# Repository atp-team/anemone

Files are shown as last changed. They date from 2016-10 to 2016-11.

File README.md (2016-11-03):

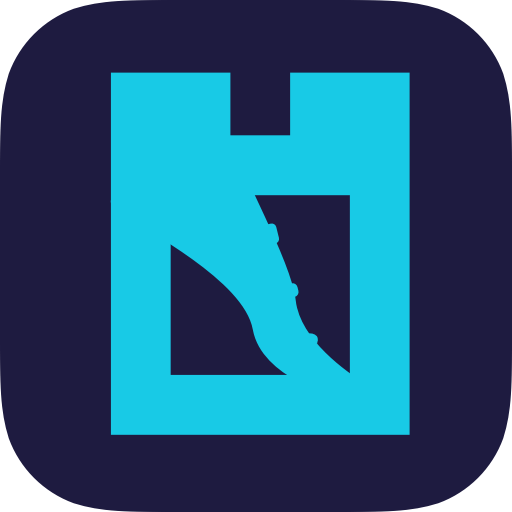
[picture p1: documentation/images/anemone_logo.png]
Anemone Platform


> "Look at you hacker, in order to use me, you must understand first." -- Anemone

## Introducing the Platform

Anemone is an open platform which allows you to experiment with *Internet of Things*. Anemone allows you to easily **build open hardware device** and to **create a simple apps** which will run *both in cloud and on mobile devices*.

First take a look at our website [http://www.anemone.cloud](http://www.anemone.cloud).

Then continue reading.

*[#anemoneCloud](https://twitter.com/hashtag/anemoneCloud)*

## Platform ecosystem

Anemone ecosystem consists of:

* **Anemone Overview** (you are reading it now)
* **Anemone Platform** which consists of:
  * [Anemome Cloud](http://www.anemone.cloud) 
  * **Anemone Mobile Client** iOS & Android apps (you can download them from [www.anemone.cloud](http://www.anemone.cloud))
  * [Anemone Tentacle](https://github.com/ceskasporitelna/anemone/blob/master/documentation/HowToBuildAnemoneTentacle.md) open hardware device you can build and 3D print
* [Anemone Documentation](https://github.com/ceskasporitelna/anemone/tree/master/documentation) where you can read everything you need to know
* [Anemone Toolkit](https://github.com/ceskasporitelna/anemone/tree/master/toolkit) which you need in order to create a Tentacle or build Anemone App
* [Anemone Apps Repository](https://github.com/ceskasporitelna/anemone/tree/master/apps)
* [Anemone Cloud Connectors List](https://github.com/ceskasporitelna/anemone/tree/master/connectors)

More information about the Anemone Platform are provided below.

## Platform architecture

Anemone has three main parts:

* Mobile Client
* Cloud
* Tentacle

**Mobile Client** is iOS and Android application which allows you to manage *Tentacles* and control *Anemone Apps*. You can download it for free from Apple AppStore and Google Play Store. Both links are on our website [http://www.anemone.cloud](http://www.anemone.cloud).

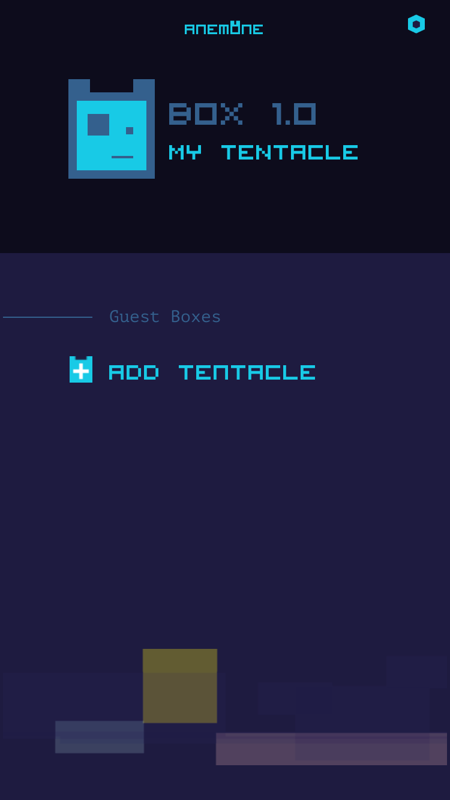
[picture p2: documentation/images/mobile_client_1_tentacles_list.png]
Anemone Mobile Client - List of Tentacles
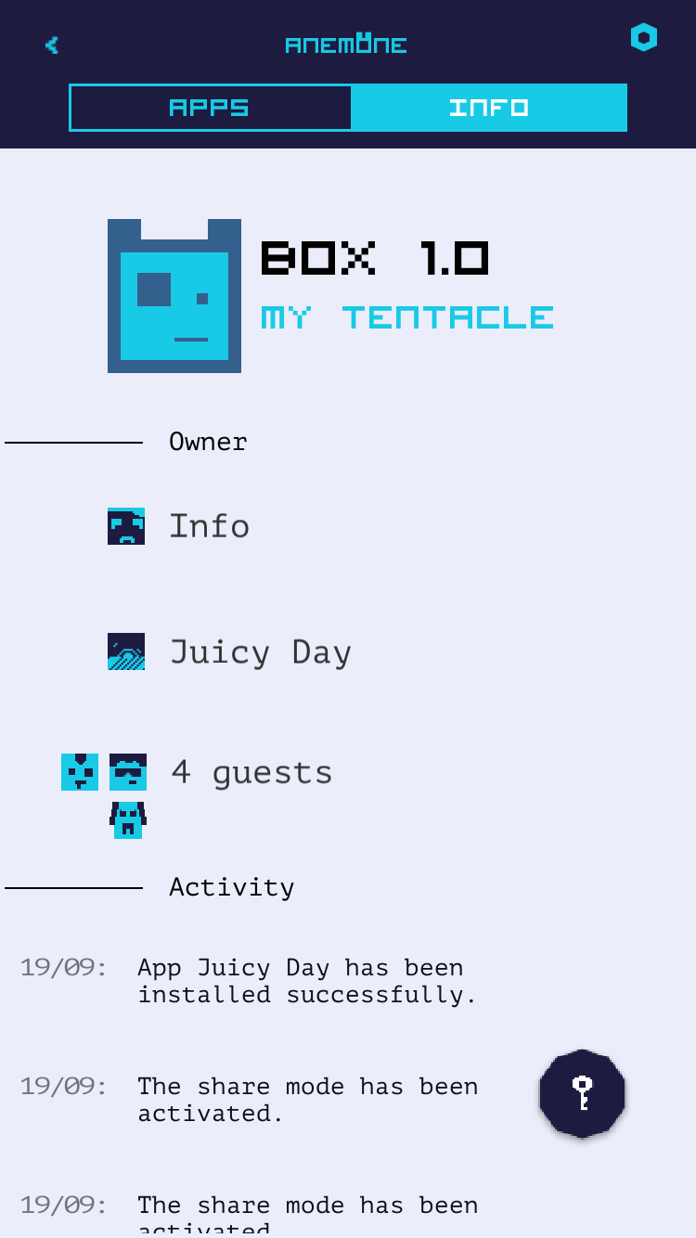
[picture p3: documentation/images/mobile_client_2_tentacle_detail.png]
Anemone Mobile Client - Tentacle Detail
 

**Cloud** is the final component of the platform which connects the Tentacles to the Mobile Client. But that is not all. The Anemone Cloud can connect both the Mobile Client and Tentacles to other API service on the internet using **Connectors**.

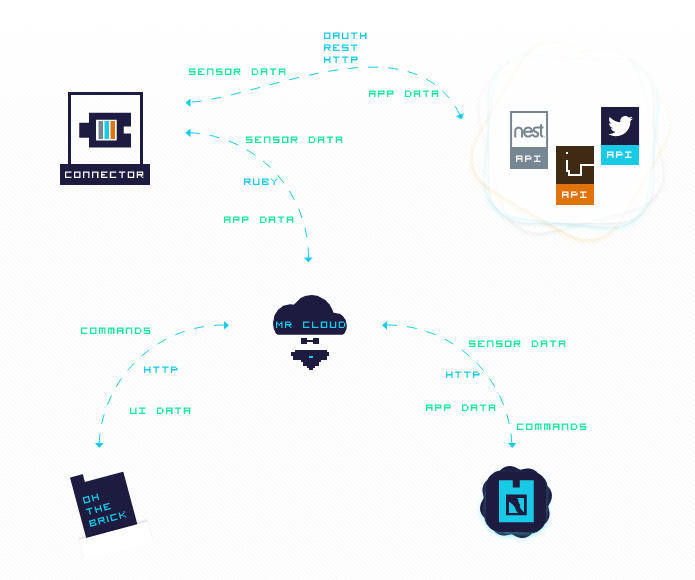
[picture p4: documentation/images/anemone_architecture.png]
Anemone Platform Architecture


**Tentacle** is open hardware device based on Arduino YÚN which is the *Internet of Things* part the our platform. You can either *connect as a guest* to a Tentacle of your friend, or you can *build your own* (which will recognize you as its master).

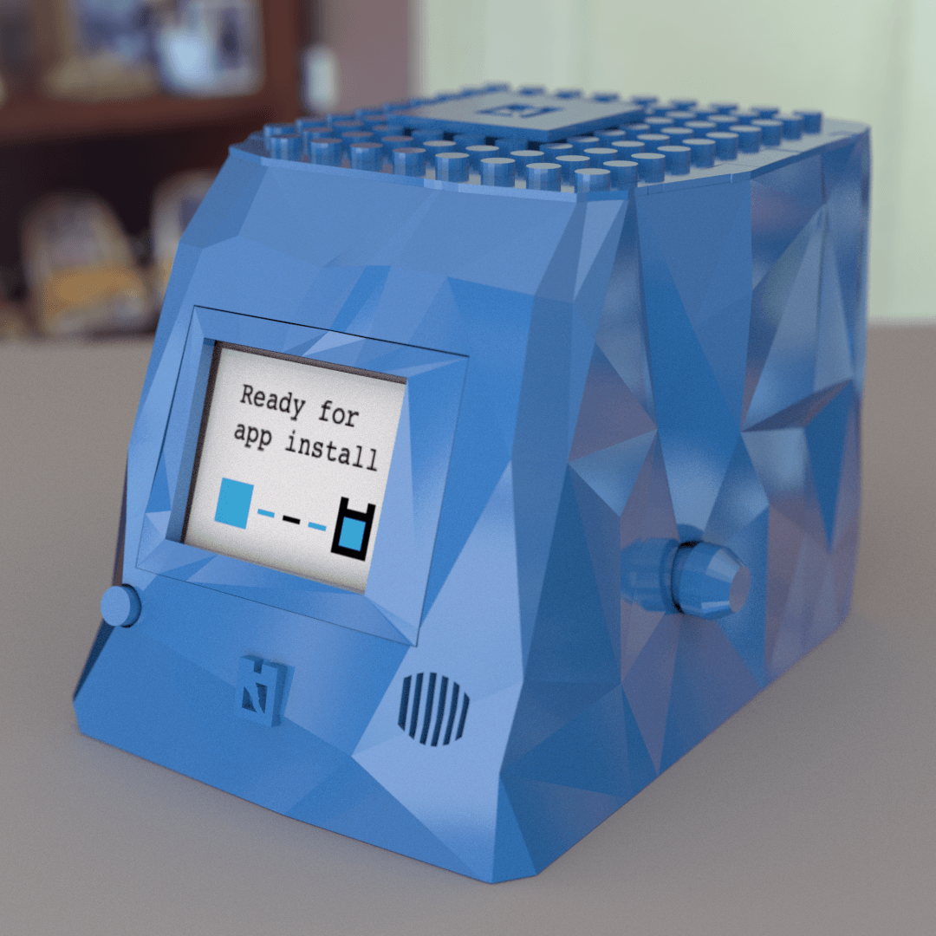
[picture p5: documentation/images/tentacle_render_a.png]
Anemone Tentacle - View from Right
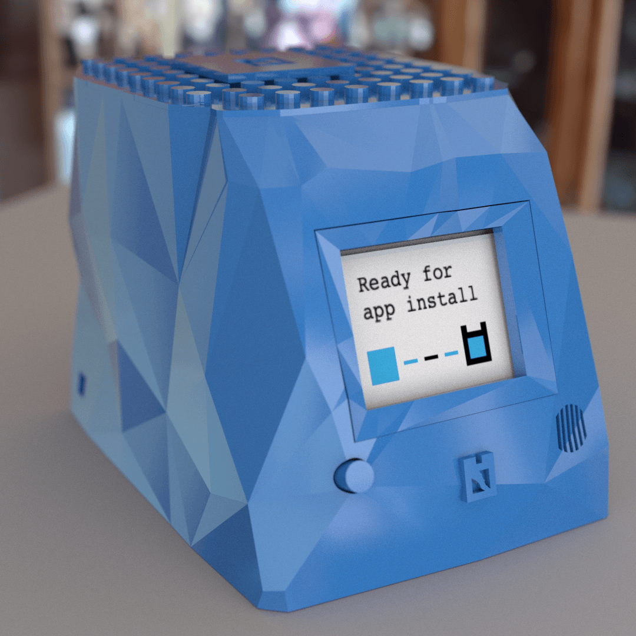
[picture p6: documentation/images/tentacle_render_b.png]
Anemone Tentacle - View from Left
 

The *Cloud*, *Mobile Client* and *Tentacle* together form a platform where **Anemone Apps** can run.

And *Anemone Apps* are here for you *to use them*, *to develop them* and mainly **to have some fun with them**.

## What can be achieved with the platform?

With Anemone Platform you can do the following:

* You can display textual information from the the Anemone Cloud on Tentacle display *(information is stored inside variables in the cloud component of Anemone app)*
* Tentacle can change value of variable of it's app cloud component (eg. when some button on the Tentacle is pressed or when some data is measured)
* You can create so called "Anemone Apps" which contains variables which can be shown on Tentacle display and/or in the Mobile Client app. You can let user enter some data using his mobile phone, adjust this data in the cloud and show result on the Tentacle. Or you can let user interact with the Tentacle and process this interaction in the cloud and show the result in the mobile app.
* The platform is done in a way that owner of a Tentacle can share it to his friend or change the running Anemone App using the OTA *(Over-The-Air)* update.

> The **Anemone Platform is completely OPEN**. Everybody can [become a user by signing up for free](http://www.anemone.cloud/users/sign_up). Every user can either receive a guest access or can [build his own](https://github.com/ceskasporitelna/anemone/blob/master/documentation/HowToBuildAnemoneTentacle.md) Tentacle. One can then install some apps from our [public repository of Anemone Apps](https://github.com/ceskasporitelna/anemone/tree/master/apps) or he can [create his own app](https://github.com/ceskasporitelna/anemone/blob/master/documentation/HowToMakeAnemoneApp.md).

## How it works? 

> Main goal of Anemone Platform is to provide a place where *Anemone Apps* can live.

Anemone App is a tiny piece of software which can be **built by you**. We have designed the Anemone platform in a way that it will be extremely easy for you to make new Anemone Apps.

### What is Anemone App?

Anemone app is every application which runs on the Anemone platform.

Every Anemone app has three components:

* Mobile User Interface
* Cloud Logic
* Tentacle User Interface and Logic

Every of these three components of an Anemone App runs in one part of Anemone platform:

* **Mobile User Interface** runs in the *Mobile Client* app
* **Cloud Logic** runs in the *Cloud*
* **Tentacle User Interface and Logic** runs on the *Tentacle*

When you create these three components you have successfully created an *Anemone App*. Every Anemone App is **explicitly defined by these three components**.

* *Mobile User Interface* is defined by an **interface.json** file
* *Cloud Logic* is defined by an **manifest.json** file
* *Tentacle User Interface and Logic* is defined by **arduino .ino sketch** which uses our *Anemone arduino library*

#### Mobile User Interface (interface.json)

The *interface.json* file describes list of **input** and **output** components which together form the user interface of Anemone App which is shown inside the Mobile Client when your Anemone App is open.

Through this interface you can either read data from your Anemone App or provide data input. All data are in fact loaded and stored in the Anemone Cloud (from where the Tentacle will load them).

When defining the Anemone App Mobile User Interface you can use set of prepared components.

Interface of your Anemone App can look like this:

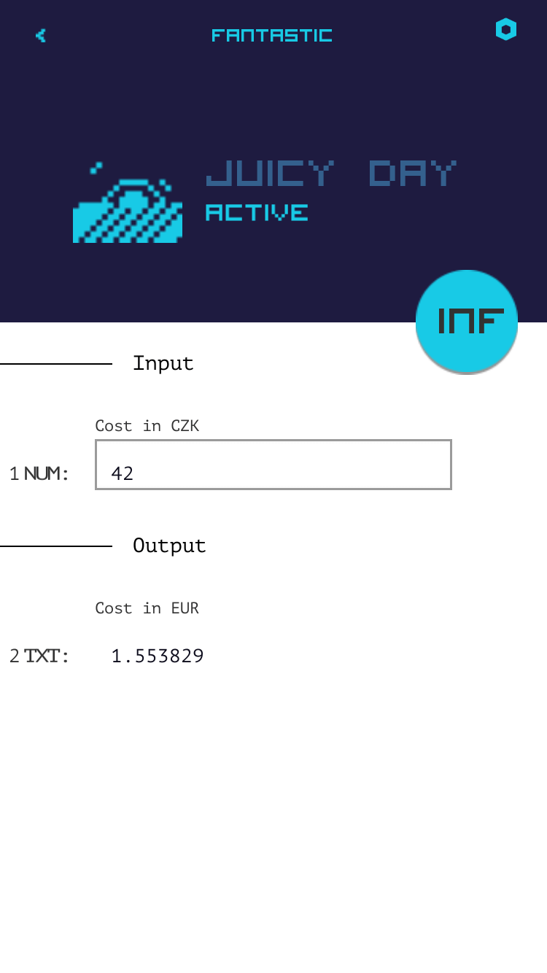
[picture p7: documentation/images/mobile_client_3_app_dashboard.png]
Anemone App Interface Example


In order to make this Mobile User Interface, you need to create an **interface.json** file which can look like this:

```json
{
  "platform": {
    "appId": "juicy-day",
    "driver": "anemone",
    "type": "interface",
    "version": 1
  },
  "input": {
    "inCostCzk": {
      "type": "numberField",
      "label": "Cost in CZK"
    }
  },
  "output": {
    "outCostEur": {
      "type": "numberLabel",
      "label": "Cost in EUR"
    }
  }
}
```

> You can find more information about creation of *interface.json* files for Anemone Apps in our [How to define Anemone App User Interface in interface.json](https://github.com/ceskasporitelna/anemone/blob/master/documentation/HowToMakeAnemoneApp.md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) tutorial.

#### Cloud Logic (manifest.json)

The *manifest.json* file describes list of **variables** and **bindings** which together form the cloud component of every *Anemone App*.

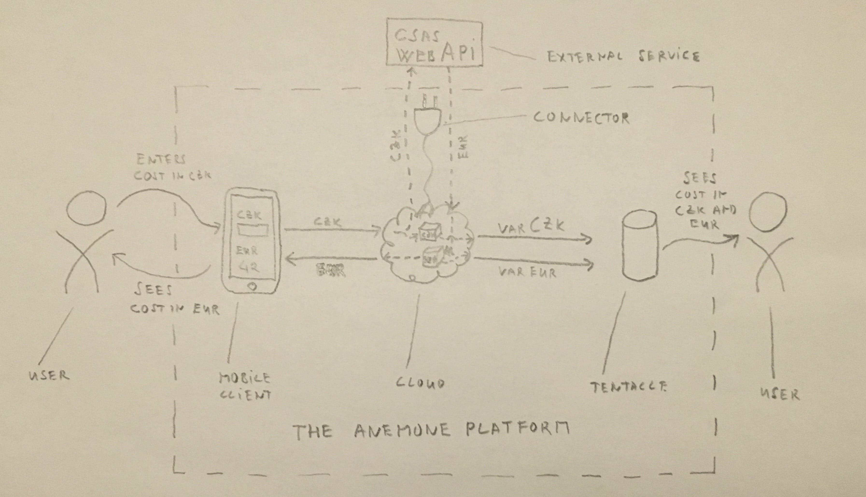
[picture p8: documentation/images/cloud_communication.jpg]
Anemone App Communication Schema


##### Variables

Every *variable* has a **name** and **data type**. And in addition an information whether it is **readable** (get) or **writeable** (set) from the *Tentacle* (the readability and writeablity from the Mobile Client is defined on other place of the *manifest.json* - in *bindings*).

```json
{
  "variables": {
    "varCostCzk": {
      "dataType": "float",
      "get": true,
      "set": false
    },
    "varCostEur": {
      "dataType": "float",
      "get": true,
      "set": false
    }
  }
}
```

##### Bindings

The second part of the *manifest.json* file contains the list of bindings. There are two types of bindings - user **interface** bindings and cloud **connectors** bindings.

```json
{
  "bindings": {
    "interface": {
    },
    "connectors": {
    }
  }
}
```

User interface bindings (defined inside the "interface" section) describe **bindings of variables to user interface components of Mobile User Interface** defined in *interface.json*.

```json
{
  "bindings": {
    "interface": {
      "bindCostInCzk": {
        "variable": "varCostCzk",
        "from": "inCostCzk"
      },
      "bindCostInEur": {
        "variable": "varCostEur",
        "to": "outCostEur"
      }
    },
  }
}
```

The connectors bindings (defined inside the "connectors" section) describe **bindings of variables to Anemone Cloud Connectors**.

Connector is a component of Anemone Cloud which provides access to other web services (like Twitter of CSAS WebAPI).

Connectors are integrated in the Anemone Cloud. List of all existing connectors can be found [here](https://github.com/ceskasporitelna/anemone/tree/master/connectors). You can [create new connectors based on our manual](https://github.com/ceskasporitelna/anemone/blob/master/documentation/HowToMakeAnemoneConnector.md).

The connector definition looks like this:

```json
{
  "bindings": {
    "connectors": {
      "exchangeRate": {
        "connector": "exchangeRate",
        "variable": "varCostCzk",
        "args": {
          "apiKey": "INSERT YOUR API KEY HERE"
        },
        "output": {
          "variables": [
            "varCostEur"
          ]
        }
      }
    }
  }
}
```

The complete *manifest.json* file can look like this:

```json
{
  "platform": {
    "appId": "juicy-day",
    "driver": "anemone",
    "type": "manifest",
    "version": 1
  },
  "variables": {
    "varCostCzk": {
      "dataType": "float",
      "get": true,
      "set": false
    },
    "varCostEur": {
      "dataType": "float",
      "get": true,
      "set": false
    }
  },
  "bindings": {
    "interface": {
      "bindCostInCzk": {
        "variable": "varCostCzk",
        "from": "inCostCzk"
      },
      "bindCostInEur": {
        "variable": "varCostEur",
        "to": "outCostEur"
      }
    },
    "connectors": {
      "exchangeRate": {
        "connector": "exchangeRate",
        "variable": "varCostCzk",
        "args": {
          "apiKey": "INSERT YOUR API KEY HERE"
        },
        "output": {
          "variables": [
            "varCostEur"
          ]
        }
      }
    }
  }
}
```

> You can find more information about creation of *manifest.json* files for Anemone Apps in our [How to define Anemone App Logic in manifest.json](https://github.com/ceskasporitelna/anemone/blob/master/documentation/HowToMakeAnemoneApp.md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) tutorial.

#### Tentacle User Interface and Logic (arduino .ino sketch) 

The last component of Anemone App is the one which will run on a Tentacle.

This component is in fact an **arduino .ino sketch** file which runs on the *Arduino YÚN* and is "the brain" of the Tentacle.

In order to make the development of Anemone sketches easier, we have prepared the [anemone arduino library](https://github.com/ceskasporitelna/anemone/tree/master/toolkit/anemone-arduino-library) and default [Tentacle user interface components and screens](https://github.com/ceskasporitelna/anemone/blob/master/documentation/HowToMakeAnemoneApp.md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).

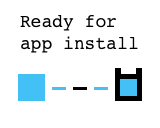
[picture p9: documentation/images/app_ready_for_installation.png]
Anemone Tentacle UI - Ready for app installation
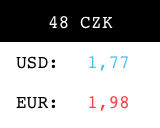
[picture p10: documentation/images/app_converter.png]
Anemone Tentacle UI - Juicy Day Currency Converter
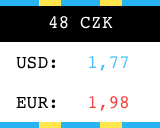
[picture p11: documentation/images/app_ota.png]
Anemone Tentacle UI - OTA Update in progress
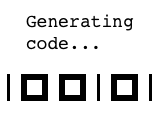
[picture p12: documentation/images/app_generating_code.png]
Anemone Tentacle UI - Generating guest code
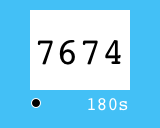
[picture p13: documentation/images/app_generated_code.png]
Anemone Tentacle UI - Share mode
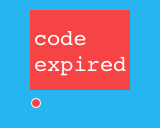
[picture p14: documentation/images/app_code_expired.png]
Anemone Tentacle UI - Guest code expired
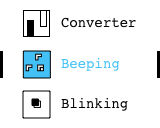
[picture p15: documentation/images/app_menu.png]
Anemone Tentacle UI - Menu
      

> You can find more information about creation of *arduino sketch* files for Anemone Apps in our [How to create Anemone App Sketch in Arduino IDE](https://github.com/ceskasporitelna/anemone/blob/master/documentation/HowToMakeAnemoneApp.md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) tutorial.

## This looks Awesome! How can I start?

You can use the Anemone platform either as a **User** or as a **Developer**.

In order to start *as a User*, all you need to do is:

1. [Sign up](http://www.anemone.cloud/users/sign_up) for free on the Anemone platform website. Select your account avatar while doing so (by a name of the icon only - that is the real fun!)
2. Download the **Mobile Client app for iOS or Android** (you can find links to apps on our website [http://www.anemone.cloud](http://www.anemone.cloud))
3. Find some **Tentacle** which you would like to control. In order to control a Tentacle, you need to either *own it* (which means to [build it](https://github.com/ceskasporitelna/anemone/blob/master/documentation/HowToBuildAnemoneTentacle.md) first), or be invited to it *as a guest*
4. Take a full control of the Tentacle. You can **control the running app** as both guest and owner. Or **switch the running app** for another one or **trigger Tentacle share mode** as owner.  Both can be done from the Mobile Client or Cloud administration

When starting *as a Developer* do the following:

1. [Sign up](http://www.anemone.cloud/users/sign_up) for free on the Anemone platform website. Select your account avatar while doing so *(by a name of the icon only - that is only way which contains the real fun!)*
2. Download the **Mobile Client app for iOS or Android** (you can find links to apps on our website [http://www.anemone.cloud](http://www.anemone.cloud))
3. [Build](https://github.com/ceskasporitelna/anemone/blob/master/documentation/HowToBuildAnemoneTentacle.md) a **Tentacle**. Every real developer has its own Tentacle 
4. [Make an Anemone app](https://github.com/ceskasporitelna/anemone/blob/master/documentation/HowToMakeAnemoneApp.md). Prepare the *interface.json*, *manifest.json* and *arduino sketch* .hex files for your application. Login to the cloud administration **and add your first Anemone app**
5. **Install the app on your Tentacle** via *OTA* from cloud administration (by pressing a Install button)
5. **Test the app** on your Tentacle when being in a *sandbox* mode.
6. **Submit the app for approval** to the public apps repository via button in the cloud administration
7. The anemone team will review and **approve the app**
8. Every user of the platform can **download the app and use it**
9. Congratulations - you are now Anemone apps developer. **The world is yours**!

## I want more of it! - What to do next?

1. Check out our [website](http://www.anemone.cloud)
2. [Sign up](http://www.anemone.cloud/users/sign_up) for free and [download the Mobile Client](http://www.anemone.cloud)
3. Read the [How to build Anemone Tentacle](https://github.com/ceskasporitelna/anemone/blob/master/documentation/HowToBuildAnemoneTentacle.md) tutorial
4. Read the [How to make Anemone App](https://github.com/ceskasporitelna/anemone/blob/master/documentation/HowToMakeAnemoneApp.md) tutorial, or directly
	1. [How to define Anemone App Logic in manifest.json](https://github.com/ceskasporitelna/anemone/blob/master/documentation/HowToMakeAnemoneApp.md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)
	2. [How to define Anemone App User Interface in interface.json](https://github.com/ceskasporitelna/anemone/blob/master/documentation/HowToMakeAnemoneApp.md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)
	3. [How to create Anemone App Sketch in Arduino IDE](https://github.com/ceskasporitelna/anemone/blob/master/documentation/HowToMakeAnemoneApp.md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)
5. Read the [How to make Anemone Connector](https://github.com/ceskasporitelna/anemone/blob/master/documentation/HowToMakeAnemoneConnector.md) tutorial
6. You may be also interested in the [Anemone Apps Repository](https://github.com/ceskasporitelna/anemone/tree/master/apps), [List of available Anemone Connectors](https://github.com/ceskasporitelna/anemone/tree/master/connectors) and [Anemone Arduino Library documentation](https://github.com/ceskasporitelna/anemone/tree/master/toolkit/anemone-arduino-library)
7. Explore the "Juicy Day" [example Anemone App on our GitHub](https://github.com/ceskasporitelna/anemone/tree/master/apps/juicy-day)
8. Write us. Tweet about us, write on Facebook, make a blogpost. Use hashtag *[#anemoneCloud](https://twitter.com/hashtag/anemoneCloud)*.

## Who Is Behind This?

Anemone platform is a result of cooperation between [Honza Sechovec](https://twitter.com/jansechovec) and [Juicymo](http://www.juicymo.cz).

It could never be created without support of guys from [Česká Spořitelna](https://developers.csas.cz)

Anemone has been created with love in Prague.

In case of any question or issue, feel free to add a GitHub Issue in this repository.

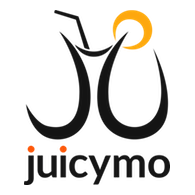
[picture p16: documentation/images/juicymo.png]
Juicymo - Mobile Apps Development


### Special thanks

For their great effort we owe a BIG thank to the following people and entities from the joint project development team (everybody did *a lot more* then what was expected from him):

* *[Pedro Pinto da Silva](http://pedropintosilva.com)* for the outstanding graphical design of the entire platform including website, mobile app, Arduino app UI and infographics. This platform design has a story.
* *[Martin Svoboda](https://github.com/svobom57)* for the development of Anemone Cloud Ruby on Rails application, manifest and interface JSON parsers and database.
* *[Šimon Kautský](https://twitter.com/SimonKautzky)* for the development of Anemone Mobile Client app both for iOS and Android in Unity3D and for solving all these ugly platform specific bugs.
* *[Filip Bursík](#)* for the development of Arduino part of Anemone platform in C and for all those dreamless nights when the program did not fit the small Arduino YÚN memory.
* *[Michal Mlejnek](https://github.com/chaemil)* for the huge amount of Anemone Tentacle 3D case model iterations in Blender - including the final one which you can print and enjoy.
* *[Jana Moudrá](https://github.com/Janamou)* for coding the Anemone platform presentational website (the one at [http://www.anemone.cloud](http://www.anemone.cloud)). Fully responsive with all the cute JS features.
* *[Honza Sechovec](https://github.com/jsechovec)* for the vision, guidance and mainly for the patience. The development of the platform took a bit longer than expected, but the result is worth it.
* *[Tomáš Jukin](http://github.com/Inza)* for the platform architecture and the fact that all the stuff fits well together. And for the ugly electronical stuff, the documentation, slicing, soldering and 3D printing.
* *Kanárek* (which is a [Prusa3D i3 MK2 3D printer](http://www.prusa3d.cz/#i3-printer)) for printing every single iteration of the Anemone Tentacle 3D case model and still work.

### Used technologies

> "They say great science is built on the shoulders of giants." -- Cave Johnson

Anemone Platform is build using well known technologies you should not miss. 

* Anemone Tentacle is an Open Hardware device build around on the Arduino YÚN and Arduino TFT Display.
* Anemone Cloud is created using Ruby on Rails
* Anemone Mobile Client is programmed in Unity

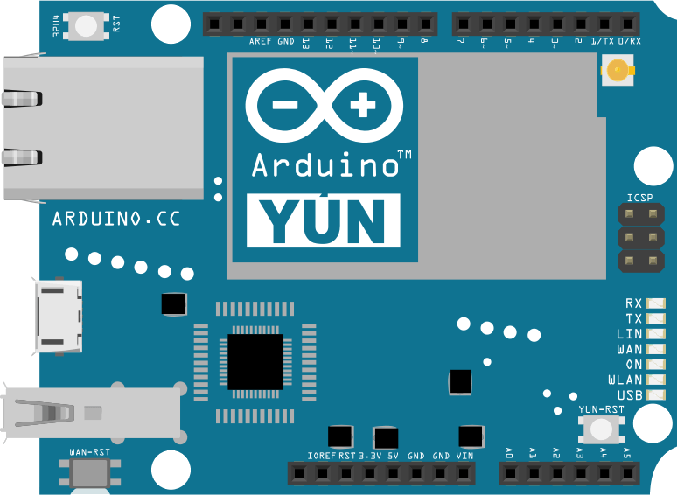
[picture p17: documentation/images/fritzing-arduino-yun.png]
Arduino YÚN
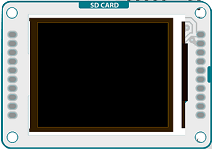
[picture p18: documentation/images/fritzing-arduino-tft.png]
Arduino TFT Display
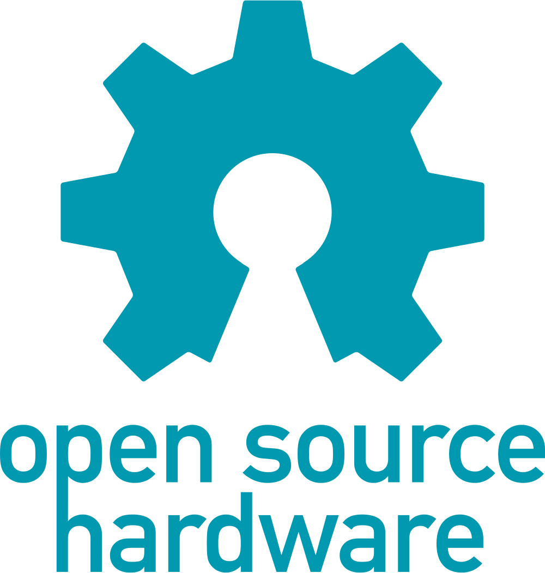
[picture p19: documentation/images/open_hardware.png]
Open Hardware
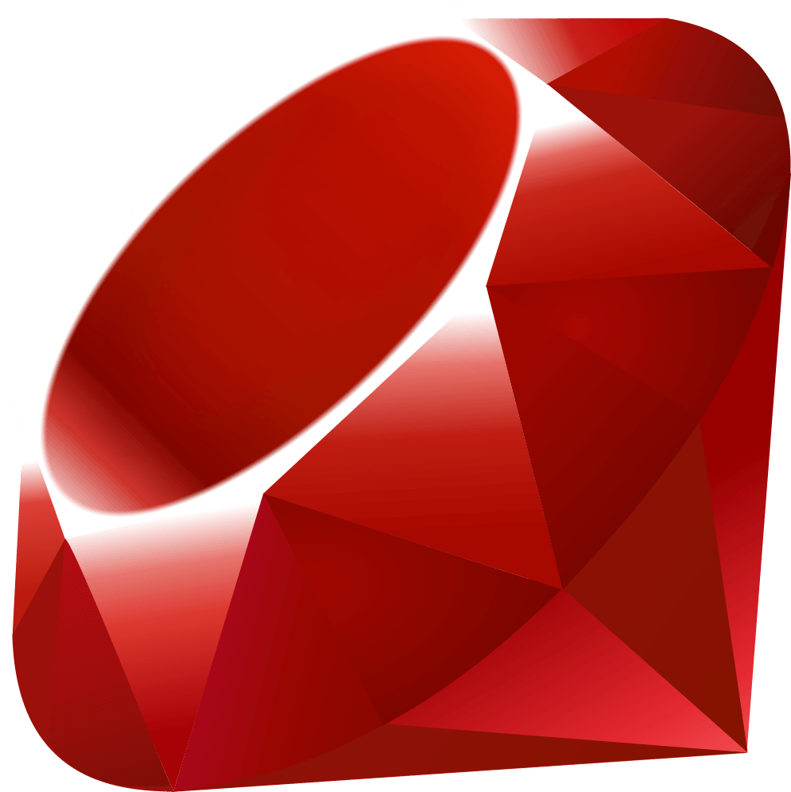
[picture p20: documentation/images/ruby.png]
Ruby
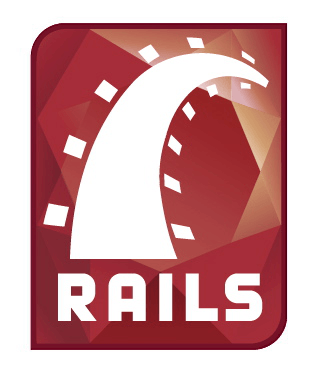
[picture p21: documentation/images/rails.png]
Rails
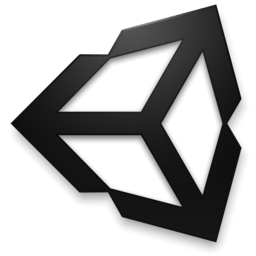
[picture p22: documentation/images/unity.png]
Unity
     

## How can I contribute?

1. Join the platform! Either as a User or Developer, you can join the Anemone platform and explore the world of IoT in a fun way. See [http://www.anemone.cloud](http://www.anemone.cloud).
2. Spread the word! I you know somebody who might be interested in our platform invite him ale show him your Tentacle.
3. Make your own apps based on [manual](https://github.com/ceskasporitelna/anemone/blob/master/documentation/HowToMakeAnemoneApp.md).
4. Make new connectors and submit them as pull requests to this repository.
5. Interested in serious development? Wanna extend the platform itself? Contact Honza at honza@flexer.cz.

## FAQ

### I plugged my Tentacle, but it has blank screen and it "is not doing anything". How to solve this?

> Arduino YÚN is a terribly slow device. So when you turn it on (typicaly by plugining in the USB cable), it will just turn on the green LED an do nothing. In this time the Arduino YÚN Linux/WiFi part is booting up. When this will finish, the ÝUN will turn on a white LED (this can took up to 5 mins). And this is the moment when it will start the Arduino sketch ans hence your Anemone App as well.
> 
> After the initial setup a so called "Initial Arduino Sketch" is installed on your Tentacle by the tentacle.sh script you have downloaded from the Anemone Cloud Admin. This sketch just shows the "Ready for app install" text and image.
> 
> Anemone Tentacle UI - Ready for app installation
> 
> After 60 seconds, the "Initial Arduino Sketch" will try to perform an OTA update.
> 
> Because the hardware limitations of the Arduino YÚN *(especially the way how the SPI bus is wired to the ICSP pins on YÚN)*, the TFT screen needs to be turned off prior an OTA update. This is why the screen goes black when OTA update is in progress.
> 
> And because Arduino YÚN is quite slow, the OTA update can take up to 5 minutes event on fast internet connection.
> 
> So the solution of this is **just wait till the OTA update will complete**. Your app will run after it.*

**We know that this is not the best user-friendly behavior and we are working on a possible solution which could make this better in future. So have crossed for us fingers...*

### My Tentacle freezed and it is not responding to anything. How to fix this?

> Arduino YÚN is able to **very often corrupt its memory and completely freeze**. *The Anemone platform is prepared to this* and in this case you can save the situation by performing the following:
> 
> 1. Try to SSH to your Tentacle, if that is still possible, run there the Tentacle initialization script (`tentacle.sh`) again (if you do not have it, feel free to download it again from Anemone Cloud). The `tentacle.sh` is designed to be [idempotent](https://en.wikipedia.org/wiki/Idempotence) *(which simply means that it is OK to run it multiple times)*. `tentacle.sh` will initialize the Tentacle once again, and once again will install the *Initial Sketch*. But after 60s in its update period the *Initial Sketch* will automatically detect that some Anemone App is already installed on the Tentacle and will automatically perform the OTA to it. And because the Anemone App state *(= its variables)* is always stored in Anemone Cloud, your app will be back up with all its data. This should solve your issue.
2. If the hints from step 1. did not help *(probably because the Tentacle/Arduino YÚN is no longer responding to anything, including SSH)*, try to turn the Tentacle off and on (by cutting power to it - do not rely on the onboard reset buttons). When you plug it to power again, wait till the Arduino YÚN completes its booting - it will turn on the **white LED** on its surface - **it takes around 5 mins**. Now your Tentacle might resume its normal operations (that means that your Anemone App should boot up). If not, try if at least the SSH is working and follow instructions from step 1.
3. If even hints from step 2. were not helpful, your Arduino YÚN went completely stuck *(this happened multiple times to us durring the development of the platform ;))*. In this case nothing else than a **YÚN linux image reset** will help you. Follow instructions on the [official tutorial how to reset Arduino YÚN linux image](https://www.arduino.cc/en/Tutorial/YunSysupgrade). That usually helps. When done, follow with instructions from the step 1.

### How can I connect to a Tentacle as a Guest?

> You need to access the Tentacle physically and press the *cloud button* (located below the left bottom corner of the screen). Or you can convince the Tentacle owner to press the *key button* in his Mobile Client app on his Tentacle info page.

> This will initiate a **share mode** of the Tentacle. When in this mode, Tentacle will show a four digit guest code on its screen - eg. 1234.

> When you physically access a Tentacle in share mode, you can type its guest code to your Mobile Client app (after pressing the *Add Tentacle* button on the dashboard).

> The Tentacle will now appear in your Mobile Client under the *Guest Boxes* label. You can now control the *Anemone App* which is running on it.

### How can I build a Tentacle?

> Just follow our [manual](https://github.com/ceskasporitelna/anemone/blob/master/documentation/HowToBuildAnemoneTentacle.md). It includes a *part list* and even a *model of cute case* which can be 3D printed! All the difficult stuff is done, what remains are just the fun parts ;).

## Terms and License

This software is licensed under [MIT license](https://github.com/ceskasporitelna/anemone/blob/master/LICENSE.md).

*[#anemoneCloud](https://twitter.com/hashtag/anemoneCloud)*

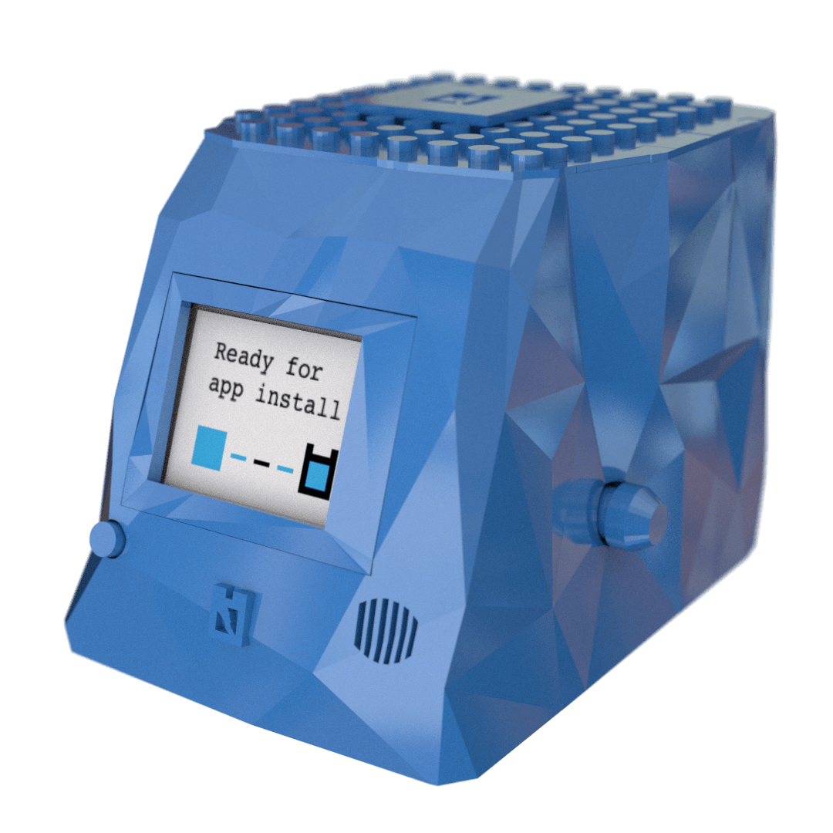
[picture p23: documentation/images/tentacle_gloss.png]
Anemone Tentacle


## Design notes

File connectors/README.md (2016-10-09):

# Anemone Cloud Connectors List

Here is a continuously updated list of all available *Anemone Connectors*.

## [Exchange Rate Anemone Connector](https://github.com/ceskasporitelna/anemone/tree/master/connectors/exchange_rate)

Exchange Rate Anemone Connector is a connector which performs currency conversion from `CZK` to `EUR` and `USD`.

It is using the [CSAS WebAPI](https://developers.csas.cz/) conversion service.

### Summary

| Name | Web Service | Input | Output |
|:---- |:---:|:---:|:---:|
| exchangeRate | [CSAS WebAPI](https://developers.csas.cz/) | czk: *float* | eur: *float*, usd: *float* |

### Authentication

[CSAS WebAPI](https://developers.csas.cz/) API key is required for authentication.

### Usage

```json
"connectors": {
  "exchangeRate": {
    "connector": "exchangeRate",
    "variable": "varCostCzk",
    "args": {
      "apiKey": "INSERT YOUR API KEY HERE"
    },
    "output": {
      "variables": [
        "varCostEur",
        "varCostUsd"
      ]
    }
  }
}
```

## Your Connector?

Do you want to have your connector here too? It is easy!

Just take a look at our [How to make Anemone Connector](https://github.com/ceskasporitelna/anemone/blob/master/documentation/HowToMakeAnemoneConnector.md) tutorial, create your own connector and submit a pull request to this repository.

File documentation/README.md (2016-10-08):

# Anemone Documentation

The Anemone documentation consists of the following:

* [How to start](https://github.com/ceskasporitelna/anemone/tree/master/toolkit/anemone-arduino-library) is a tutorial which will introduce you to the platform itself and provides instructions how to start and what should be your next steps
* [How to build Anemone Tentacle](https://github.com/ceskasporitelna/anemone/blob/master/documentation/HowToBuildAnemoneTentacle.md) is a tutorial which will guide you through the building your own Anemone Tentacle Open Hardware Device
* [How to print Anemone Tentacle Case](https://github.com/ceskasporitelna/anemone/blob/master/documentation/HowToPrintAnemoneTentacleCase.md) is a tutorial which will disclose how to 3D print nice and cute case for your Tentacle
* [How to make Anemone App](https://github.com/ceskasporitelna/anemone/blob/master/documentation/HowToMakeAnemoneApp.md) is a tutorial which will explain what a Anemone app consist of and how you can make your own
* [How to make Anemone Connector](https://github.com/ceskasporitelna/anemone/blob/master/documentation/HowToMakeAnemoneConnector.md) is a last tutorial which will conclude our little serie by explaining you how to make your very own Anemone connector - a Ruby class which can extend the Anemone Cloud connectivity to additional web services and APIs

Lets go back to [Anemone Overview](https://github.com/ceskasporitelna/anemone).

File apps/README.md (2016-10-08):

# Anemone Apps Repository

Here you can find continuously updated list of all available Anemone Apps.

## [Juicy Day](https://github.com/ceskasporitelna/anemone/tree/master/apps/juicy-day)

*Author: [Juicymo s.r.o.](http://www.juicymo.cz)*

Juicy Day is an example Anemone app build by the Anemone Team.

Juicy Day allows you to enter amount of money in the CZK currency through its Mobile Client interface. This amount is then sent to the cloud, where it is converted to USD and EUR via the *"exchangeRate"* Anemone Cloud Connector. The resulting amounts in USD and EUR are then shown to the user both on his mobile phone (in the Mobile Client) and on the Tentacle display.

On the side of a Tentacle the Juicy Day Anemone app shows all features of the Tentacle device. It contains an app dashboard where it shows information loaded from the cloud (which are the money amounts in CZK, USD and EUR). By pressing the side know, user can access the Tentacle menu, from where he can either turn on the in-build buzzer or start fading the in-build LEDs. By pressing the top back button he can go back to the app dashboard.

As every Anemone App, even the Juicy Day Anemone App contains a functionality which is required (received from the [Anemone Arduino Library](https://github.com/ceskasporitelna/anemone/tree/master/toolkit/anemone-arduino-library), which is the following:

* By pressing a *cloud button* (the one in front) user can switch Tentacle to the *share mode* in which Tentacle will generate (and show) a 4-digit guest code, which can be used by another user to access this tentacle as a *guest*.
* Share mode can be cancelled any time by pressing a back button.
* Every 60s the Tentacle is performing a synchronization with Anemone Cloud. In this moment it will sync values of all variables and check if there is a need to perform OTA update of installed Anemone App.

## [Example App](https://github.com/ceskasporitelna/anemone/tree/master/apps/example-app)

*Author: [Juicymo s.r.o.](http://www.juicymo.cz)*

Example App is a minimal example of working Anemone app build by the Anemone Team.

Example App is doing only one thing and that is showing a text "Example App" on the display.

As every Anemone App, even the Example App Anemone App contains a functionality which is required (received from the [Anemone Arduino Library](https://github.com/ceskasporitelna/anemone/tree/master/toolkit/anemone-arduino-library), which is the following:

* By pressing a *cloud button* (the one in front) user can switch Tentacle to the *share mode* in which Tentacle will generate (and show) a 4-digit guest code, which can be used by another user to access this tentacle as a *guest*.
* Share mode can be cancelled any time by pressing a back button.
* Every 60s the Tentacle is performing a synchronization with Anemone Cloud. In this moment it will sync values of all variables and check if there is a need to perform OTA update of installed Anemone App.

## Your App?

Do you want to have your app here too? It is easy!

Just take a look at our [How to make Anemone App](https://github.com/ceskasporitelna/anemone/blob/master/documentation/HowToMakeAnemoneApp.md) tutorial, create your own app, send it for review and submit a pull request to this repository.

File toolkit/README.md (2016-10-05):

# Anemone Toolkit

The Anemone toolkit consists from three things which you should to explore before building your own Anemone Tentacle or before developing your Anemone app.

* [Anemone Arduino library](https://github.com/ceskasporitelna/anemone/tree/master/toolkit/anemone-arduino-library) is arduino library used by every Anemone app sketch component
* [Anemone Tentacle 3D Model](https://github.com/ceskasporitelna/anemone/tree/master/toolkit/tentacle-3d-model) is a 3D model of Anemone Tentacle case which can be 3D printed
* [Anemone Tentacle Fritzing files](https://github.com/ceskasporitelna/anemone/tree/master/toolkit/tentacle-fritzing) contains scheme and wiring of Anemone Tentacle electronic circuit

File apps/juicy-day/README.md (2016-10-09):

# Juicy Day Anemone App

*Author: [Juicymo s.r.o.](http://www.juicymo.cz)*

Juicy Day is an example Anemone app build by the Anemone Team.

Juicy Day allows you to enter amount of money in the CZK currency through its Mobile Client interface. This amount is then sent to the cloud, where it is converted to USD and EUR via the *"exchangeRate"* Anemone Cloud Connector. The resulting amounts in USD and EUR are then shown to the user both on his mobile phone (in the Mobile Client) and on the Tentacle display.

On the side of a Tentacle the Juicy Day Anemone app shows all features of the Tentacle device. It contains an app dashboard where it shows information loaded from the cloud (which are the money amounts in CZK, USD and EUR). By pressing the side know, user can access the Tentacle menu, from where he can either turn on the in-build buzzer or start fading the in-build LEDs. By pressing the top back button he can go back to the app dashboard.

As every Anemone App, even the Juicy Day Anemone App contains a functionality which is required (received from the [Anemone Arduino Library](https://github.com/ceskasporitelna/anemone/tree/master/toolkit/anemone-arduino-library), which is the following:

* By pressing a *cloud button* (the one in front) user can switch Tentacle to the *share mode* in which Tentacle will generate (and show) a 4-digit guest code, which can be used by another user to access this tentacle as a *guest*.
* Share mode can be cancelled any time by pressing a back button.
* Every 60s the Tentacle is performing a synchronization with Anemone Cloud. In this moment it will sync values of all variables and check if there is a need to perform OTA update of installed Anemone App.

You can install Juicy Day Anemone App on your Tentacle from the Mobile Client or from the Anemone Cloud Administration.

## Screens

Anemone Tentacle UI - Juicy Day Currency Converter Anemone Tentacle UI - OTA Update in progress Anemone Tentacle UI - Menu

## Variables

Juicy Day is using 3 variables.

| Name | Datatype | Readable by Tentacle | Writeable by Tentacle |
|:---- |:---:|:---:|:---:|
| varCostCzk | float | Yes | No |
| varCostEur | float | Yes | No |
| varCostUsd | float | Yes | No |

## Connectors

Juicy Day is using 1 connector.

| Name | Web Service | Input | Output |
|:---- |:---:|:---:|:---:|
| [exchangeRate](https://github.com/ceskasporitelna/anemone/tree/master/connectors/exchange_rate) | [CSAS WebAPI](https://developers.csas.cz/) | varCostCzk | varCostEur, varCostUsd |

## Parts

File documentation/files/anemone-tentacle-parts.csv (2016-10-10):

# | Part | Where to buy in Czech Republic | Where to buy Worldwide | Cost
1x | Arduino YÚN | https://goo.gl/WWNbBz | https://goo.gl/zxKTJE | €68.20
1x | Arduino TFT LCD Display | https://goo.gl/UJ5RQx | https://goo.gl/QMAZtW | €20.90
1x | Rotary Encoder KY-040 | https://goo.gl/HBKuvv | https://goo.gl/aWtrAF | €0.50
1x | Buzzer YL-44 | https://goo.gl/Eo4EEE | https://goo.gl/2WzGYW | €0.43
1x | Microswitch TC-0108-T | https://goo.gl/ncyT34 | https://goo.gl/iff8Z7 | €0.13
1x | Red Switch P-PB303B | https://goo.gl/mJq2Rl | https://goo.gl/SXAANZ | €0.45
2x | Green Super Flux LED 913PG2C | https://goo.gl/e5RzAD | https://goo.gl/xWg07e | €0.40
2x | Optocoupler BPC-817C | https://goo.gl/SSWsRn | https://goo.gl/BFo84T | €0.30
2x | Resistor 220 Ohm | - | -
2x | Resistor 10 Kiloohm | - | -
1x | Prototype Shield with Small Breadboard | https://goo.gl/Pvyxjw | https://goo.gl/QiYypK | €1.00
1x | Stripboard Single Side PCB 5x7cm | https://goo.gl/zTTTuU | https://goo.gl/bP6dKk | €1.26
1x | RJ-11 Connector Box WEBP 6-4 LP 833-045 | https://goo.gl/p4YbLA | https://goo.gl/kE05f0 | €0.25
1x | Insulated wire on coil 04mm/25m Blue | https://goo.gl/AbCSSo | https://goo.gl/lk7bCX | €2.20
1x | Breadboard Connectors PROSKIT OP-E351 | https://goo.gl/OA5zfP | https://goo.gl/8ECFLD | €12.29
1x | Female Headers Row 40 | https://goo.gl/Ps4XRd | https://goo.gl/bsTJQJ | €0.34
1x | Male Headers Row 20 Straight | https://goo.gl/Dz5Kux | https://goo.gl/MwZm9u | €0.23
1x | Male Headers Row 20 90-deg | https://goo.gl/94bT0B | https://goo.gl/N3jrON | €0.34
1x | Jumper Cables M-M M-F F-F 40pcs 10cm | https://goo.gl/WffkiF | https://goo.gl/9HJ0Yd | €3.45
1x | Jumper Cables M-M M-F F-F 40pcs 20cm | https://goo.gl/buLGLN | https://goo.gl/QxP5vw | €2.17
 |  |  | Total | €114.84

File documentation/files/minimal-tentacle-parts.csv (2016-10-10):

# | Part | Where to buy in Czech Republic* | Where to buy Worldwide | Cost
1x | Arduino YÚN | https://goo.gl/WWNbBz | https://goo.gl/zxKTJE | €68.20
1x | Arduino TFT LCD Display | https://goo.gl/UJ5RQx | https://goo.gl/QMAZtW | €20.90
1x | Microswitch TC-0108-T | https://goo.gl/ncyT34 | https://goo.gl/iff8Z7 | €0.13
1x | Optocoupler BPC-817C | https://goo.gl/SSWsRn | https://goo.gl/BFo84T | €0.30
1x | Resistor 220 Ohm | - | -
1x | Resistor 10 Kiloohm | - | -
1x | Jumper Cables M-M M-F F-F 40pcs 20cm | https://goo.gl/buLGLN | https://goo.gl/QxP5vw | €2.17
 |  |  | Total | €91.70

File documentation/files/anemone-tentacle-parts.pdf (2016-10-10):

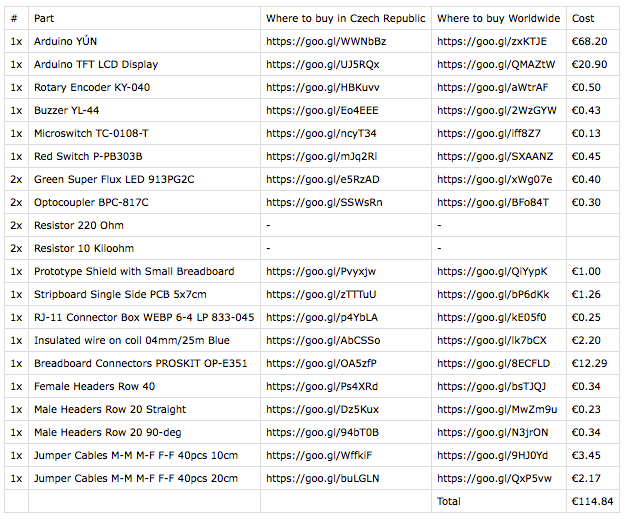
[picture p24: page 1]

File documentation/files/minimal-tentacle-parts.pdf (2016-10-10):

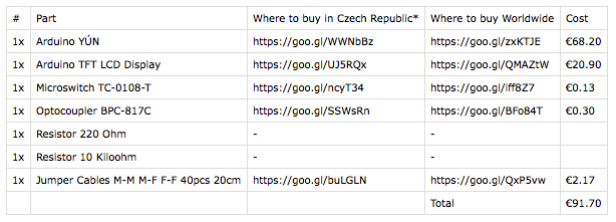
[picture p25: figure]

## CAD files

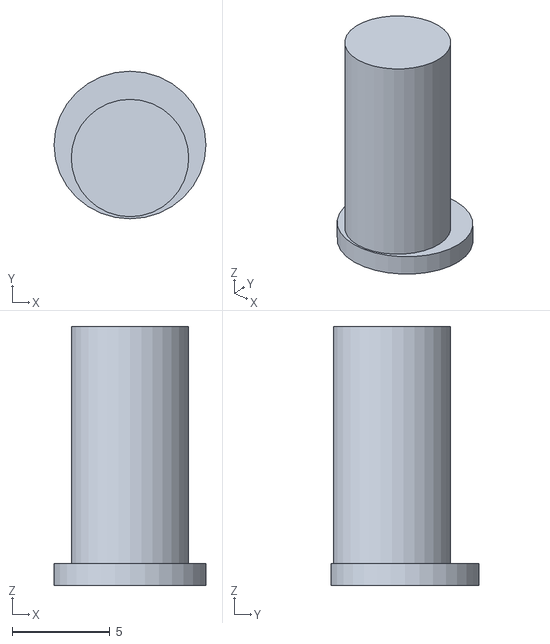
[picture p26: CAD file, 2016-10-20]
toolkit/tentacle-3d-model/export/parts/bottom_and_insides/g1_2_the_front_button.stl
7.77 x 7.55 x 13.2

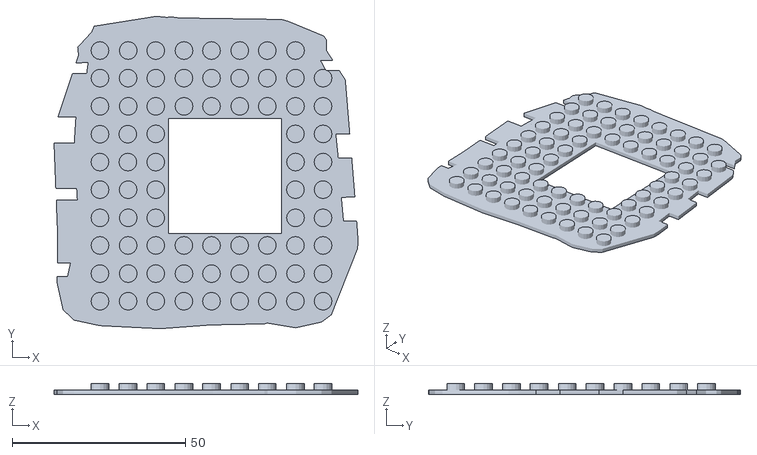
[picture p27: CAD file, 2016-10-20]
toolkit/tentacle-3d-model/export/parts/top_and_display_covers/g3_2_the_top_cover.stl
87.6 x 90.0 x 3.21

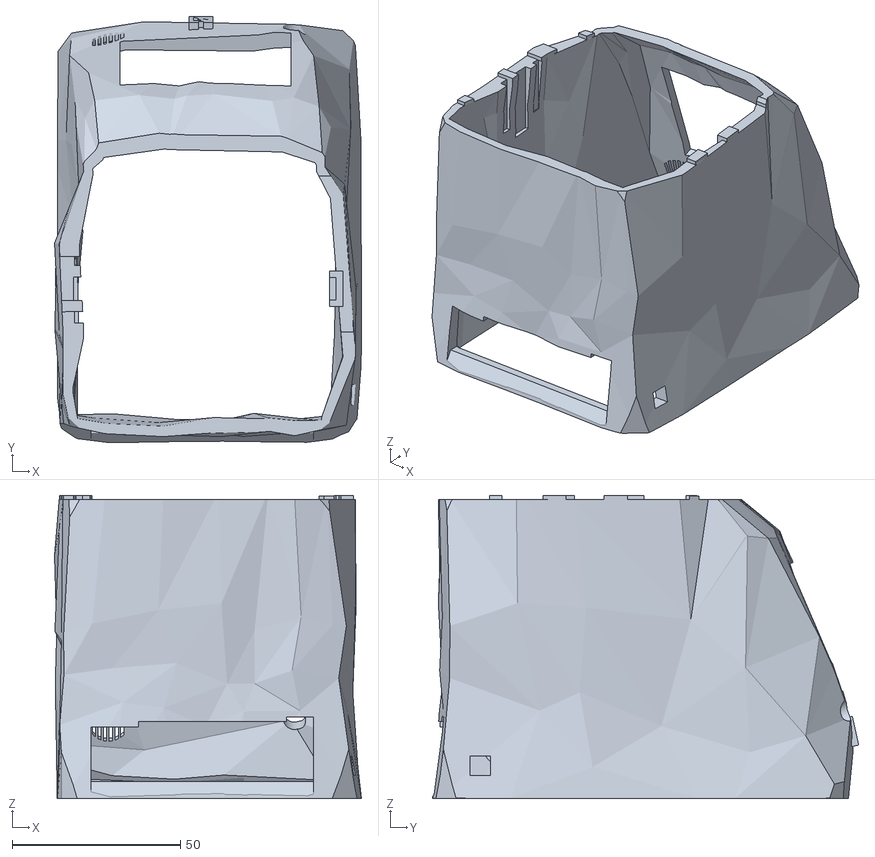
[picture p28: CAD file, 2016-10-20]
toolkit/tentacle-3d-model/export/parts/walls/g2_1_the_walls.stl
91.2 x 126.6 x 90.1

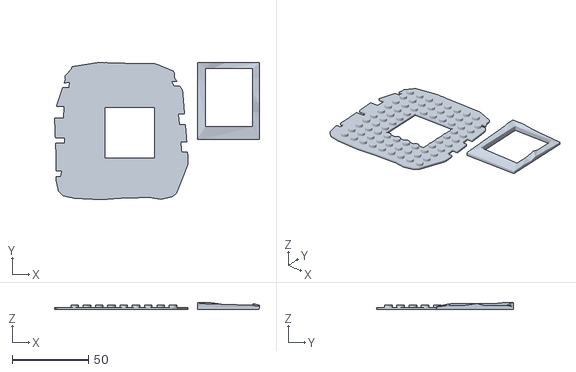
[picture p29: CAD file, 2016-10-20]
toolkit/tentacle-3d-model/export/ready-to-print/3_top_and_display_covers.stl
134.4 x 90.0 x 4.84

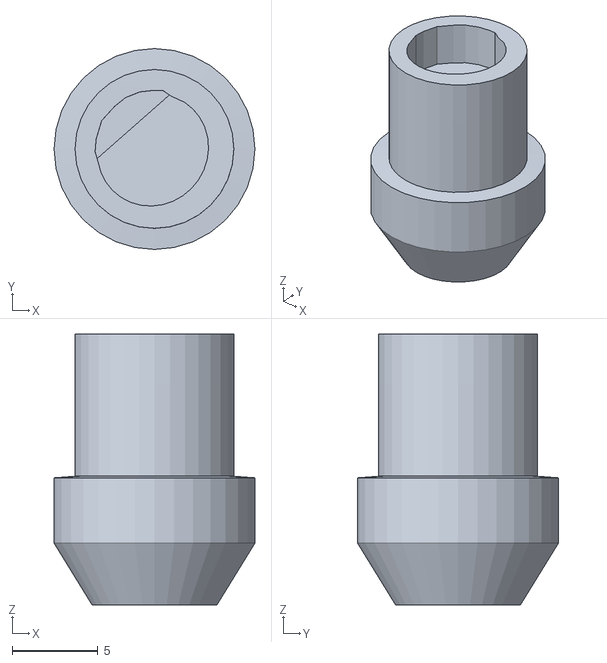
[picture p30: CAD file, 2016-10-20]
toolkit/tentacle-3d-model/export/parts/bottom_and_insides/g1_3_the_menu_knob_cover.stl
11.7 x 11.7 x 15.8

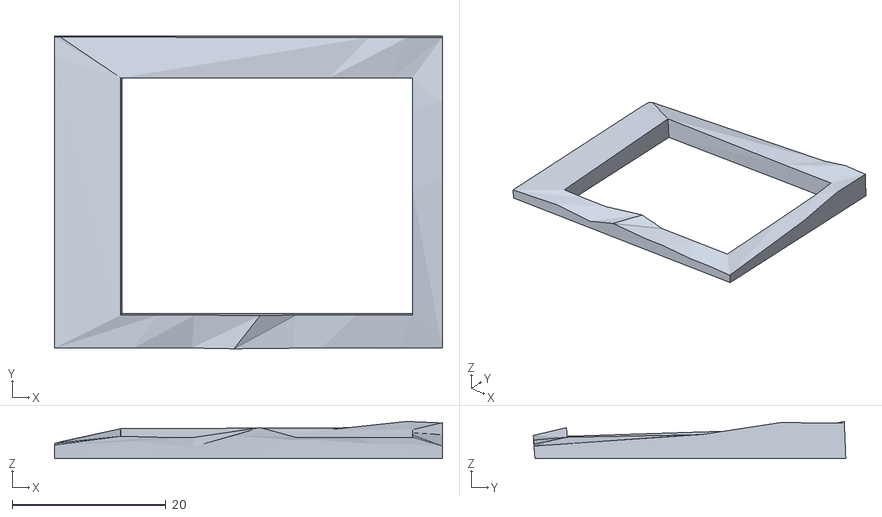
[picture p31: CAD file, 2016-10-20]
toolkit/tentacle-3d-model/export/parts/top_and_display_covers/g3_1_the_front_display_frame.stl
50.5 x 40.7 x 4.84

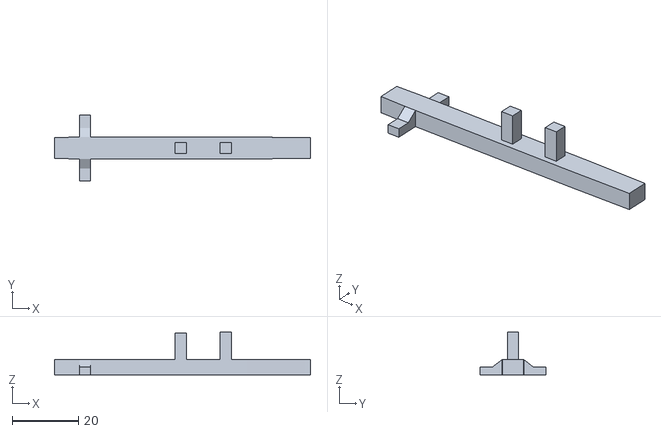
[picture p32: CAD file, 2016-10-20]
toolkit/tentacle-3d-model/export/parts/bottom_and_insides/g1_4_the_top_button_lever.stl
77.1 x 19.9 x 12.9

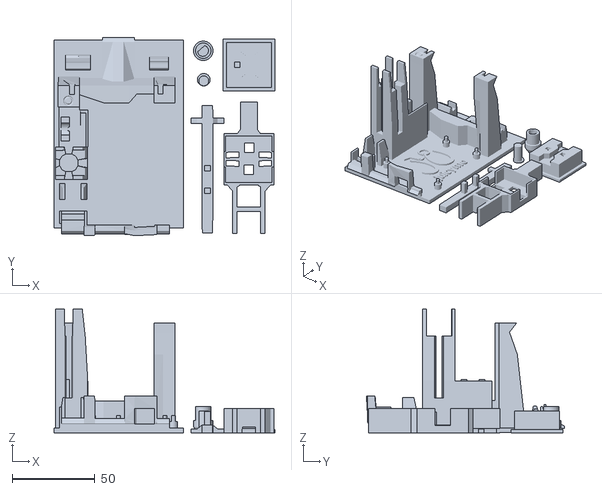
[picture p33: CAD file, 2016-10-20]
toolkit/tentacle-3d-model/export/ready-to-print/1_bottom_and_insides.stl
133.2 x 119.5 x 74.5

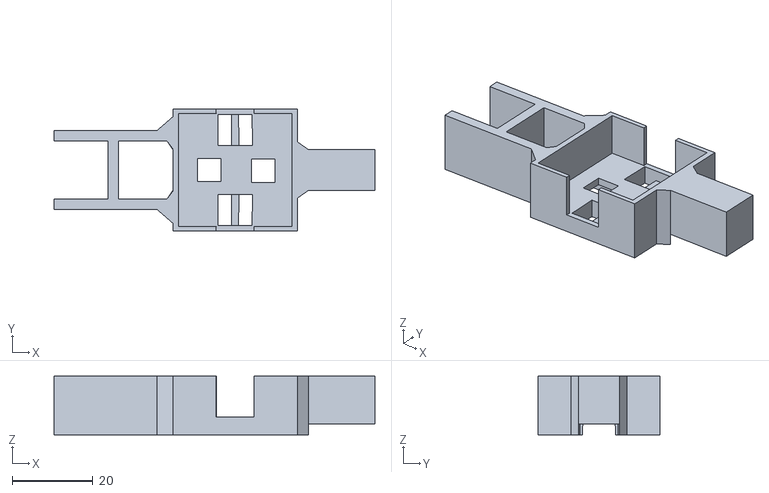
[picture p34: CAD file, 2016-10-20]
toolkit/tentacle-3d-model/export/parts/bottom_and_insides/g1_5_the_top_button_lodge.stl
79.3 x 30.2 x 14.5

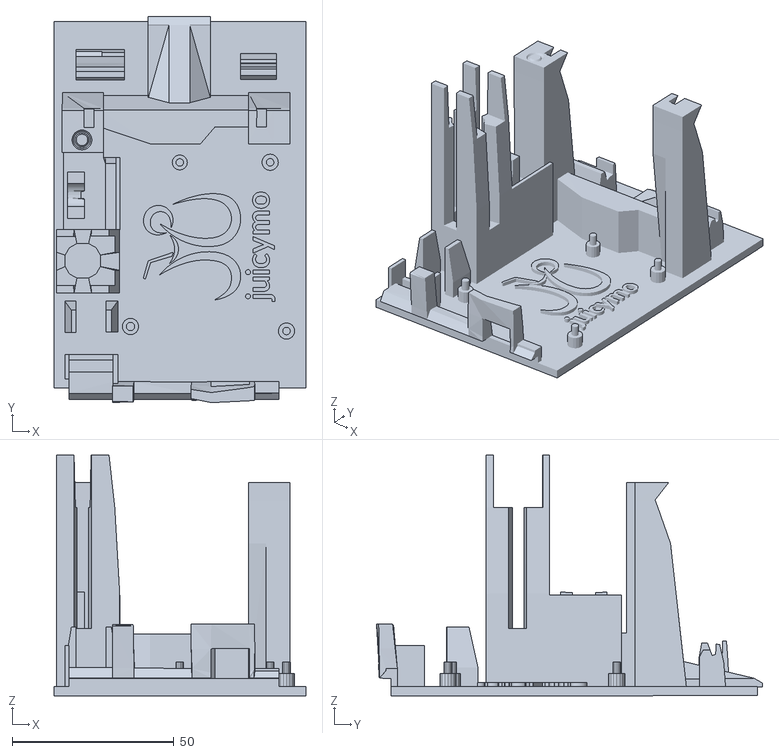
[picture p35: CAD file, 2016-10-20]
toolkit/tentacle-3d-model/export/parts/bottom_and_insides/g1_1_the_bottom_part.stl
78.0 x 119.5 x 74.5

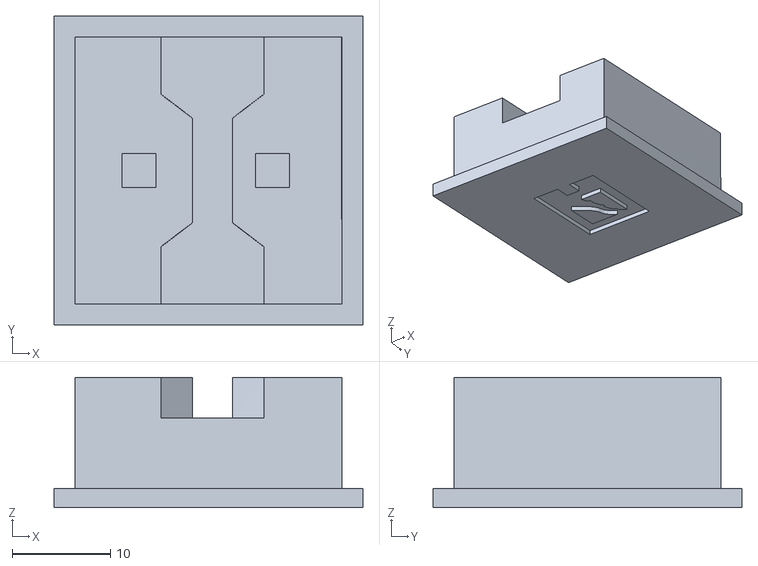
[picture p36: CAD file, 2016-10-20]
toolkit/tentacle-3d-model/export/parts/bottom_and_insides/g1_6_the_top_button.stl
31.4 x 31.4 x 13.2

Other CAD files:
toolkit/tentacle-3d-model/export/ready-to-print/2_walls.stl

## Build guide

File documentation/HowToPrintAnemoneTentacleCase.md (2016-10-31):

# How to 3D print Anemone Tentacle Mk1 Case

In this tutorial, we will guide you throught the 3D printing the *Anemone Tentacle case*.

> Anemone Tentacle case is in fact the very **first 3D printed Arduino YÚN case which is using the Arduino TFT Display** in the world! An it can be used even outside of the Anemone Platform. Feel free to use it even for your other projects ;).

- Anemone Tentacle Mk1 case can be downloaded from the [Thingiverse](http://www.thingiverse.com/thing:1815218) as well.

Anemone Tentacle case is shown on the following images.

#### Wired

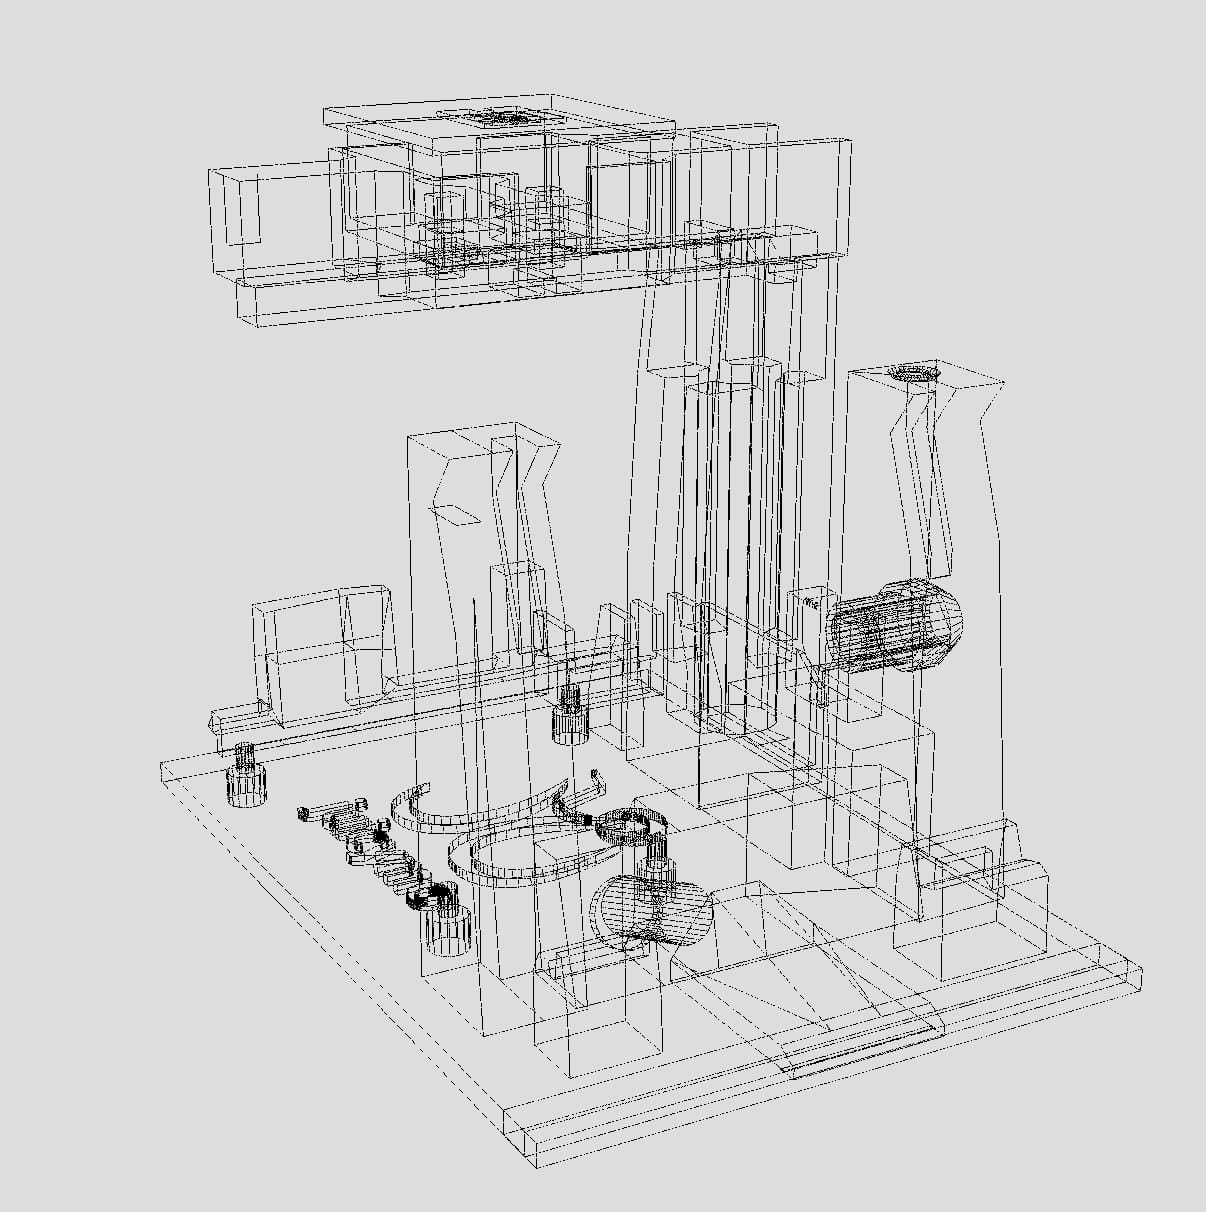
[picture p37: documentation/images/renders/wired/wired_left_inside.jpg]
Anemone Tentacle Wired 3D Model Left - Inside

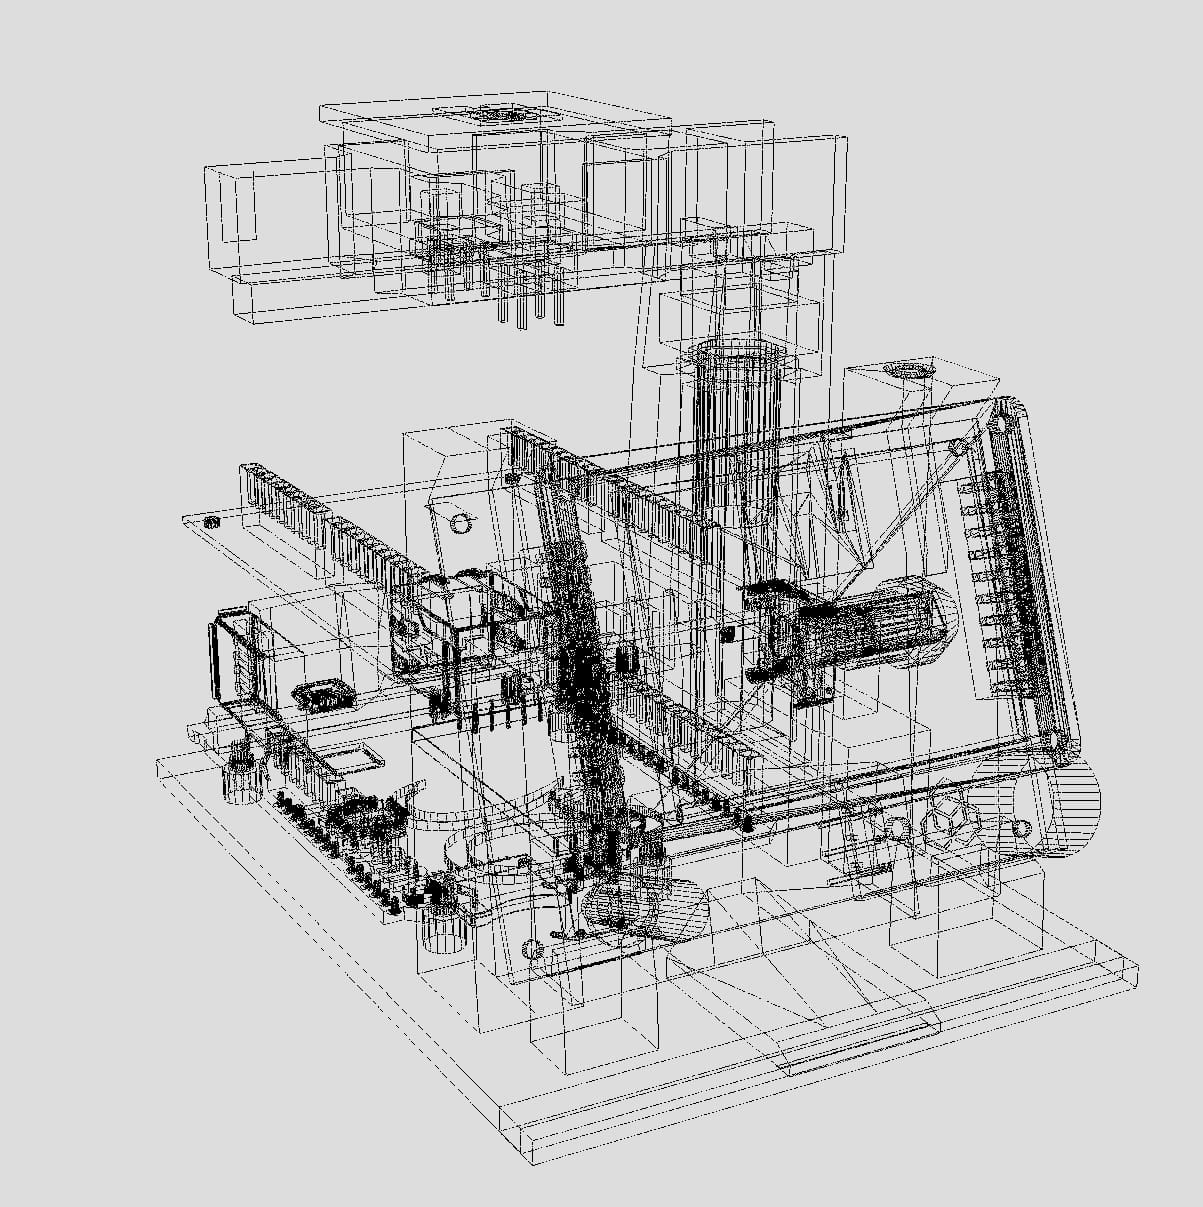
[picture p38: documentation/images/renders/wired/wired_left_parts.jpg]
Anemone Tentacle Wired 3D Model Left - Parts
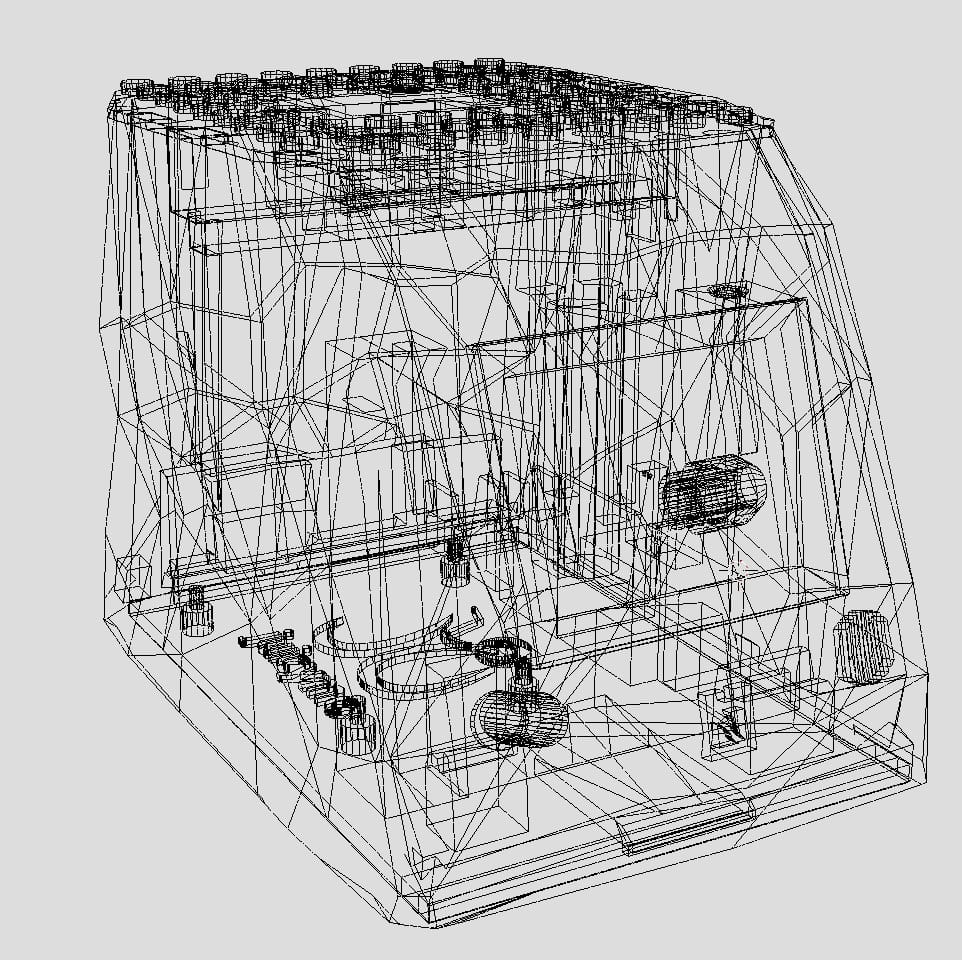
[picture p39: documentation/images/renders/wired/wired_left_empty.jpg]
Anemone Tentacle Wired 3D Model Left - Whole Case
  

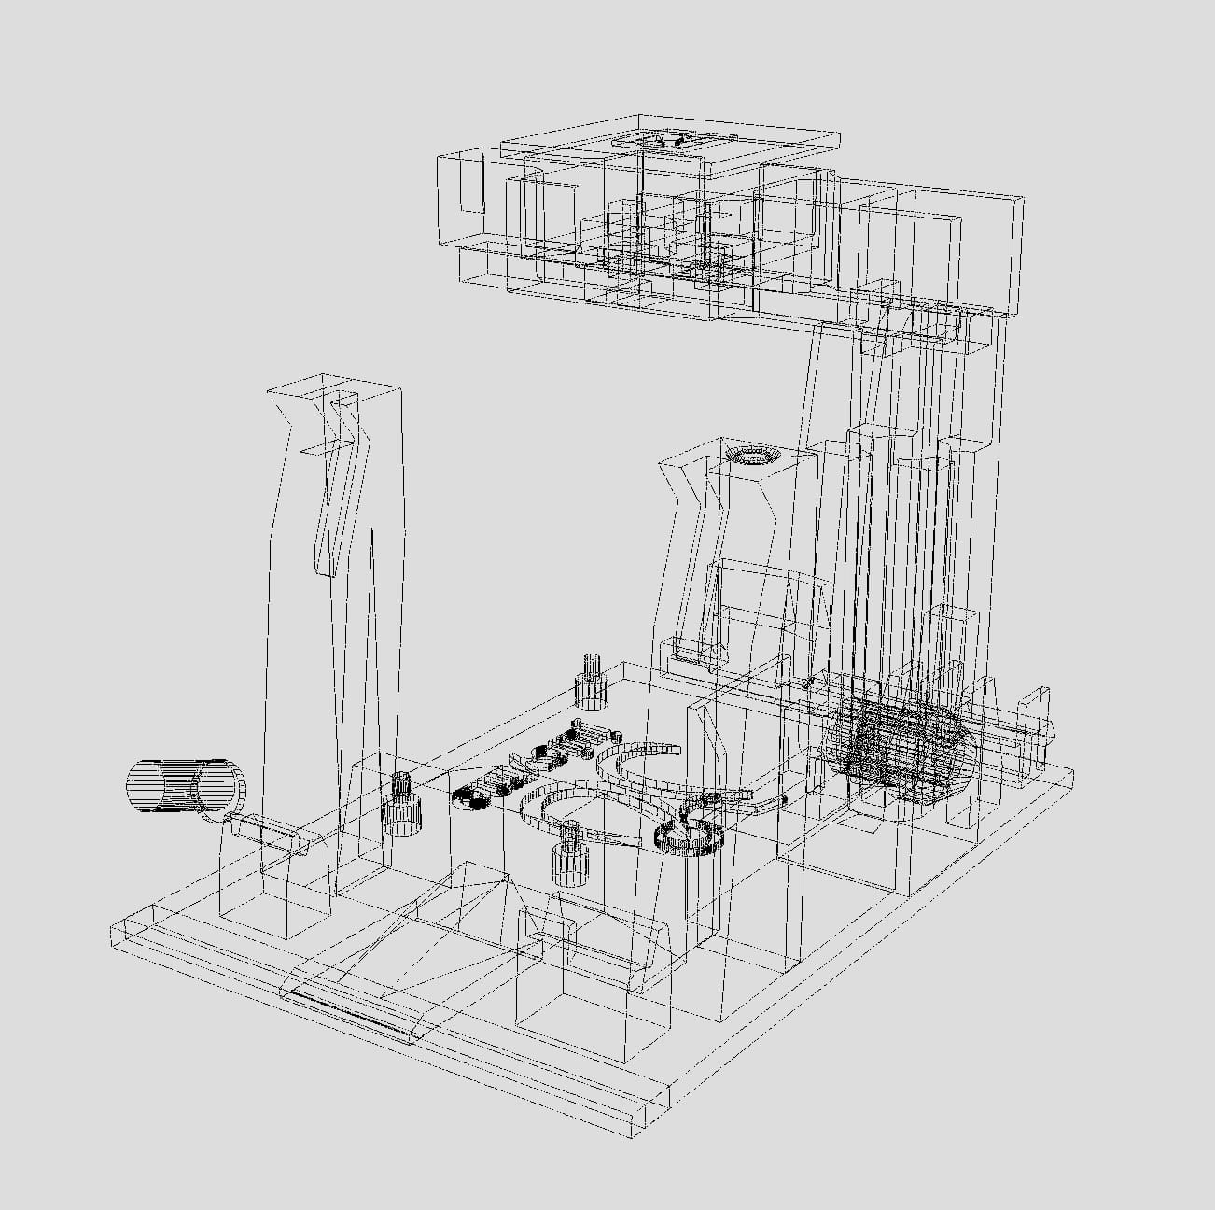
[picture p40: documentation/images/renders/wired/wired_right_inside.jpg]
Anemone Tentacle Wired 3D Model Right - Inside

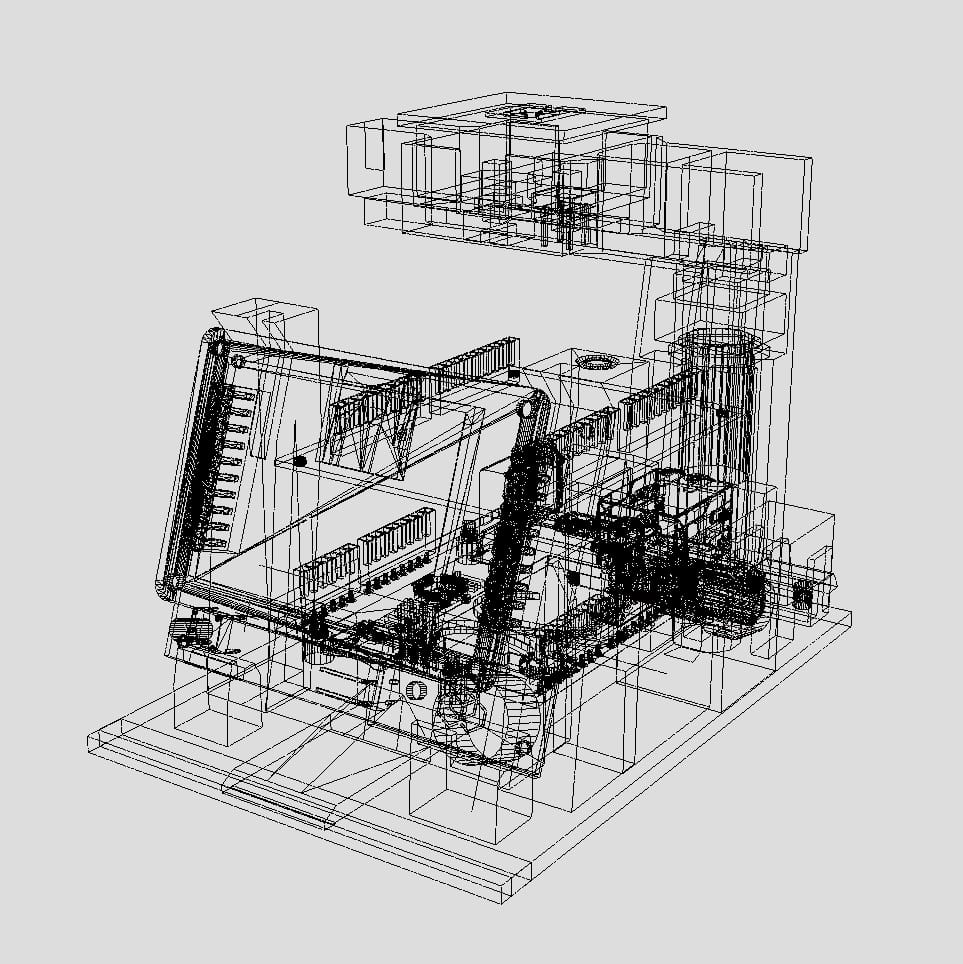
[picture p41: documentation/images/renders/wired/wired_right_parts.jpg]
Anemone Tentacle Wired 3D Model Right - Parts
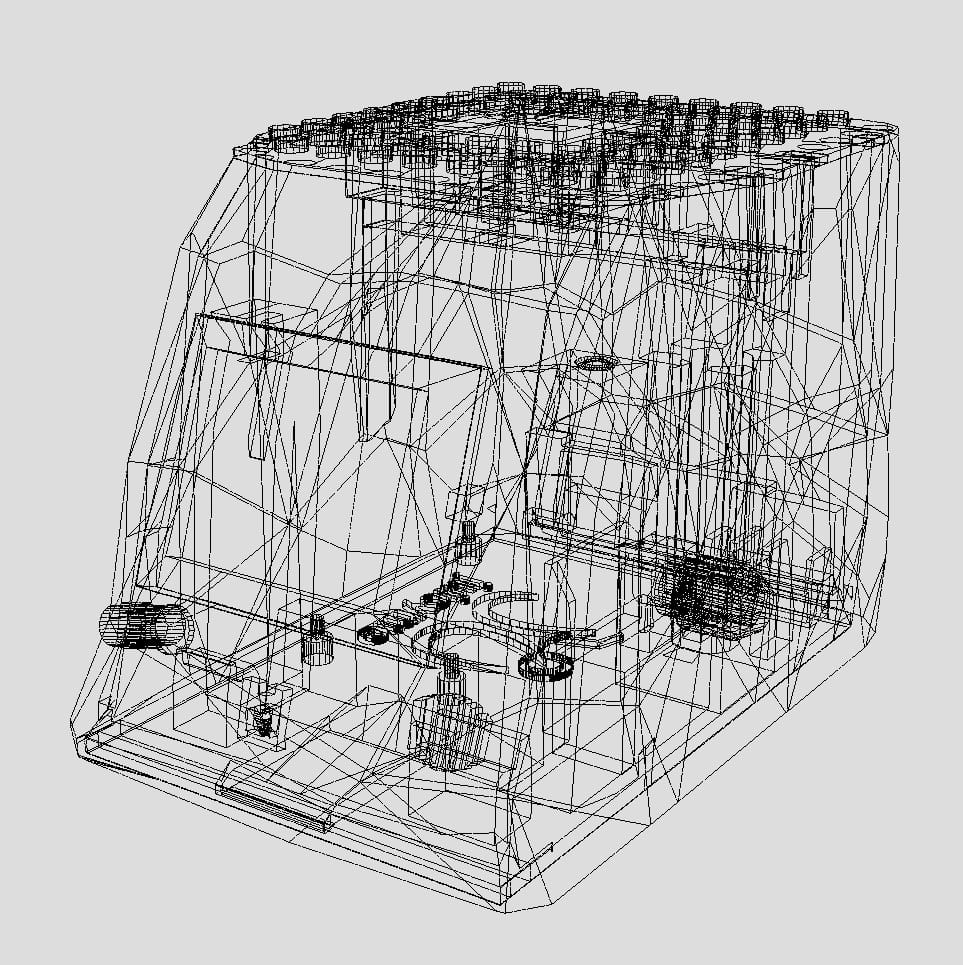
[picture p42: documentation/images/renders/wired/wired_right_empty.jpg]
Anemone Tentacle Wired 3D Model Right - Whole Case
  
 
#### Shaded

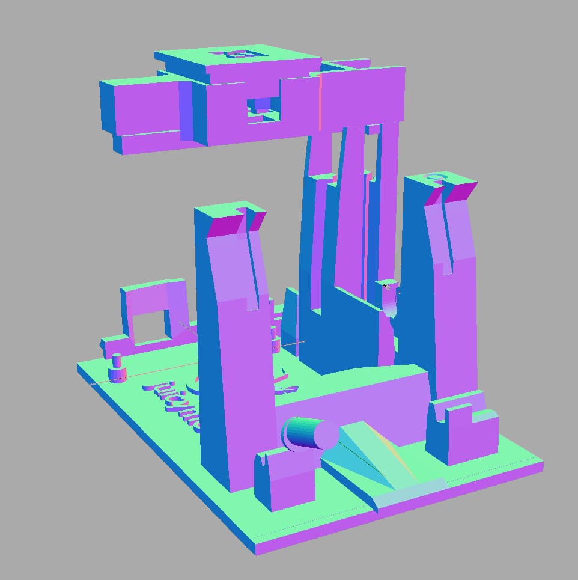
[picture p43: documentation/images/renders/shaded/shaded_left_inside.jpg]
Anemone Tentacle Shaded 3D Model Left - Inside
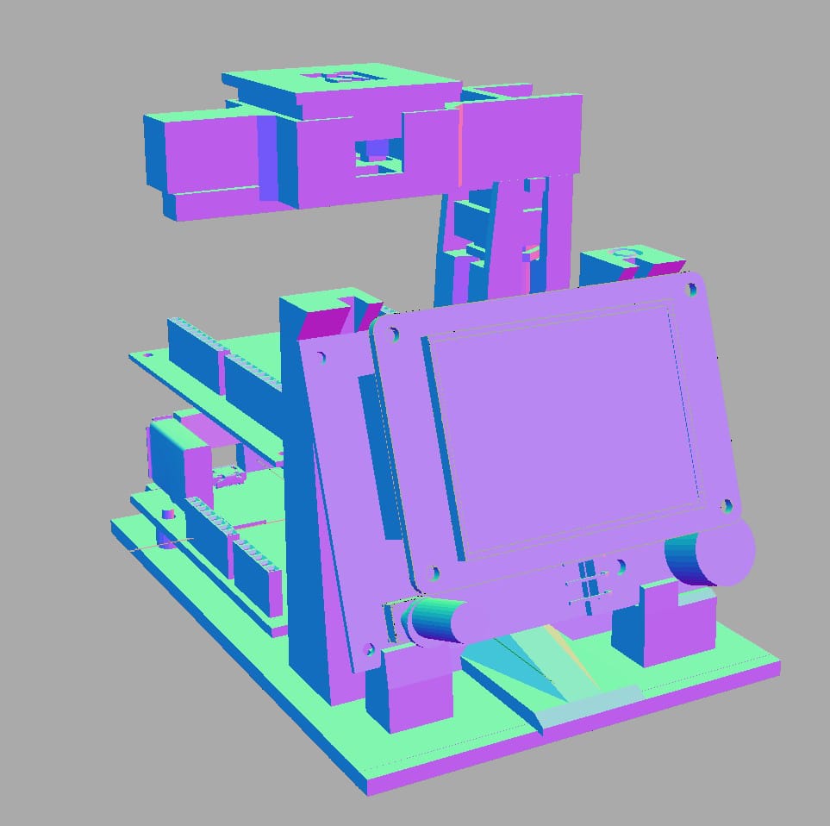
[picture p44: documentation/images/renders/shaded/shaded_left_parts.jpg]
Anemone Tentacle Shaded 3D Model Left - Parts
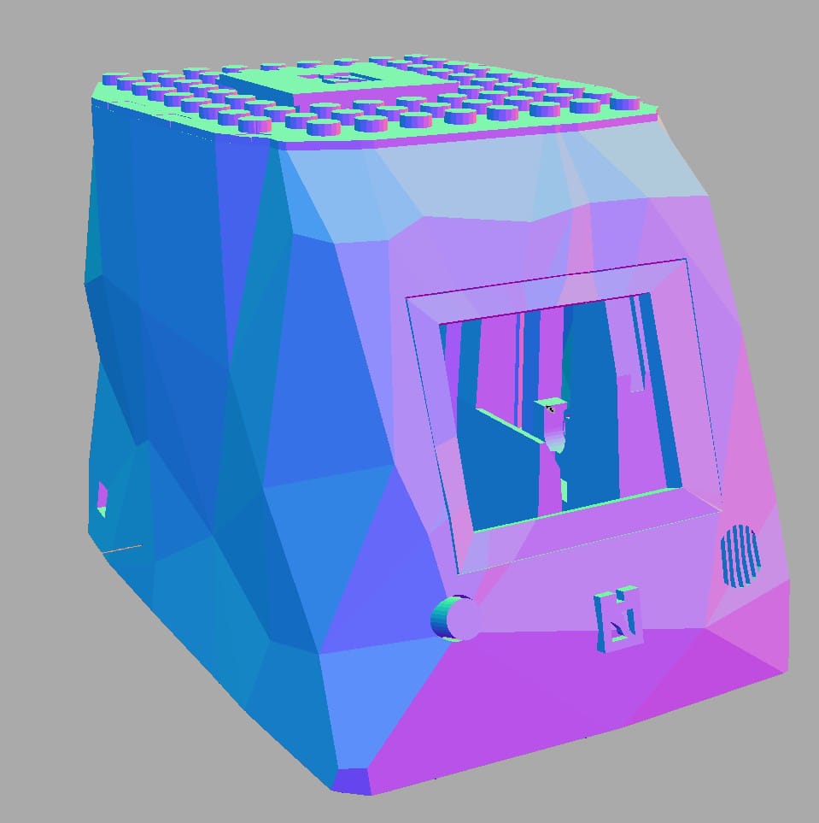
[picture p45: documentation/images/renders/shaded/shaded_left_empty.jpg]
Anemone Tentacle Shaded 3D Model Left - Whole Case
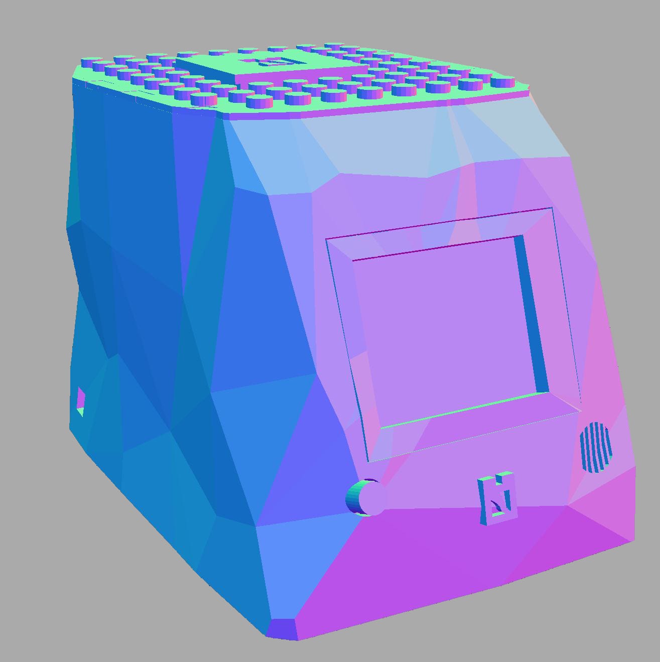
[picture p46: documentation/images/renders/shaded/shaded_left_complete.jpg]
Anemone Tentacle Shaded 3D Model Left - Complete
   

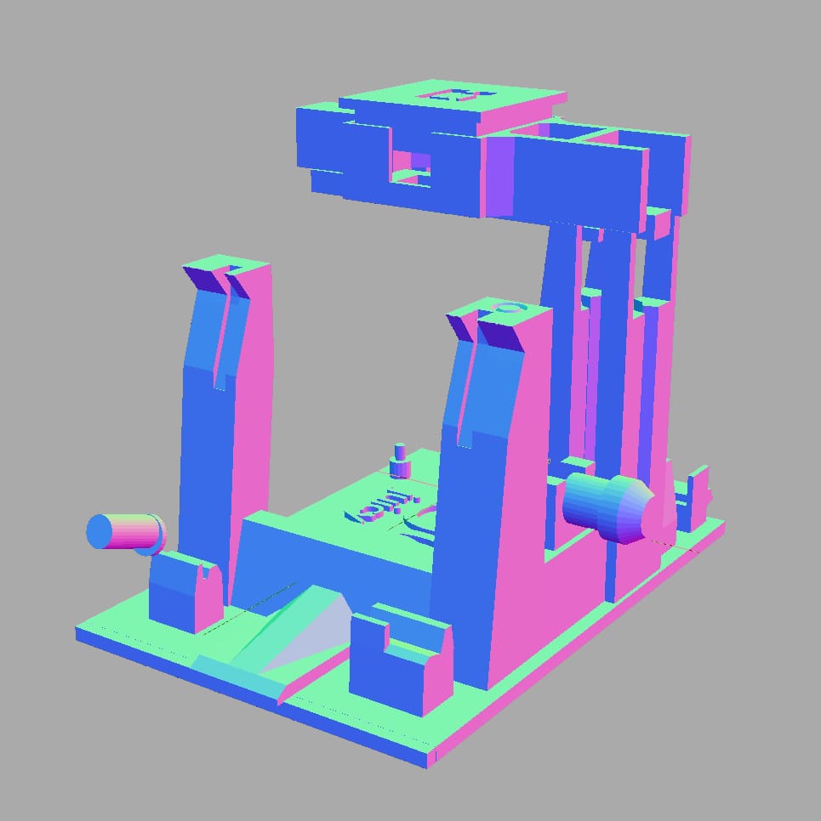
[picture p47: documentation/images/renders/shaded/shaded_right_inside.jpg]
Anemone Tentacle Shaded 3D Model Right - Inside
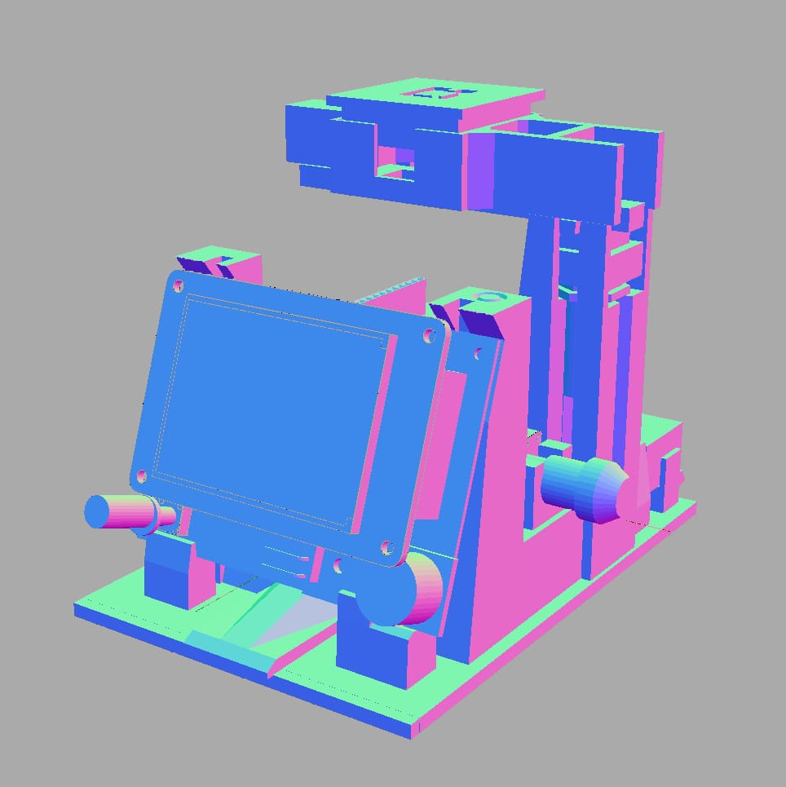
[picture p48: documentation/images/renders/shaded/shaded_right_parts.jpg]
Anemone Tentacle Shaded 3D Model Right - Parts
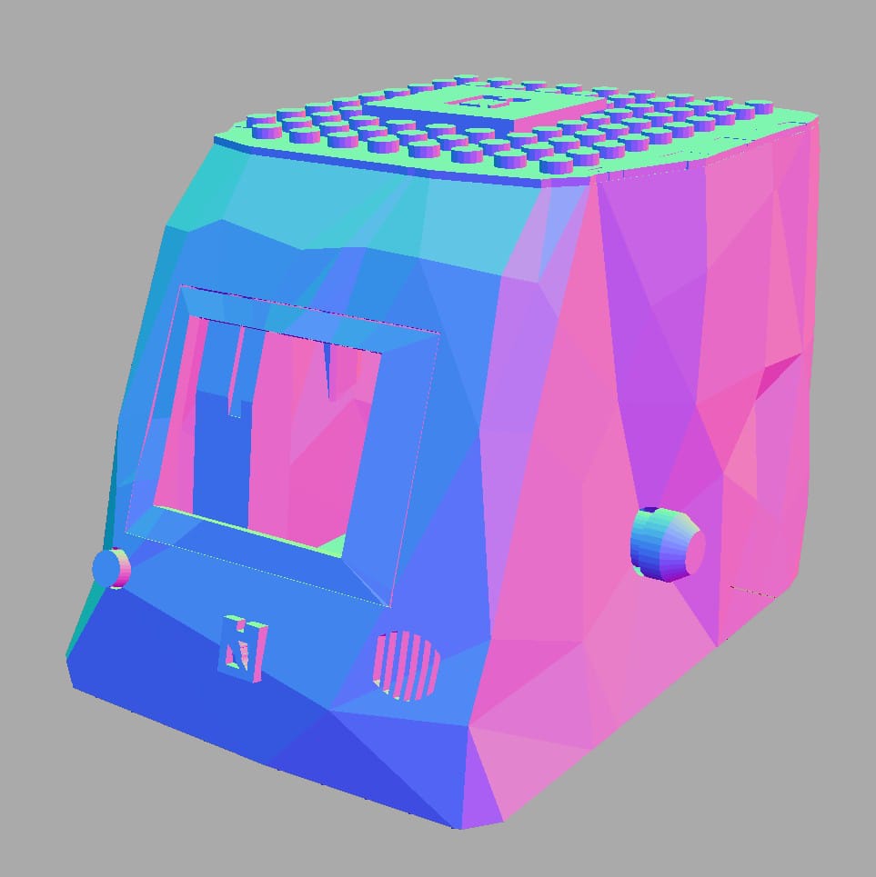
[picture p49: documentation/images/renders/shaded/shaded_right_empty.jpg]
Anemone Tentacle Shaded 3D Model Right - Whole Case
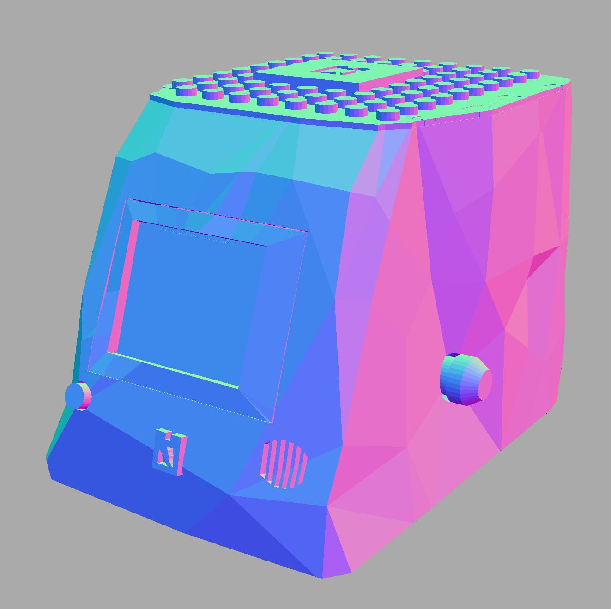
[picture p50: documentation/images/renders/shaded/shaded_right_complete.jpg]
Anemone Tentacle Shaded 3D Model Right - Complete
   

#### Rendered

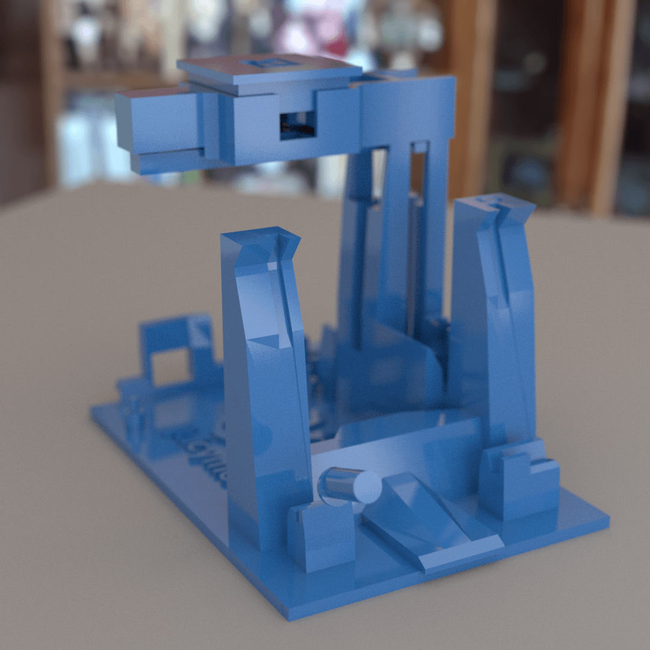
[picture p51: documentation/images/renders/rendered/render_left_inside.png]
Anemone Tentacle Rendered 3D Model Left - Inside
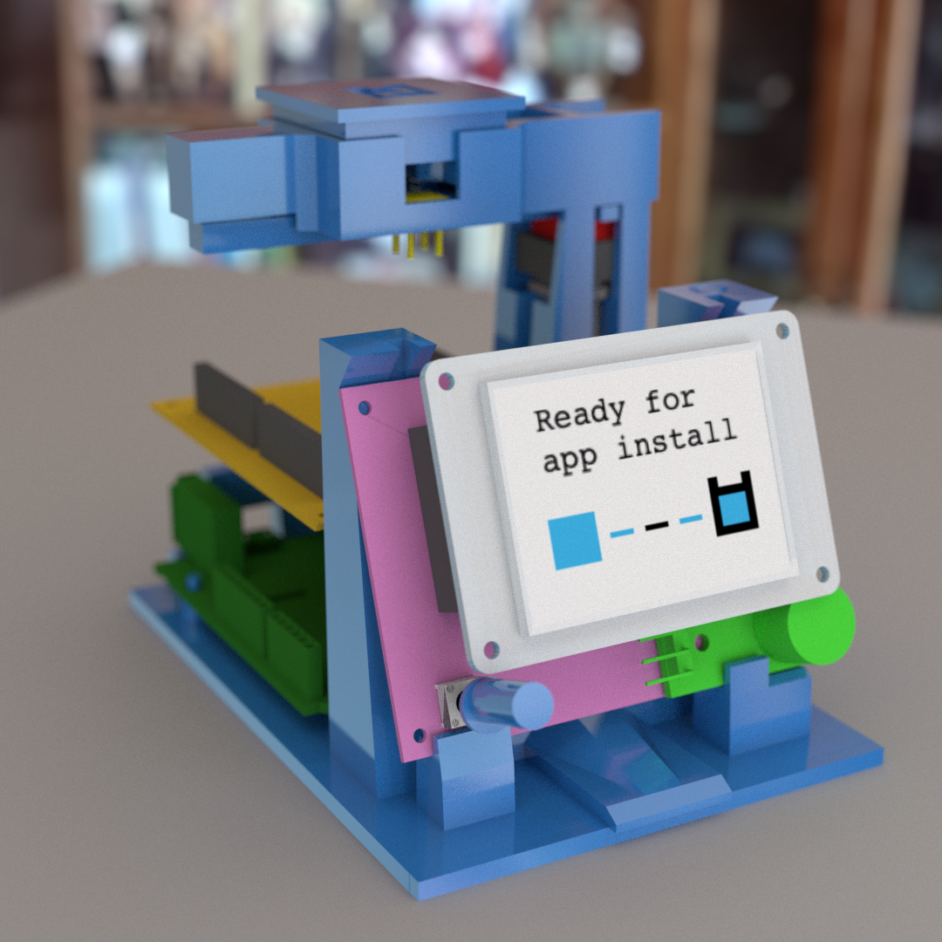
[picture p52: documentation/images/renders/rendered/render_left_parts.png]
Anemone Tentacle Rendered 3D Model Left - Parts
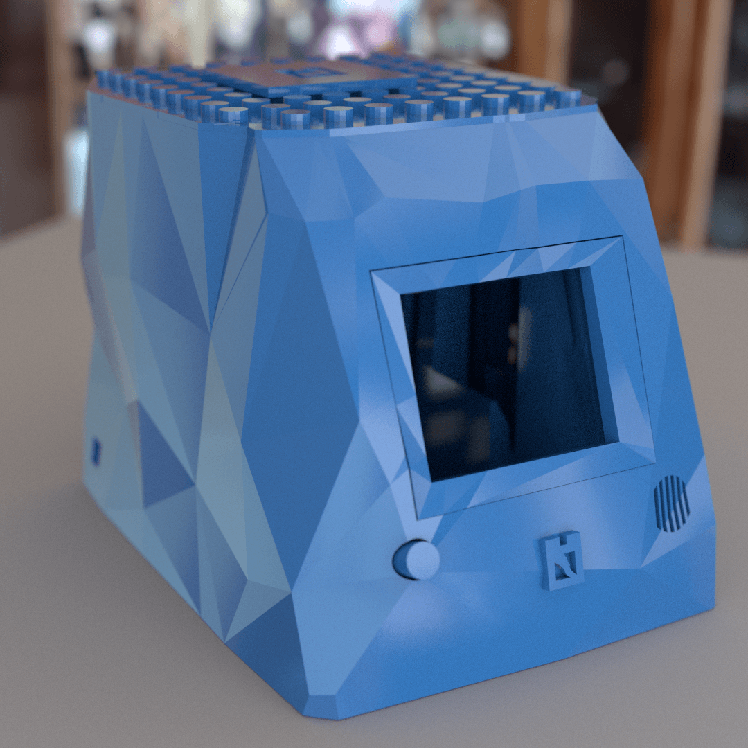
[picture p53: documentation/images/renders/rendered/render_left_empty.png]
Anemone Tentacle Rendered 3D Model Left - Whole Case
   Anemone Tentacle Rendered 3D Model Left - Complete

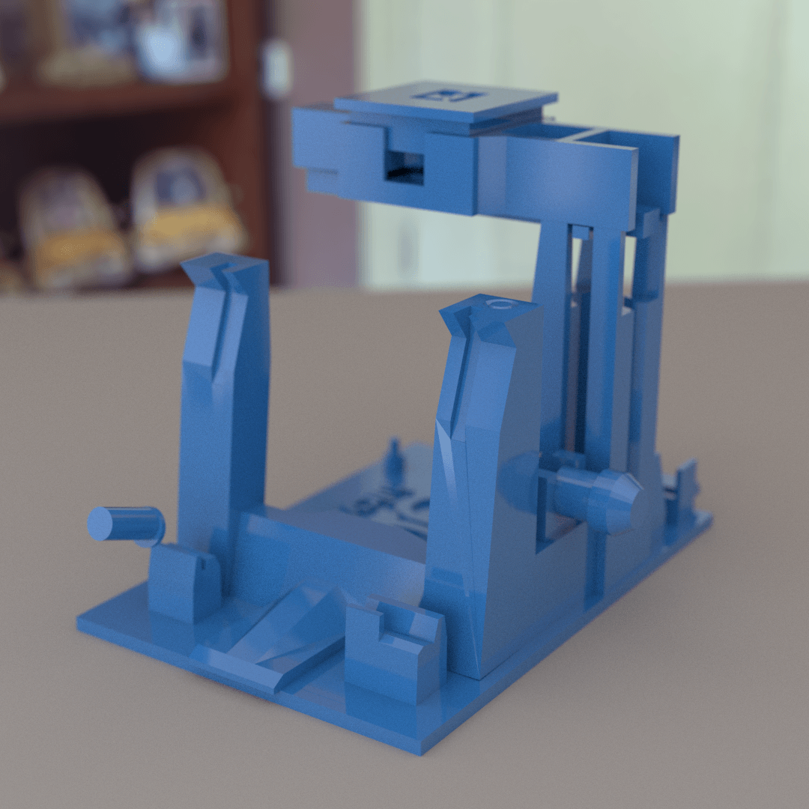
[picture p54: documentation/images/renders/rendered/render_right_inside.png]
Anemone Tentacle Rendered 3D Model Right - Inside
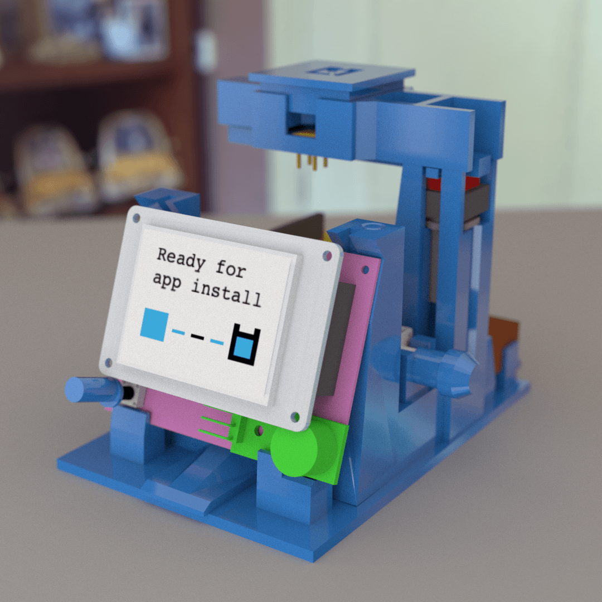
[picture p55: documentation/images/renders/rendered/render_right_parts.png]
Anemone Tentacle Rendered 3D Model Right - Parts
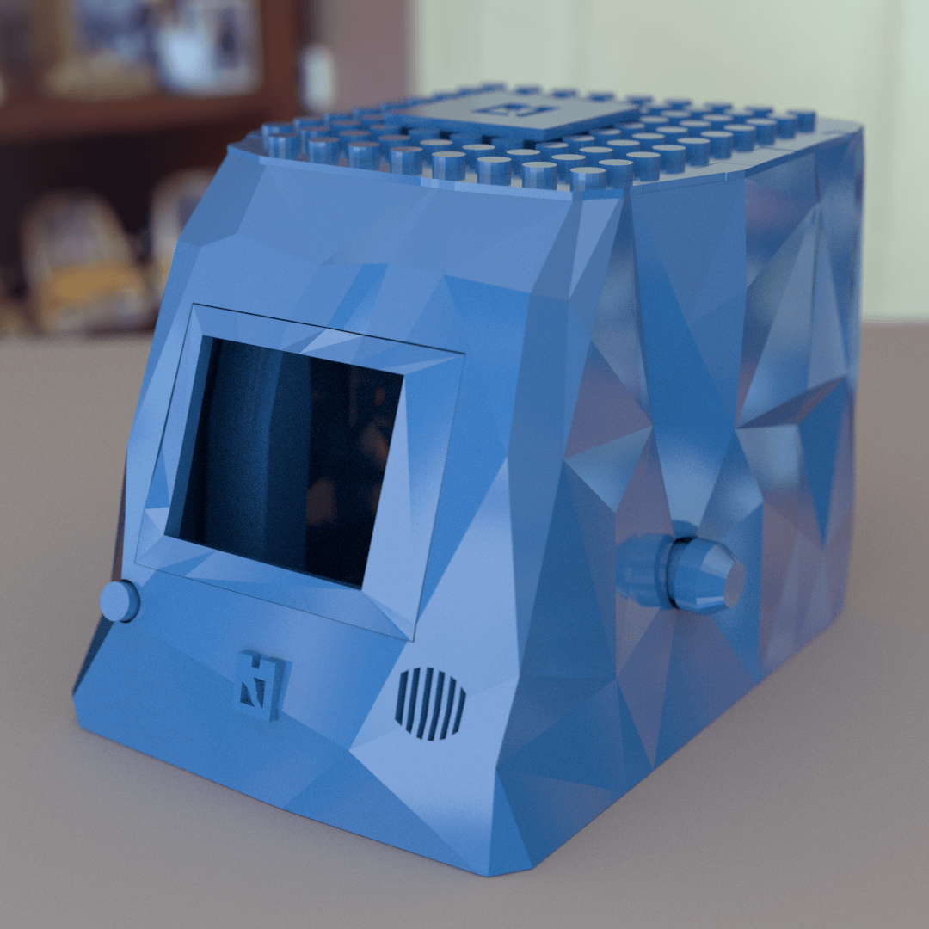
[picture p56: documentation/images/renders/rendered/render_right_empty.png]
Anemone Tentacle Rendered 3D Model Right - Whole Case
   Anemone Tentacle Rendered 3D Model Right - Complete

#### Video

Anemone Tentacle Mk1 3D Visualization

> Video in better quality can be seen at [youtube](https://youtu.be/J8Jwhn_DrBI).

#### Printed

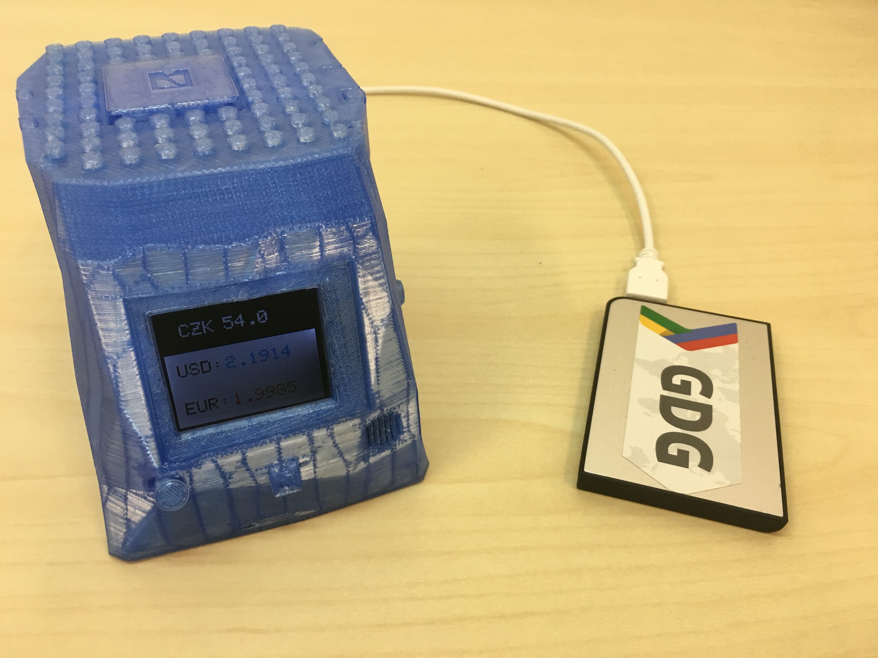
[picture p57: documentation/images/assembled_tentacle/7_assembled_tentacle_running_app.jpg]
Anemone Tentacle Printed and Running


> For the *How to build* Anemone Tentacle refer to a separate page of our tutorial, see [How to build Anemone Tentacle](https://github.com/ceskasporitelna/anemone/blob/master/documentation/HowToBuildAnemoneTentacle.md).

### 3D model 

The Anemone Tentacle 3D model has been created in [Blender](https://www.blender.org/) and if you like you can download the original [.blend file](TODO).

But we have provided [.stl exports](TODO) for you as well.

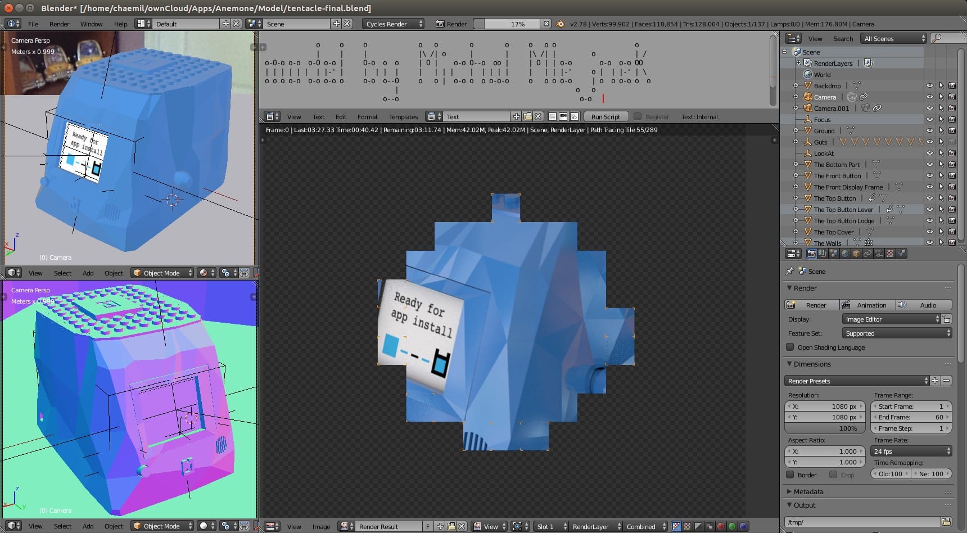
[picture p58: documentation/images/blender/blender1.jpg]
Anemone Tentacle 3D Model in Blender A
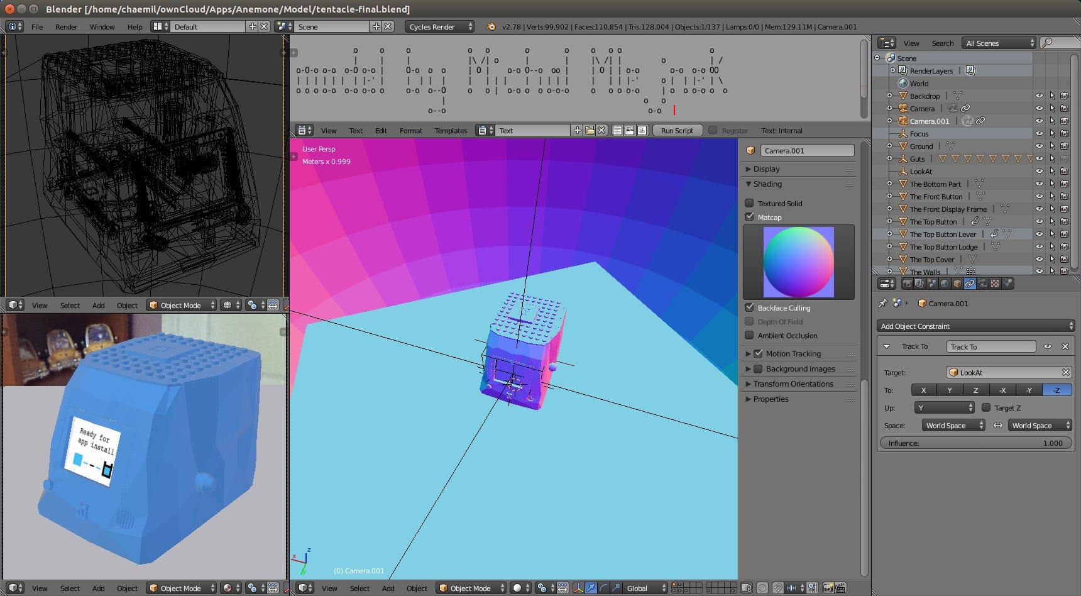
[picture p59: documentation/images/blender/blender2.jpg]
Anemone Tentacle 3D Model in Blender B
 

### Tentacle Components

Anemone Tentacle consists of the following components:

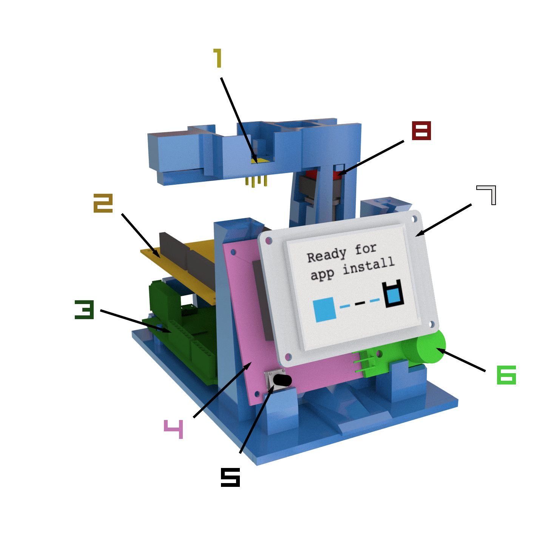
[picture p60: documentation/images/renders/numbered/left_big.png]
Anemone Tentacle Parts Description Left
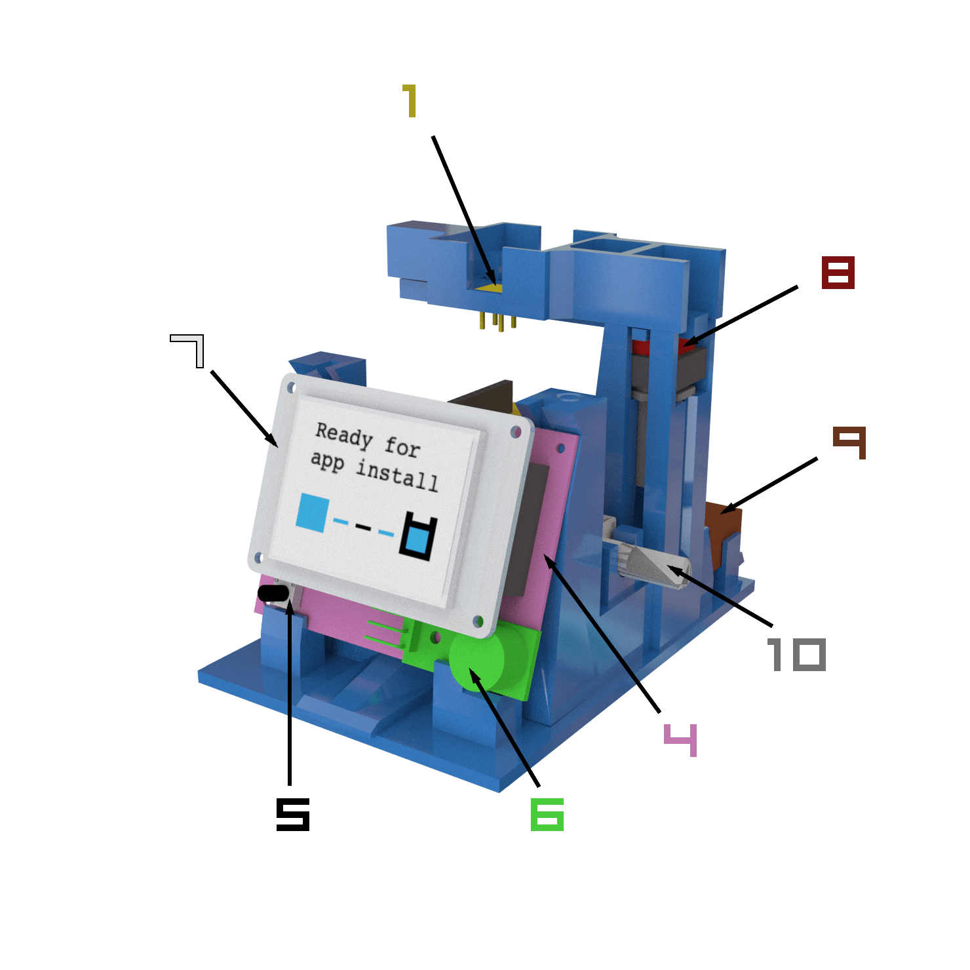
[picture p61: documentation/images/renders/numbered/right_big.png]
Anemone Tentacle Parts Description Right
 

1. Top LEDs
2. Tentacle Shield
3. Arduino YÚN
4. Display Board
5. Cloud Button
6. Buzzer YL-44
7. Arduino TFT Display
8. Top Button
9. RJ-11 I2C Socket
10. Rotary Encoder KY-040

### Slicing

Anemone Tentacle case consists of the following components:

* The Bottom Part
* The Walls
* The Top Button
* The Top Button Lodge
* The Top Button Lever
* The Menu Knob Cover
* The Front Button
* The Top *(LEGO® compatible)* Cover
* The Front Display Frame

The components are available either as [9 .stl files of individual components](TODO).

Or as three [*ready-to-print* .stl files](TODO) with all components assigned into three groups *(with slightly different print settings)* :

1. Bottom and Insides
2. Walls
3. Top and Display Covers

> In addition to the [.stl *ready-to-print* file for every print group](TODO) you can download a exported [gcode files for the *Prusa i3 MK2 3D Printer* with ABS filament setting](TODO). We have use these gcode files to print our version of Anemone Tentacle on *Kanárek*. 

#### Bottom and Insides

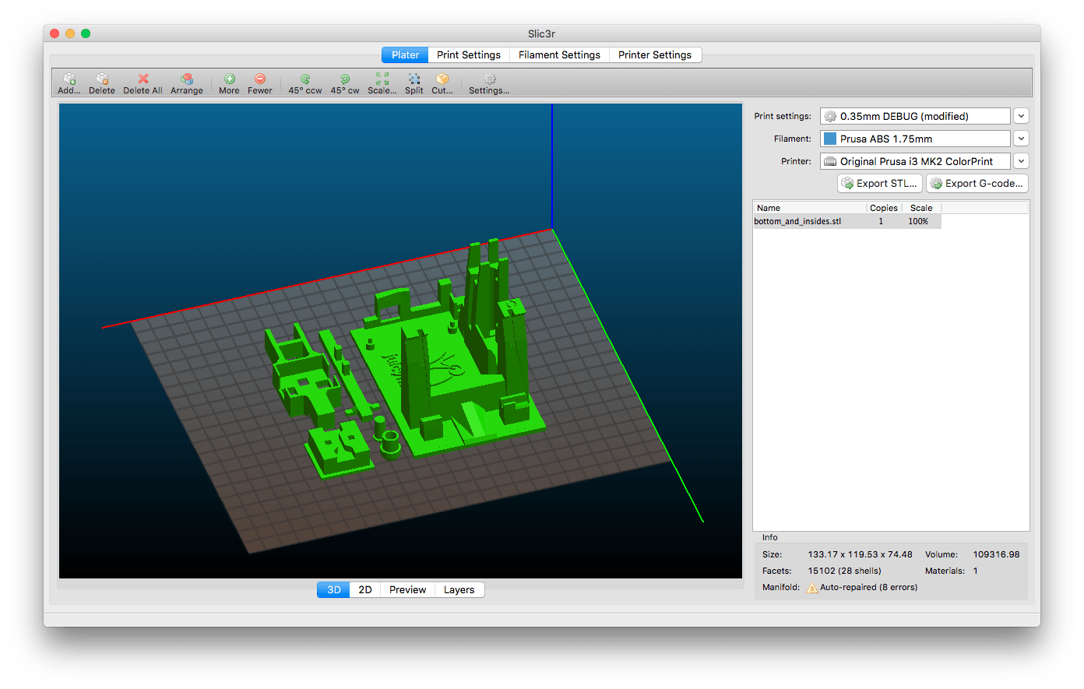
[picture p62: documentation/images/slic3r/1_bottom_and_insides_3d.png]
Anemone Tentacle in Slic3er - Bottom and Insides - 3D Model
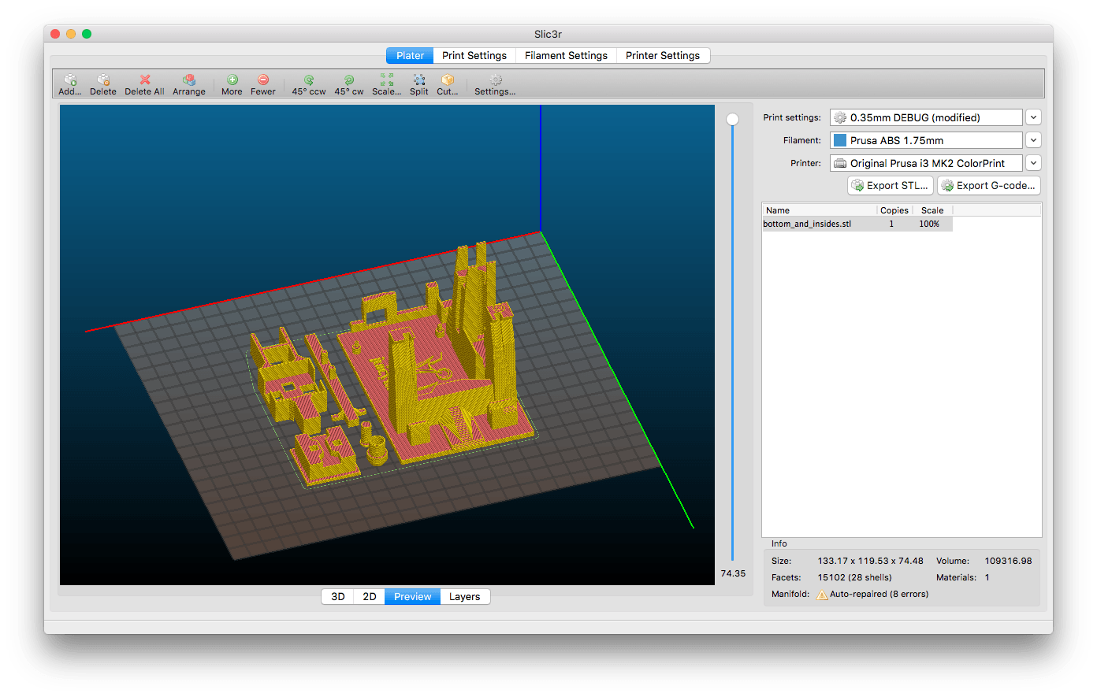
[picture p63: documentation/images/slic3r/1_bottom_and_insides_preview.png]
Anemone Tentacle in Slic3er - Bottom and Insides - Layers Preview
 

The first print group consists of case bottom part, internal components and all knobs and buttons.

##### How it looks 3D printed

> The print time for the first print group *Bottom and Insides* is `3 hours 30 minutes` with the recommended print settings.

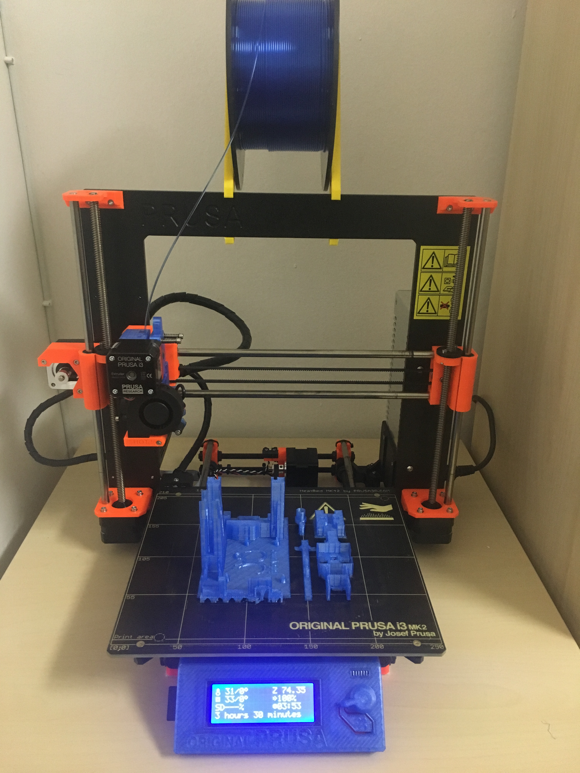
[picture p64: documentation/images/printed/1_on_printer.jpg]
Anemone Tentacle 3D Print Group 1 - On Printer
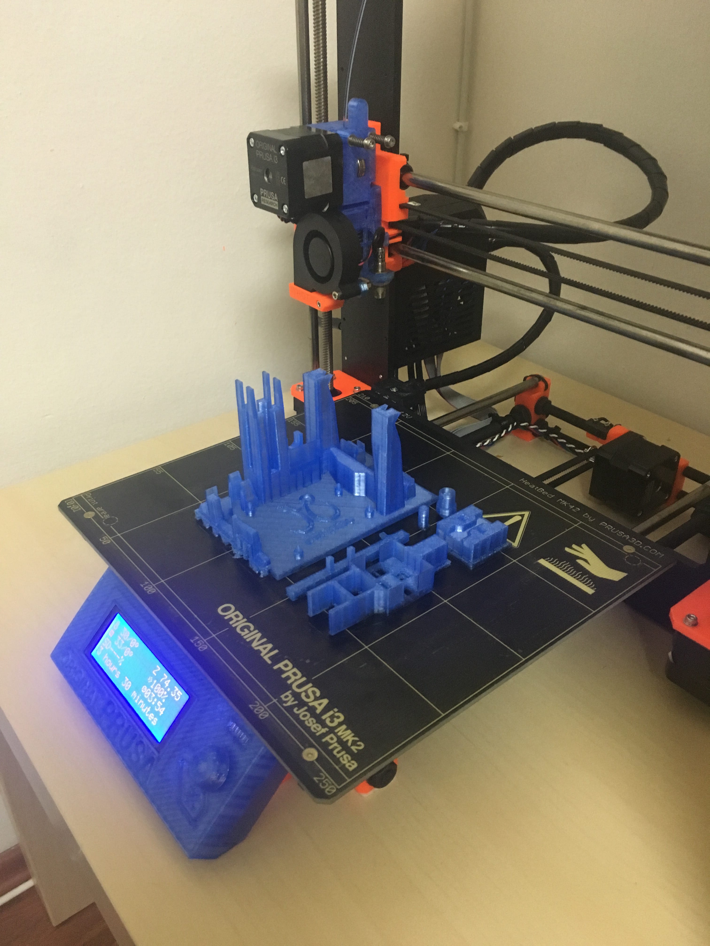
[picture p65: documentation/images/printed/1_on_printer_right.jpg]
Anemone Tentacle 3D Print Group 1 - On Printer Right
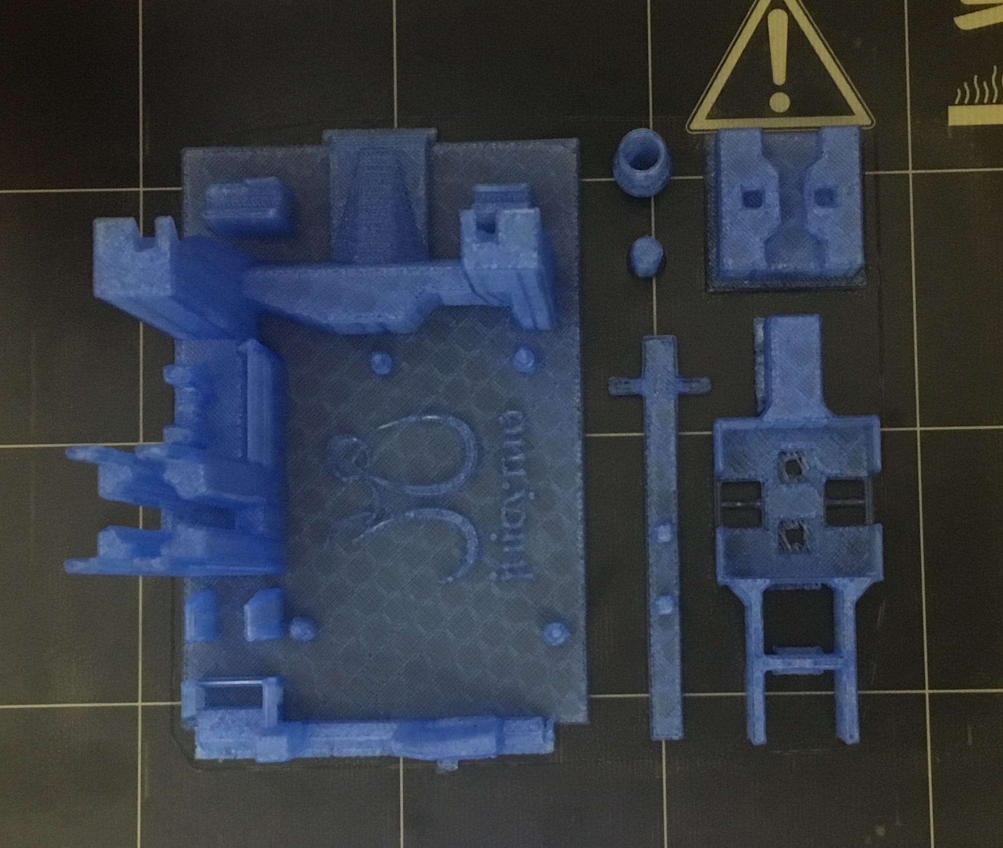
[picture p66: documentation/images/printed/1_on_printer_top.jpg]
Anemone Tentacle 3D Print Group 1 - On Printer Top
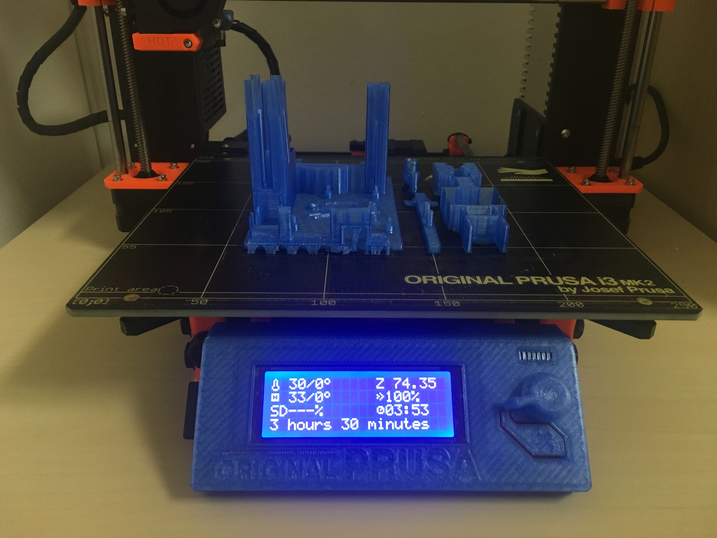
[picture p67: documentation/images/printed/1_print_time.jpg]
Anemone Tentacle 3D Print Group 1 - Print Time
   

After removing from the print bed your print should look similar to this:

> Only the *The Top Button Lodge* and *The Bottom Part* pieces do have few supports.

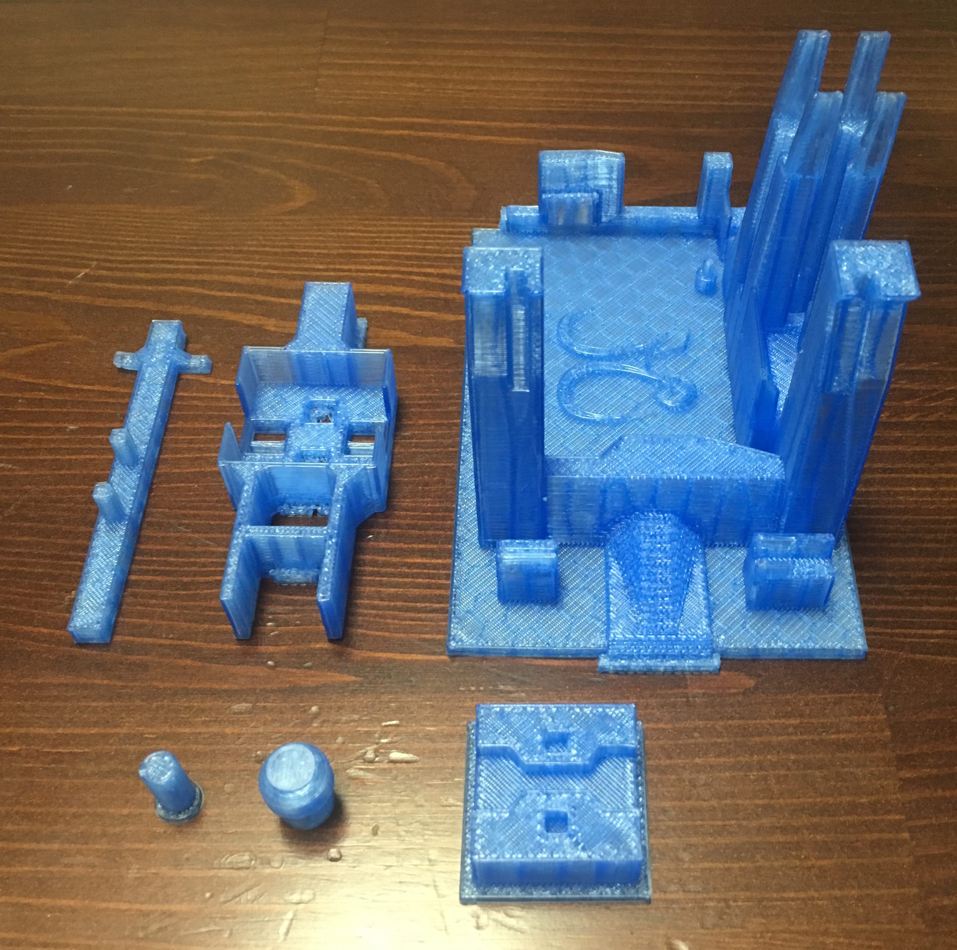
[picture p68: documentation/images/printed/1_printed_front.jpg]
Anemone Tentacle 3D Print Group 1 - Printed Front
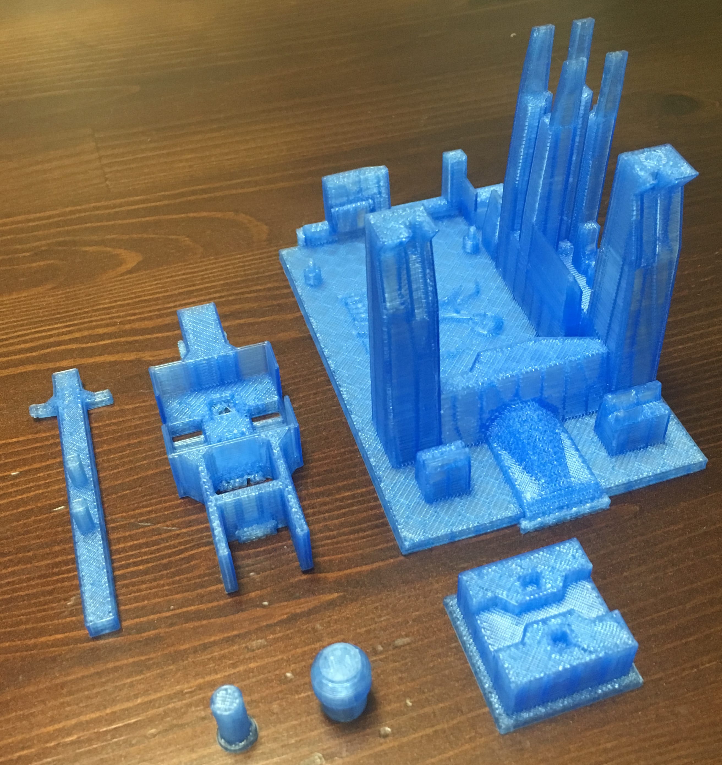
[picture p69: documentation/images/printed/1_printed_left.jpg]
Anemone Tentacle 3D Print Group 1 - Printed Left
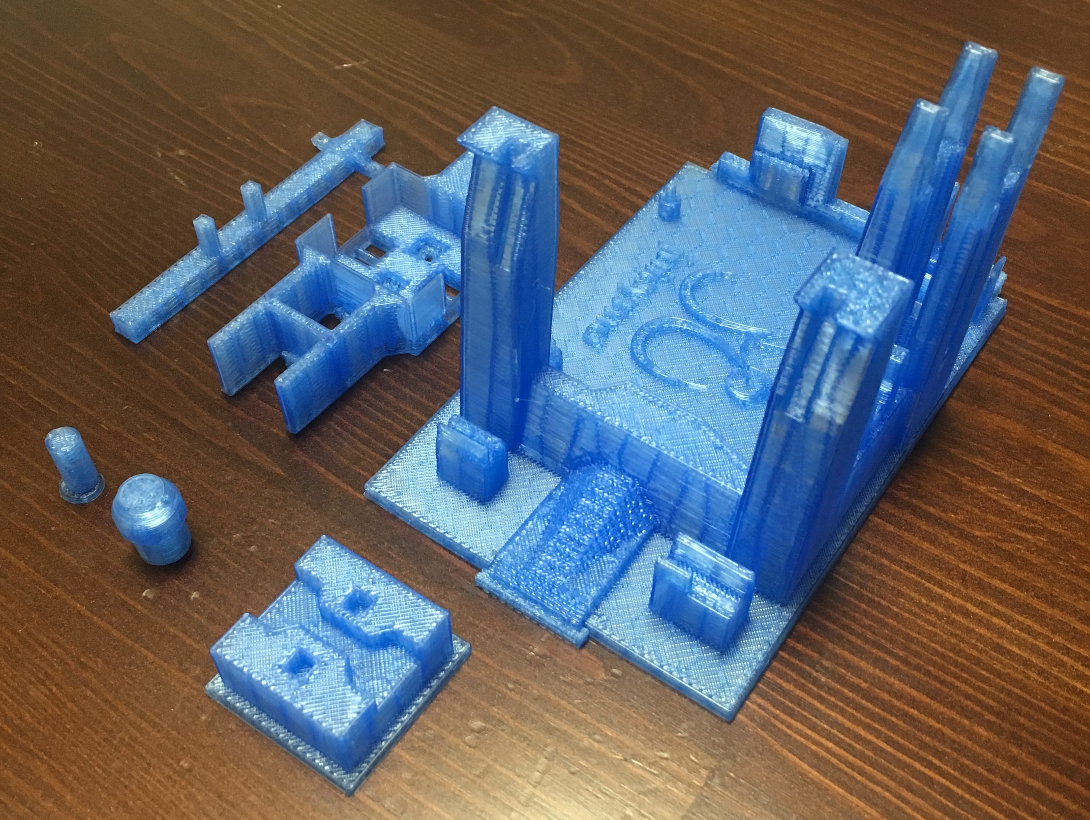
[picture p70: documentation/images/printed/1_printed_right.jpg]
Anemone Tentacle 3D Print Group 1 - Printed Right
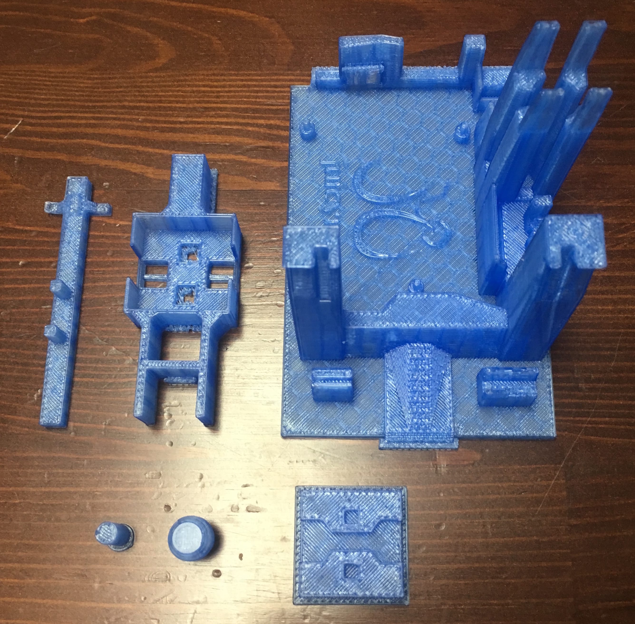
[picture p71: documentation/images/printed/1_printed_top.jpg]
Anemone Tentacle 3D Print Group 1 - Printed Top
   

#### Walls

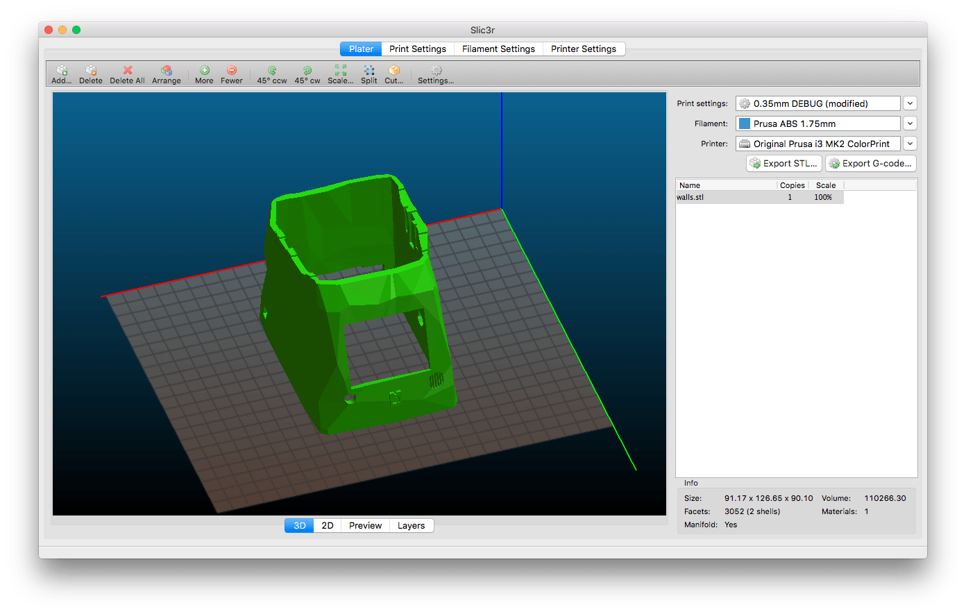
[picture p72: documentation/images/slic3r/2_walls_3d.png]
Anemone Tentacle in Slic3er - Walls - 3D Model
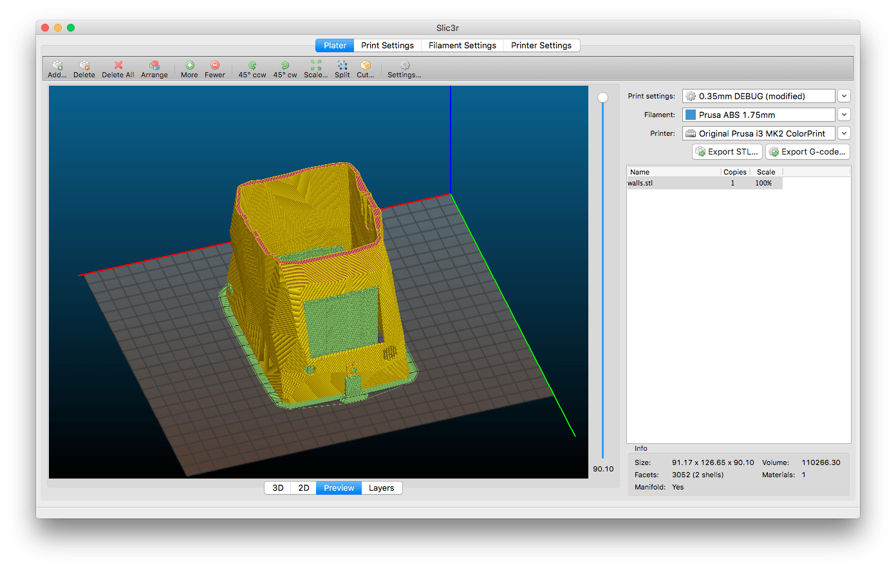
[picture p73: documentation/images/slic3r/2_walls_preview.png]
Anemone Tentacle in Slic3er - Walls - Layers Preview
 

The second print group is the case walls.

##### How it looks 3D printed

> The print time for the second print group *Walls* is `4 hours 54 minutes` with the recommended print settings.

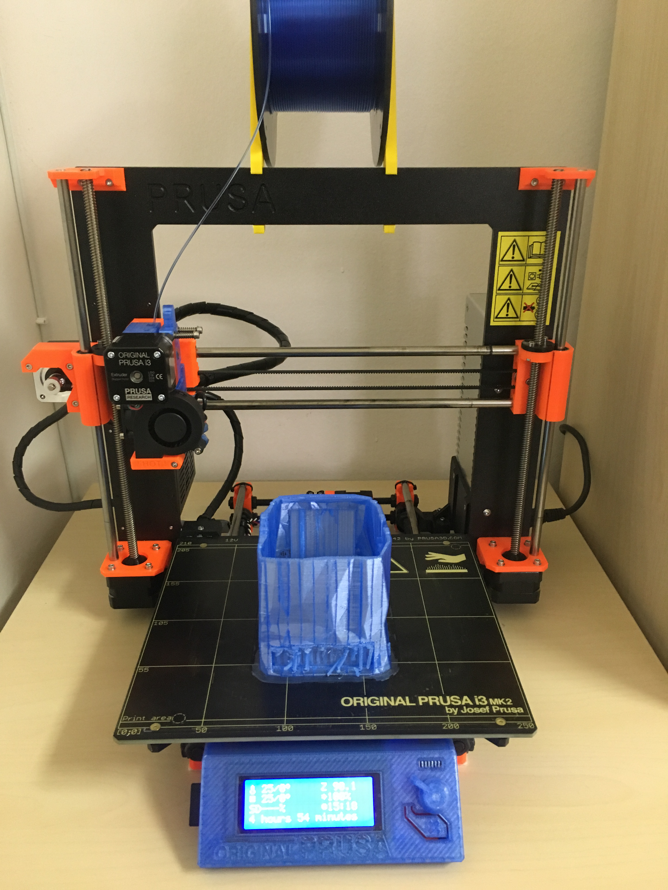
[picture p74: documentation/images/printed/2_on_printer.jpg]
Anemone Tentacle 3D Print Group 2 - On Printer
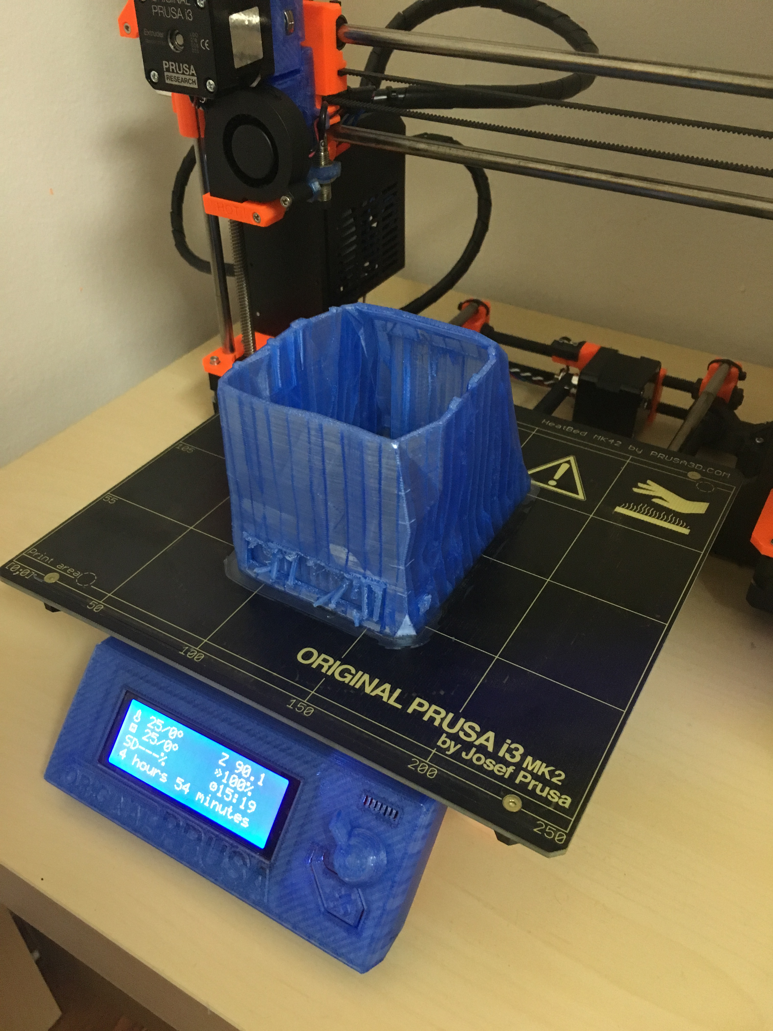
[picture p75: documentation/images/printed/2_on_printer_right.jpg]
Anemone Tentacle 3D Print Group 2 - On Printer Right
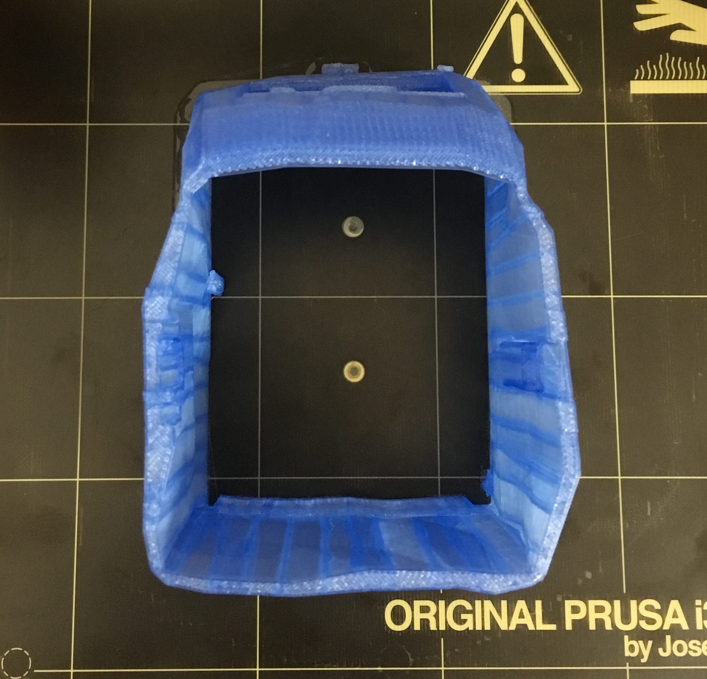
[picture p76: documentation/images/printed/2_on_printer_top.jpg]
Anemone Tentacle 3D Print Group 2 - On Printer Top
   Anemone Tentacle 3D Print Group 2 - Print Time

After removing from the print bed your print should look similar to this:

Anemone Tentacle 3D Print Group 2 - Printed Front Anemone Tentacle 3D Print Group 2 - Printed Left Anemone Tentacle 3D Print Group 2 - Printed Right Anemone Tentacle 3D Print Group 2 - Printed Top

After removing supports your print should look similar to this:

Anemone Tentacle 3D Print Group 2 - Printed Front Anemone Tentacle 3D Print Group 2 - Printed Left Anemone Tentacle 3D Print Group 2 - Printed Right Anemone Tentacle 3D Print Group 2 - Printed Top

#### Top and Display Covers

Anemone Tentacle in Slic3er - Top and Display covers - 3D Model Anemone Tentacle in Slic3er - Top and Display Covers - Layers Preview

The last print group contains the top *LEGO® compatible* cover piece and display frame cover.

##### How it looks 3D printed

> The print time for the third print group *Top and Display Covers* is `41 minutes` with the recommended print settings.

Anemone Tentacle 3D Print Group 3 - On Printer Anemone Tentacle 3D Print Group 3 - On Printer Right Anemone Tentacle 3D Print Group 3 - On Printer Top Anemone Tentacle 3D Print Group 3 - Print Time

After removing from the print bed your print should look similar to this:

Anemone Tentacle 3D Print Group 3 - Printed Front Anemone Tentacle 3D Print Group 3 - Printed Left Anemone Tentacle 3D Print Group 3 - Printed Right

> The *The Top Cover* piece may require some cleanup before it will fit *The Walls* piece. You may want to print this group with **just 2 perimeters instead of 5** if you are not able to fit it even after cleanup. Depending on your 3D printer and filament. We have intentionally designed this piece to have a good and strong grip with the *The Walls* piece.

This print group does not require any supports.

### Recommended print settings

The Anemone Tentacle case is optimized **to be printed in ABS** *(but theoretically should print well with PLA too)*.

We have used the [Slic3r](http://slic3r.org/) for slicing the `.stl` files into `.gcode`.

> Anemone Tentacle case looks awesome even on low print settings - which looks nice with a semi-transparent filament.

TODO assembled empty case photo

#### Global settings

* Filament: **ABS 1.75mm**
* Extruder Temperature: **255°C**
* Heatbed Temperature: **100°C**
* Layer height: **0.35mm**
* First layer height: **0.15mm**
* Perimeters: **1**
* Top Solid Layers: **2**
* Bottom Solid Layers: **2**
* Infill density: **15%**
* Infill pattern: **Honeycomb**
* Skirt: **1**
* Brim: **0mm**
* Support: **No**

#### Detailed settings

Detailed settings are slightly different for each of the three recommended print groups **(only the attributes different from the global settings are shown)**:

1. Bottom and Insides
	* Infill density: **20%** 
	* Perimeters: **1**
	* Brim: **0mm**
	* Support: **Yes**
	* Support Pattern: **Rectilinear**
2. Walls
	* Infill density: **15%**
	* Perimeters: **1**
	* Brim: **5mm**
	* Support: **Yes**
	* Support Pattern: **Pillars**
3. Top and Display covers
	* Infill density: **20%**
	* Perimeters: **5**
	* Brim: **0mm**
	* Support: **No**

### Tips and Tricks

These tools will help you with 3D printing *(and removing the supports from the printed model)*:

3D printing tools

* When printing with ABS you HAVE TO to use the heated bed!
* The second print group (The Walls) **needs to have brim** which helps the print to stay connected to bed and not bend while printing (we use 5mm).
* The second print group (The Walls) **needs to be printed with supports** (we recommend **pillars** type if you use [Slic3r](http://slic3r.org/)).
* Best infill type is Honeycomb with 15% density for *The Walls* part which even helps to achieve the nice light reflecting effects with a semi-transparent filament.

### How it looks 3D printed

> Example print shown on the images below was printed on our *"Kanárek"* 3D printer which is a [Prusa i3 MK2 3D Printer](http://www.prusa3d.com/#our-printer) using the semitransparent [blue EasyABS-T filament](http://shop.prusa3d.com/en/filament/57-blue-easyabs-filament-1kg.html). We recomend this filament, even with a low print settings the resulting light effects looks just awesome!

Anemone Tentacle - Assembled Left Anemone Tentacle - Assembled Right 

Anemone Tentacle - Assembled Open Anemone Tentacle - Assembled with Cable

Anemone Tentacle - Running App Anemone Tentacle - Running Menu

Anemone Tentacle - Running Blink Anemone Tentacle - Running Blink on night

Because the top of the Anemone Tentacle is LEGO® compatible, you can customize your Tentacle to fit your desires with the world most famous building kit.

*LEGO® is a trademark of the LEGO Group of companies which does not sponsor, authorize or endorse this site ([trademark guidelines](http://www.lego.com/en-us/legal/legal-notice/fair-play)).*

*[#anemoneCloud](https://twitter.com/hashtag/anemoneCloud)*

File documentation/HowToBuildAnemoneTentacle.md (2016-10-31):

# How to build Anemone Tentacle

Anemone Tentacle is a DIY Open Hardware device you can build and 3D print a cute case for it.

> Tentacle is fully Open Hardware device based on Arduino YÚN and Arduino TFT Display. It can be used as part of [Anemone Platform](http://www.anemone.cloud) or completelly standalone as a nice case for Arduino YÚN and Arduino TFT display.

## How Tentacle looks like?

Anemone Tentacle Mk1 3D Visualization

> Video in better quality can be seen at [youtube](https://youtu.be/J8Jwhn_DrBI).

Anemone Tentacle - Render from right Anemone Tentacle - Render from left

Anemone Tentacle - Printed and assembled from right Anemone Tentacle - Printed and assembled from left Anemone Tentacle - Printed, assembled and running

Tentacle has three hardware controls which you can see on the following image:

Anemone Tentacle - Interactive parts

> The interactive parts are shown in black color

* The **top button** is used as a *back button* by the [Anemone arduino library](https://github.com/ceskasporitelna/anemone/tree/master/toolkit/anemone-arduino-library), but can be used in your Anemone apps as well
* The **side knob** is used as a *menu button & controller* and should not be used for any other purpose than a menu trigger and navigation
* The **front button** is used as a *cloud button* by the Anemone arduino library and it should not be used in your Anemone app at all *(the user should always have the ability to switch Tentacle to the share mode - without caring about where in your Anemone app he is currently present)*

> Of course these limitations/recomendations apply only when you use the Tentacle inside the [Anemone Platform](http://www.anemone.cloud) with the [Anemone arduino library](https://github.com/ceskasporitelna/anemone/tree/master/toolkit/anemone-arduino-library). When using the Tentacle outside of the Anemone ecosystem, feel free to repurpose all the buttons as you see fit.

## That is nice! How to build it?

In this tutorial we will guide you through the Tentacle building process.

In order to build your very own Tentacle you need to do the following:

1. Buy *(or somehow gather)* all the needed parts. See the [parts list](#parts-list).
2. Build the Tentacle core *(= put together the Tentacle electronic circuits)*
3. Build the Tentacle outer shell *(= 3D print the Tentacle case)*
4. Integrate Tentacle to into the shell *(= insert the electronic circuits into the 3D printed case)*
5. Install the Tentacle software
6. Connect your Tentacle to the [Anemone Cloud](http://www.anemone.cloud).

And that's it! ;)

## Step 1 - Gather Tentacle parts

In order to build a Tentacle you will need the following active components:

* 1x [Arduino YÚN](https://www.arduino.cc/en/Main/ArduinoBoardYun) *(+ SD card)*
* 1x [Arduino TFT LCD Display](https://www.arduino.cc/en/Main/GTFT) *(+ SD card)*
* 1x [Rotary Encoder KY-040](http://henrysbench.capnfatz.com/henrys-bench/arduino-sensors-and-input/keyes-ky-040-arduino-rotary-encoder-user-manual/) (used as a *menu knob*)
* 1x [Buzzer YL-44](https://rydepier.wordpress.com/2015/05/24/active-buzzer-alarm/)
* 1x [Microswitch TC-0108-T](https://www.gmelectronic.com/tc-0108-t) (used as a *cloud button*)
* 1x [Red Switch P-PB303B](https://www.gmelectronic.com/p-pb303b-red) (used as a *back button*)
* 2x [Green Super Flux LED 913PG2C](https://www.gmelectronic.com/super-flux-led-sfl-pure-green-2000-110-130) (used as a *back button backlight*)
* 2x [Optocoupler BPC-817C](https://www.gmelectronic.com/bpc-817c) *(or similar working with 5V input/output voltage)*
* 2x Resistor 220 Ohm
* 2x Resistor 10 Kiloohm

Anemone Tentacle - Needed parts

And the following passive parts:

* 1x [Prototype Shield with Small Breadboard](https://goo.gl/QiYypK)
* 1x [Stripboard Single Side PCB 5x7cm](https://goo.gl/bP6dKk)
* 1x [RJ-11 Connector Box WEBP 6-4 LP 833-045](https://goo.gl/kE05f0) *(for I2C bus output)*
* 1x [Insulated wire on coil 0,4mm/25m Blue](https://goo.gl/lk7bCX)
* 1x [Breadboard Connectors PROSKIT OP-E351](https://goo.gl/8ECFLD)
* 1x [Female Headers Row 40](https://goo.gl/bsTJQJ)
* 1x [Male Headers Row 20 Straight](https://goo.gl/MwZm9u)
* 1x [Male Headers Row 20 90-deg](https://goo.gl/N3jrON)
* 15x [Jumper Wire M-F 10cm](https://goo.gl/9HJ0Yd)
* 10x [Jumper Wire M-M 10cm](https://goo.gl/9HJ0Yd)
* 3x [Jumper Wire M-F 20cm](https://goo.gl/QxP5vw)

Anemone Tentacle - Needed wires Anemone Tentacle - Needed tools

### Parts List

In order to make your life easier we have prepared a list of links where you can buy all the Tentacle parts:

> This is just a hint ;). All the parts are **Open Hardware** you can buy them in your favorite shop, local hardware store, etc. 

| # | Part | Where to buy in Czech Republic* | Where to buy Worldwide | Cost |
|:--- |:--- |:---:|:---:| ---:|
| 1x | Arduino YÚN | https://goo.gl/WWNbBz | https://goo.gl/zxKTJE | €68.20 |
| 1x | Arduino TFT LCD Display | https://goo.gl/UJ5RQx | https://goo.gl/QMAZtW | €20.90 |
| 1x | Rotary Encoder KY-040 | https://goo.gl/HBKuvv | https://goo.gl/aWtrAF | €0.50 |
| 1x | Buzzer YL-44 | https://goo.gl/Eo4EEE | https://goo.gl/2WzGYW | €0.43 |
| 1x | Microswitch TC-0108-T | https://goo.gl/ncyT34 | https://goo.gl/iff8Z7 | €0.13 |
| 1x | Red Switch P-PB303B | https://goo.gl/mJq2Rl | https://goo.gl/SXAANZ | €0.45 |
| 2x | Green Super Flux LED 913PG2C | https://goo.gl/e5RzAD | https://goo.gl/xWg07e | €0.40 |
| 2x | Optocoupler BPC-817C | https://goo.gl/SSWsRn | https://goo.gl/BFo84T | €0.30 |
| 2x | Resistor 220 Ohm | - | - | 
| 2x | Resistor 10 Kiloohm | - | - | 
| 1x | Prototype Shield with Small Breadboard | https://goo.gl/Pvyxjw | https://goo.gl/QiYypK | €1.00 |
| 1x | Stripboard Single Side PCB 5x7cm | https://goo.gl/zTTTuU | https://goo.gl/bP6dKk | €1.26 |
| 1x | RJ-11 Connector Box WEBP 6-4 LP 833-045 | https://goo.gl/p4YbLA | https://goo.gl/kE05f0 | €0.25 |
| 1x | Insulated wire on coil 0,4mm/25m Blue | https://goo.gl/AbCSSo | https://goo.gl/lk7bCX | €2.20 |
| 1x | Breadboard Connectors PROSKIT OP-E351 | https://goo.gl/OA5zfP | https://goo.gl/8ECFLD | €12.29 |
| 1x | Female Headers Row 40 | https://goo.gl/Ps4XRd | https://goo.gl/bsTJQJ | €0.34 |
| 1x | Male Headers Row 20 Straight | https://goo.gl/Dz5Kux | https://goo.gl/MwZm9u | €0.23 |
| 1x | Male Headers Row 20 90-deg | https://goo.gl/94bT0B | https://goo.gl/N3jrON | €0.34 |
| 1x | Jumper Cables M-M, M-F, F-F, 40pcs, 10cm | https://goo.gl/WffkiF | https://goo.gl/9HJ0Yd | €3.45 |
| 1x | Jumper Cables M-M, M-F, F-F, 40pcs, 20cm | https://goo.gl/buLGLN | https://goo.gl/QxP5vw | €2.17 |
| | | | **Total** | **€114.84** |

**The Anemone platform (as well as the Tentacle) has been developed with love in [Prague](https://goo.gl/maps/gx7orLWymPA2), so people from our country have special buying options column ;)*

> You can download the [Anemone Tentacle parts list as CSV file](https://github.com/ceskasporitelna/anemone/blob/master/documentation/files/anemone-tentacle-parts.csv) or as [PDF file](https://github.com/ceskasporitelna/anemone/blob/master/documentation/files/anemone-tentacle-parts.pdf).
 
### Tools

Regarding the tools needed, we would recommend the following:

* Soldering station *(for example [Hakko FX-888D](https://www.hakko.com/english/products/hakko_fx888d.html))*
* Leadless soldering iron
* Tweezers *(for example a [set from VETUS](https://www.aliexpress.com/wholesale?catId=0&SearchText=vetus+tweezers+6pcs))*
* [Third hand soldering iron stand](https://www.aliexpress.com/wholesale?catId=190405&SearchText=third+hand+soldering)
* Cable insulation remover
* Knife
* Multi-Meter

Anemone Tentacle - Needed tools

### Minimal Tentacle (optional)

> If you plan to use Tentacle just readonly, there is a way to build what we call "a minimal Tentacle". Which is a striped version of Tentacle which consist only from Arduino YÚN, TFT display and a *cloud button*.

Anemone Minimal Tentacle - Wiring Anemone Minimal Tentacle - Wiring

With minimal Tentacle, you will not be able to use Tentacle fully, but it is enought to use it in readonly mode. And it still retains the share to guests functionality.

Anemone Minimal Tentacle - Needed parts

For a minimal Tentacle, you will need the following:

> A minimal Tentacle is NOT compatible with the 3D printed Anemone Tentacle case (the case assumes that you have the original Anemone Tentacle, hence in case of minimal Tentacle, you will miss many parts).

#### Minimal Tentacle Parts List

| # | Part | Where to buy in Czech Republic* | Where to buy Worldwide | Cost |
|:--- |:--- |:---:|:---:| ---:|
| 1x | Arduino YÚN | https://goo.gl/WWNbBz | https://goo.gl/zxKTJE | €68.20 |
| 1x | Arduino TFT LCD Display | https://goo.gl/UJ5RQx | https://goo.gl/QMAZtW | €20.90 |
| 1x | Microswitch TC-0108-T | https://goo.gl/ncyT34 | https://goo.gl/iff8Z7 | €0.13 |
| 1x | Optocoupler BPC-817C | https://goo.gl/SSWsRn | https://goo.gl/BFo84T | €0.30 |
| 1x | Resistor 220 Ohm | - | - | 
| 1x | Resistor 10 Kiloohm | - | - | 
| 1x | Jumper Cables M-M, M-F, F-F, 40pcs, 20cm | https://goo.gl/buLGLN | https://goo.gl/QxP5vw | €2.17 |
| | | | **Total** | **€91.70** |

> You can download the [Minimal Tentacle parts list as CSV file](https://github.com/ceskasporitelna/anemone/blob/master/documentation/files/minimal-tentacle-parts.csv) or as [PDF file](https://github.com/ceskasporitelna/anemone/blob/master/documentation/files/minimal-tentacle-parts.pdf).

## Step 2 - Build Tentacle electronic circuits

The Anemone Tentacle electronic circuit has the following scheme:

Anemone Tentacle - Electrical Circuit Scheme

The **simplified** wiring image looks like this:

> In order to let you understand the Tentacle wiring better, we have created a simplified wiring image. In this image we have **removed all passive components** *(like a prototype shield or stripboard)* and have replaced them by a classic breadboard.
 
Anemone Tentacle - Simplified Electrical Circuit Wiring

In addition we have created an image where the `VCC` (5V) is shown as a **Red wire**, VCC (3.3V) is shown as a **Pink wire** and `GND` as a **Black wire**.

Anemone Tentacle - Simplified Electrical Circuit Wiring VCC GND

The final *(not simplified)* wiring of a Tentacle then looks like this:

Anemone Tentacle - Electrical Circuit Wiring

And this is how Tentacle looks like this when assembled *(without the case)*:

TODO assemled Tentacle image

> These assebled electrical circuits should the be put inside the *Anemone Tentacle Case* which is described later below.

Below we will explain the Anemone Tentacle wiring construction **step by step**.

### Step 2.1 - Introduction

Before we move further, in order to avoid confusion, lets explain how some components shown on our breadboard wiring image look like in reality.

#### Buzzer YL-44

The *Buzzer YL-44* looks like this.

Anemone Tentacle - Where buzzer YL-44 is o the wiring image

#### Rotary Encoder KY-040

The *Rotary Encoder KY-040* looks like this.

Anemone Tentacle - Where buzzer YL-44 is o the wiring image

#### Arduino Prototype Shield

The grey wires mess is in fact the *Arduino Prototype Shield* pluged to Arduino YÚN.

Anemone Tentacle - Where buzzer YL-44 is o the wiring image

#### RJ-11 I2C Bus Socket

The RJ-11 socket is used as an output for I2C bus.

Anemone Tentacle - Where buzzer YL-44 is o the wiring image

#### Arduino TFT Display

What looks like some Adafruit Display is in fact the original *Arduino TFT Display*. We were just not able to find better part in Fritzing for it.

Anemone Tentacle - Where buzzer YL-44 is o the wiring image

And the rest is as it seems to be. A few resistors, optocouplers, buttons and LEDs.

### Step 2.2 - *Plug-and-Play* components preparation

In order to make the Tentacle assemble as easy as is possible, the best way how to put it together is to first prepare what we call "*Plug-and-Play components*" and then put them together.

> This approach will play well with the cute 3D printed case for your Tentacle (if you plan to use it).

#### Step 2.2.1 - Prototype Shield Legs

As any Arduino out there the *Arduino YÚN* is compatible with **Arduino shields** *(aka boards with additional electronic circuits which can extend capabilities of your Arduino)*.

Which is exactly what we are going to do - we will extend capabilities of our Arduino YÚN by creating and later pluging into it **an Anemone Tentacle Shield**.

There is just one issue with the idea (and shields on Arduino YÚN in general) - Arduino YÚN **does not conform** to the default height of its electronic components which is exepected by the majority of Arduino shields because it features an ethernet socked which height is too large. This means that any shield you plan to use on your Arduino YÚN needs to have longer "legs" (aka pin headers).

And this is exactly the thing we need to do with our **Anemone Tentacle Shield**.

The Anemone Tentacle Shield will be based on the *Arduino Prototype Shield*.

TODO image of arduino prototype shield

Hence the first step is creation of longer legs for our shield.

In general there are two ways how you can achieve it.

1. You can de-solder the original legs on the shield and replace them with longer ones
2. Or you can build a reduction (aka something you will put between the short legs of shield and short sockets of Arduino YÚN in order to make the legs longer)

> We strongly recomend you to follow the option 2.
 
The reason is, that option 1. is **much more complicated**. First you need to own a de-soldering machine in order to be able to de-solder anything *(especially parts with more than one connection are nearly impossible to be de-soldered using a classic soldering tool)*. Second reason is that longer legs (aka jumper wire headers) are much more difficult to buy that the classic ones which you can always order from China.

So we have taken option 2. The result looks like this.

TODO image of legs

The legs can be the connected to our *Anemone Tentacle Shield*.

TODO image of legs connected to the shield.

Which can be then connected to the Arduino YÚN.

TODO image of shield connected to yun

#### Step 2.2.2 - Display Board

With the *Anemone Tentacle Shield* legs done we can move to the **Display Board** assembly.

TODO display board without components image

The **Display Board** is a very important component of the Anemone Tentacle. Its purpose is to hold the *Arduino TFT Display*, the *YL-44 Buzzer* and the *Cloud Button* together and to provide *an easy-wiring solution* of these components to the rest of the Tentacle.

The *Display Board* is based on a **Stripboard Single Side PCB 5x7cm**.

TODO empty stripboard image

On the **top side** of the stripboard we will solder the following:

1. Two lines of Jumper Wire Header Sockets which will hold the Arduino TFT Display
2. One line of 90-deg. Jumper Wire Headers which will be our connection point to the rest of the Tentacle
3. One button which will serve as the Cloud Button 
4. The YL-44 Buzzer (attached to Display Board using *hot glue*)

TODO image of top side of display board

On the **bottom side** of the stripboard we will create connections between the components. These should look like this.

TODO image of bottom side of display board

As a next step we will attach a *20cm jumper cable F-M* to the *YL-44 Buzzer*.

TODO image of display board with wire to buzzer

And next step is attaching a *10cm jumper cable F-M* to the *90-deg. Jumper Wire Headers* which will connect the Cloud Button and TFT Display to the rest of the Tentacle.

TODO image of display board with both wires

And the finale step is to attach the Arduino TFT Display *(with SD card)* to its sockets.

TODO image of completed display board

#### Step 2.2.3 - Tentacle Shield Wiring

#### Step 2.2.4 - Arduino YÚN SPI Wiring

#### Step 2.2.5 - Rotary Encoder KY-040 Wiring

#### Step 2.2.6 - Top Button Wiring

#### Step 2.2.7 - Top LEDs Wiring

#### Step 2.2.8 - I2C RJ-11 Socket Wiring

The RJ-11 socket which will be used for I2C bus looks like this when prepared to be wired:

Anemone Tentacle - I2C RJ-11 Socket prepared to be wired

### Step 2.3 - Tentacle electronic circuits assembly

#### Step 2.3.1 - Tentacle Shield

The Tentacle electronic circuits assembly starts with the **Tentacle Shield** we have prepared in *step 2.2.3*.

Anemone Tentacle - Assembly step 1 - Tentacle Shield

TODO add photo for step 1

#### Step 2.3.2 - Arduino YÚN

Next step is to connect the **Tentacle Shield** to **Arduino YÚN** with the headers (or legs) we have prepared in *step 2.2.1*.

> Wires shown as **banded** are those you should add in this step.

Anemone Tentacle - Assembly step 2 - Arduino YÚN

TODO add photo for step 2

#### Step 2.3.3 - SPI from Arduino YÚN ICSP

Next step is to wire **SPI bus from Arduino YÚN** ICSP headers to the breadboard on the *Tentacle Shield*.

> Wires shown as **banded** are those you should add in this step.

Anemone Tentacle - Assembly step 3 - SPI from Arduino YÚN ICSP

TODO add photos for step 3

#### Step 2.3.4 - Back Button

Next step is to wire **the Back Button** to the breadboard on the *Tentacle Shield*.

> Wires shown as **banded** are those you should add in this step.

Anemone Tentacle - Assembly step 4 - Back Button

TODO add photo for step 4

#### Step 2.3.5 - Rotary Encoder

Next step is to wire **the Rotary Encoder KY-040** to the *Tentacle Shield*.

> Wires shown as **banded** are those you should add in this step.

Anemone Tentacle - Assembly step 5 - Rotary Encoder

TODO add photo for step 5

#### Step 2.3.6 - RJ-11 I2C Socket

Next step is to wire **RJ-11 I2C Socket** to the breadboard on the *Tentacle Shield*.

Anemone Tentacle - Assembly step 5.5 - RJ-11 I2C Socket Board

> Wires shown as **banded** are those you should add in this step.

Anemone Tentacle - Assembly step 6 - RJ-11 I2C Socket

> As you may have already noticed, the wires from the RJ-11 socket **are currently not connected to anything on the breadboard**. We know about this and this is something what needs to be solved in future *(or what can be solved by you!)*. One possibility is to connect the wires directly to the A5 and A4 analog inputs of the Arduino YÚN *(aka I2C bus interface)* and to the VCC and GND. That will give a direct access to the I2C interface via the RJ-11 connector.
> 
> But we initally wanted to make this I2C output compatible with the *LEGO® MindStorms kit*. And that is possible but it **requires two additional pull-up resitors and some wiring**, hence the connection is not trivial and **we did not wanted to make the Tentacle more complex just for a feature which might be used by less then 10% of users**. 
> 
> That is why we have decided to left this feature for you to finish it in a way which serves best your needs. Feel free to connect the I2C interface either in a classic way, or via the *LEGO® MindStorms* compatible way.
> 
> A detailed instructions how to connect Arduino to *LEGO® MindStorms* I2C interface can be found [here](http://www.dexterindustries.com/howto/connect-the-arduino-and-the-lego-mindstorms-together/).

TODO add photo for step 6

#### Step 2.3.7 - Top LEDs

Next step is to wire **the Top LEDs** to the breadboard on the *Tentacle Shield*.

> Wires shown as **banded** are those you should add in this step.

The blue wire is `GND`.

Anemone Tentacle - Assembly step 7 - Top LEDs

TODO add photo for step 7

#### Step 2.3.8 - Buzzer

Next step is to wire **the Buzzer from the Display Board** to the *Tentacle Shield*.

First put the **Display Board** next to your **Tentacle**.

Anemone Tentacle - Assembly step 7.5 - Display Board

And then wire **the Buzzer**

> Wires shown as **banded** are those you should add in this step.

The grey wire is `VCC`.

Anemone Tentacle - Assembly step 8 - Buzzer

TODO add photos for step 8

#### Step 2.3.9 - Cloud Button

Next step is to wire **the Cloud Button from the Display Board** to the breadboard on the *Tentacle Shield*.

> Wires shown as **banded** are those you should add in this step.

The green wire is `VCC`.

Anemone Tentacle - Assembly step 9 - Cloud Button

TODO add photos for step 9

#### Step 2.3.10 - TFT Display

Next step is to wire **the Arduino TFT Display from the Display Board** to the breadboard on the *Tentacle Shield*.

> Wires shown as **banded** are those you should add in this step.

The brown wire is `VCC`, the black wire is `GND`.

Anemone Tentacle - Assembly step 10 - TFT Display

TODO add photos for step 10

> That concludes the Anemone Tentacle electronic circuits assembly process. **Congratulations!**

Your Anemone Tentacle should now look like this:

Anemone Tentacle - Assembly step 11 - Complete Tentacle Wiring

When assembled the Tentacle electronic circuits looks like this (without the case):

Anemone Tentacle - Assembled Electronic Circuits without case

> We recommend testing the Tentacle electronic circuits after inserting them into the bottom part of the **Anemone Tentacle Case** in the *Step 4*.

When put inside the bottom part of the case it looks like this:

TODO bottom tentacle part image with electronic circuits

> The Anemone Tentacle assembly instruction *(eg. how to put the electronic circuits into the 3D printed case)* are provided below.

## Step 3 - 3D print Tentacle case

Next step is to 3D print the *Anemone Tentacle case*.

> For the *How to print* Anemone Tentacle case refer to a separate page of our tutorial, see [How to print Anemone Tentacle Case](https://github.com/ceskasporitelna/anemone/blob/master/documentation/HowToPrintAnemoneTentacleCase.md).

## Step 4 - Assemble Tentacle

With the Anemone Tentacle case 3D printed and all electronic components assembled we can **approach the Anemone Tentacle assembly**.

### 4.1 Tentacle Components

Anemone Tentacle consists of the following components:

Anemone Tentacle Parts Description Left Anemone Tentacle Parts Description Right

1. Top LEDs
2. Tentacle Shield
3. Arduino YÚN
4. Display Board
5. Cloud Button
6. Buzzer YL-44
7. Arduino TFT Display
8. Top Button
9. RJ-11 I2C Socket
10. Rotary Encoder KY-040

### 4.2 Preparation

First gather all the Tentacle parts on one place in front of you.

You will need all parts of the 3D printed case.

TODO image with all parts ready for assembly

And the assembled Tentacle electronic circuits.

TODO image with Tentacle without a case

### 4.3 Assembly

When assembled your Tentacle should look like this:

Anemone Tentacle - Printed and assembled

As a last step, you should add the Top Cover:

Anemone Tentacle - Printed and assembled without top cover

And your Tentacle is ready!

Anemone Tentacle - Printed, assembled and done

In order to make your life easier, we have create a video with shows the whole Tentacle assembly process.

TODO assembly video

## Step 5 - Install Tentacle software

Before connecting your Arduino ÝUN to the USB for the first time and following instructions in this tutorial, **we strongly recomend you read the following parts of the official documentation** from Arduino:

* https://www.arduino.cc/en/Main/ArduinoBoardYun
* https://www.arduino.cc/en/Guide/ArduinoYun

### Step 5.1 - Update Arduino YÚN OpenWRT image

We need to be sure to use the latest version of Arduino YÚN image. 
Follow the instructions on https://www.arduino.cc/en/Tutorial/YunSysupgrade to install latest OpenWRT image on your Arduino YÚN.

### Step 5.2 - Connect Arduino YÚN to Internet

As a next step, make sure that your Arduino YÚN is connected to the internet - either by Wi-Fi or Ethernet.

You can check if your Arduino YÚN is connected to Internet either from it's web control panel, or by SSHing to it and executing something like this:

```bash
ping www.google.com
```

or if you like you can verify connection to the *Anemone Cloud* by:

```bash
ping www.anemone.cloud
```

## Step 6 - Connect Tentacle to Anemone Cloud

> Please check if your Tentacle is connected to Internet **before advancing in the tutorial**. You will not be able to do this step without having your Arduino YÚN connected to the Internet.

### Step 6.1 - Sign up to the Anemone Cloud

Open the [Anemone Cloud Sign up page](http://www.anemone.cloud/users/sign_up) and perform a free registration.

Anemone Cloud - Sign up

### Step 6.2 - Create new Tentacle on Anemone Cloud

After signing up you will see (empty) *list of your Anemone apps* a.k.a **your dashboard**.

Anemone Cloud - Dashboard

You need to *press the New button* in the left menu under the *Tentacles* section.

Anemone Cloud - Press New button in the left menu under the Tentacles section

Now you should *fill your Tentacle name*.

Anemone Cloud - Fill Tentacle name

And finaly press the *Add a new Tentacle* button.

Anemone Cloud - Add a new Tentacle

Your new Tentacle is *successfully created*. Nice job! ;)

Anemone Cloud - Tentacle is created

### Step 6.3 - Download `tentacle.sh` from Anemone Cloud

You can download the `tentacle.sh` initialization script **from the list of Tentacles** in your *Anemone Cloud Administration*.

Just click on the **"Download Arduino initializer script"** link *next ot your Tentacle* in the list.

> It is important to download the right *initializer script*! Every Anemone Tentacle has its own. Only owner of a Tentacle can download its *initializer script*. Guests are not allowed to do this.

Anemone Cloud - Download tentacle.sh

### Step 6.4 - Run `tentacle.sh` on your Tentacle via SSH

Enter the folder where you have the downloaded the `tentacle.sh` and perform this command in terminal:

```bash
ssh root@tentacle.local 'sh -s' < tentacle.sh
```

> You will be asked to enter the Arduino YÚN password. The default password is `arduino`. And it can be changed in Arduino YÚN WebAdmin panel.

Where `tentacle.local` is your Tentacle (Arduino YÚN). We have named our Arduino YÚN *"Tentacle"* do it now has domain name `tentacle.local`.

> By default Arduino YÚN has domain name `arduino.local`. On Windows machines you might not be able to connect to your Arduino YÚN using its domain name. In that case, use its IP address instead.

You can find the IP address of your Arduino YÚN from its WebAdmin panel or by using the `nmap` cli tool:

```bash
nmap -sP 192.168.1.0/24
```

Where `192.168.1.0` is your network IP address.

> You can find your network IP address *usually* by taking your machine IP address and replace the last number with 0.

The Tentacle initialization script (`tentacle.sh`) will perform the following on your Tentacle:

1. It will install the Ruby programming language on your Tentacle (which is needed by the Linux part of the [Anemone Arduino Library](https://github.com/ceskasporitelna/anemone/tree/master/toolkit/anemone-arduino-library))
2. It will download all needed parts of the Anemone ecosystem from Anemone Cloud and install them on your Tentacle
3. It will perform the OTA update and install the Initial Anemone sketch to your Tentacle
4. It will register the newly created Tentacle with the Anemone Cloud

After these steps your Tentacle will be up and running.

Anemone Tentacle UI - Ready for app installation

> While running the Tentacle initialization script (`tentacle.sh`) is printing to the console what it is currently doing. So you can check its progress in the SSH console of your Tentacle.
> 
> Please be patient, the **Arduino YÚN is a very slow device** and the first Tentacle initialization **can take up to 40 minutes**.
> 
> In case of problems or questions, please refer the [FAQ in Platform Overview](https://github.com/ceskasporitelna/anemone#faq).

Arduino YÚN is able to **very often corrupt its memory and completely freeze**. *The Anemone platform is prepared to this* and in this case you can save the situation by performing the following:

1. Try to SSH to your Tentacle, if that is still possible, run there the Tentacle initialization script (`tentacle.sh`) again (if you do not have it, feel free to download it again from Anemone Cloud). The `tentacle.sh` is designed to be [idempotent](https://en.wikipedia.org/wiki/Idempotence) *(which simply means that it is OK to run it multiple times)*. `tentacle.sh` will initialize the Tentacle once again, and once again will install the *Initial Sketch*. But after 60s in its update period the *Initial Sketch* will automatically detect that some Anemone App is already installed on the Tentacle and will automatically perform the OTA to it. And because the Anemone App state *(= its variables)* is always stored in Anemone Cloud, your app will be back up with all its data. This should solve you issue.
2. If the hints from step 1. did not help *(probably because the Tentacle/Arduino YÚN is no longer responding to anything, including SSH)*, try to turn the Tentacle off and on (by cutting power to it - do not rely on the onboard reset buttons). When you plug it to power again, wait till the Arduino YÚN completes its booting - it will turn on the **white LED** on its surface - **it takes around 5 mins**. Now your Tentacle might resume its normal operations (that means that your Anemone App should boot up). If not, try if at least the SSH is working and follow instructions from step 1.
3. If even hints from step 2. were not helpful, your Arduino YÚN went completely stuck *(this happened multiple times to us durring the development of the platform ;))*. In this case nothing else than a **YÚN linux image reset** will help you. Follow instructions on the [official tutorial how to reset Arduino YÚN linux image](https://www.arduino.cc/en/Tutorial/YunSysupgrade). That usually helps. When done, follow with instructions from the step 1.

## Step 7 - *(Optional)* Install the "Juicy Day" example Anemone App on Tentacle

When your Tentacle is up and ready, you should see the following image on your Tentacle display:

Anemone Tentacle UI - Ready for app installation

Now you can open the *Anemone Cloud Administration* and from the list of apps select one app and install it to your Tentacle.

After installing the app, you should be able to access the app's *User Interface* in the *Anemone Mobile Client* iOS or Android app on your smartphone.

After 60s your Tentacle should initiate the *OTA update* and install the desired app.

Anemone Tentacle UI - Juicy Day Currency Converter

> When performing the OTA update, Tentacle will turn off its display. **This is normal**. The OTA update will take some time to the slow Arduino YÚN. So if after 10s your Tentacle will still "look like unresponsive", don't panic and let it finish the OTA update. **It can take up to 5 minutes**. In case of issues, refer the [FAQ](https://github.com/ceskasporitelna/anemone#faq).

After another 60s at the latest Tentacle should synchronize app variables with the Cloud.

And now you are done ;).

## What next?

When you have your Tentacle up and ready and you have played with the example app *Juicy Day*, you should read the [How to make Anemone App](https://github.com/ceskasporitelna/anemone/blob/master/documentation/HowToMakeAnemoneApp.md) tutorial and **make your first very own Anemone App**.

In general, do not miss the following:

1. [Anemone Overview](https://github.com/ceskasporitelna/anemone)
2. [Sign up](http://www.anemone.cloud/users/sign_up) for free and [download the Mobile Client](http://www.anemone.cloud)
3. Read the [How to make Anemone App](https://github.com/ceskasporitelna/anemone/blob/master/documentation/HowToMakeAnemoneApp.md) tutorial
4. Read the [How to make Anemone Connector](https://github.com/ceskasporitelna/anemone/blob/master/documentation/HowToMakeAnemoneConnector.md) tutorial
5. You may be also interested in the [Anemone Apps Repository](https://github.com/ceskasporitelna/anemone/tree/master/apps), [List of available Anemone Connectors](https://github.com/ceskasporitelna/anemone/tree/master/connectors) and [Anemone Arduino Library documentation](https://github.com/ceskasporitelna/anemone/tree/master/toolkit/anemone-arduino-library)
6. Explore the "Juicy Day" [example Anemone App on our GitHub](https://github.com/ceskasporitelna/anemone/tree/master/apps/juicy-day)
7. Write us. Tweet about us, write on Facebook, make a blogpost. Use hashtag [#anemoneCloud](https://twitter.com/hashtag/anemoneCloud).

*LEGO® is a trademark of the LEGO Group of companies which does not sponsor, authorize or endorse this site ([trademark guidelines](http://www.lego.com/en-us/legal/legal-notice/fair-play)).*

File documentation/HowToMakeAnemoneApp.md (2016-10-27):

# How to make Anemone App

Anemone App is any application running in the [Anemone Platform](http://www.anemone.cloud).

In this tutorial we will explain how Anemone Apps work and how you can make your own.

> We maintain a [list of all Anemone Apps](https://github.com/ceskasporitelna/anemone/tree/master/apps), feel free to take a look around and get some inspiration.

## How Anemone App works

Every Anemone App consist of three parts:

1. Manifest
2. Interface
3. Sketch

Every Anemone App runs on three places (which is why it has three parts). Every part runs on given place and has a give purpose.

1. **Manifest** (aka *Cloud Logic*) defines how the app **Worker** will behave inside the *Anemone Cloud*
2. **Interface** (aka *Mobile User Interface*) defines how the app **User Interface** inside the *Anemone Mobile Client* will look like
3. **Sketch** (aka *Tentacle User Interface and Logic*) defines how the **Arduino part of the app** will behave and look like inside the *Anemone Tentacle*

> If you do not know what *Anemone Cloud*, *Anemone Mobile Client* or *Anemone Tentacle* are, take a look at the [Anemone Platform Overview](https://github.com/ceskasporitelna/anemone).

### How all the parts play together?

The part of *Anemone App* which lives *(and run)* inside the Tentacle *(= sketch)* and the part which lives *(and run)* inside the Mobile Client never talk directly to each other. 

Instead they both talk only to the part of *Anemone App* which lives *(and run)* inside the Anemone Cloud. That part is called a **Worker**.

Anemone App Communication Schema

### Variables

Every Anemone App can have a stored state. This state is represented by a set of variables. In theory Anemone App is not required to have any variable, but in that case it is not much useful.

Variables are always stored inside the **Worker** in the *Anemone Cloud*.

From there the Variables can be accessed either from Tentacle (by the app sketch) or from the Mobile Client (by the app interface).

Variables can be accessed from both places in **read** or **write** mode *(if that is allowed by the app manifest file)*.

### Components

Every Anemone App is **explicitly defined by the three components**.

* *Mobile User Interface* is defined by an **interface.json** file
* *Cloud Logic* is defined by an **manifest.json** file
* *Tentacle User Interface and Logic* is defined by **arduino .ino sketch** which uses our [Anemone Arduino Library](https://github.com/ceskasporitelna/anemone/tree/master/toolkit/anemone-arduino-library)

Now lets take a bit *deeper* look on the individual components.

#### Mobile User Interface (interface.json)

The *interface.json* file describes list of **input** or **output** components which together form the user interface of Anemone App which is shown inside the Mobile Client when your Anemone App is open.

Thought this interface you can either read data from your Anemone App or provide data input. All data are in fact loaded and stored to the Anemone Cloud (from where the Tentacle will load them).

When defining the Anemone App Mobile User Interface you can use set of prepared components.

Interface of your Anemone App can look like this:

Anemone App Interface Example

In order to make this Mobile User Interface, you need to create an **interface.json** file which can look like this:

```json
{
  "platform": {
    "appId": "juicy-day",
    "driver": "anemone",
    "type": "interface",
    "version": 1
  },
  "input": {
    "inCostCzk": {
      "type": "numberField",
      "label": "Cost in CZK"
    }
  },
  "output": {
    "outCostEur": {
      "type": "numberLabel",
      "label": "Cost in EUR"
    }
  }
}
```

> You can find more information about creation of *interface.json* files for Anemone Apps in our [How to define Anemone App User Interface in interface.json](https://github.com/ceskasporitelna/anemone/blob/master/documentation/HowToMakeAnemoneApp.md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) tutorial.

#### Cloud Logic (manifest.json)

The *manifest.json* file describes list of **variables** and **bindings** which together form the cloud component of every *Anemone App*.

##### Variables

Every *variable* has a **name** and **data type**. And in addition an information whenever it is **readable** (get) or **writeable** (set) from the *Tentacle* (the readability and writeablity from the Mobile Client is defined on other place of the *manifest.json* - in *bindings*).

```json
{
  "variables": {
    "varCostCzk": {
      "dataType": "float",
      "get": true,
      "set": false
    },
    "varCostEur": {
      "dataType": "float",
      "get": true,
      "set": false
    }
  }
}
```

##### Bindings

The second part of the *manifest.json* file contains the list of bindings. There are two types of bindings - user **interface** bindings and cloud **connectors** bindings.

```json
{
  "bindings": {
    "interface": {
    },
    "connectors": {
    }
  }
}
```

User interface bindings (defined inside the "interface" section) describe **bindings of variables to user interface components of Mobile User Interface** defined in *interface.json*.

```json
{
  "bindings": {
    "interface": {
      "bindCostInCzk": {
        "variable": "varCostCzk",
        "from": "inCostCzk"
      },
      "bindCostInEur": {
        "variable": "varCostEur",
        "to": "outCostEur"
      }
    },
  }
}
```

The connectors bindings (defined inside the "connectors" section) describe **bindings of variables to Anemone Cloud Connectors**.

Connector is a component of Anemone Cloud which provides access to other web services (like Twitter of CSAS WebAPI).

Connectors are integrate in the Anemone Cloud. List of all existing connectors can be found [here](https://github.com/ceskasporitelna/anemone/tree/master/connectors). You can [create new connectors based on our manual](https://github.com/ceskasporitelna/anemone/blob/master/documentation/HowToMakeAnemoneConnector.md).

The connector definition look like this:

```json
{
  "bindings": {
    "connectors": {
      "exchangeRate": {
        "connector": "exchangeRate",
        "variable": "varCostCzk",
        "args": {
          "apiKey": "INSERT YOUR API KEY HERE"
        },
        "output": {
          "variables": [
            "varCostEur"
          ]
        }
      }
    }
  }
}
```

The complete *manifest.json* file can look like this:

```json
{
  "platform": {
    "appId": "juicy-day",
    "driver": "anemone",
    "type": "manifest",
    "version": 1
  },
  "variables": {
    "varCostCzk": {
      "dataType": "float",
      "get": true,
      "set": false
    },
    "varCostEur": {
      "dataType": "float",
      "get": true,
      "set": false
    }
  },
  "bindings": {
    "interface": {
      "bindCostInCzk": {
        "variable": "varCostCzk",
        "from": "inCostCzk"
      },
      "bindCostInEur": {
        "variable": "varCostEur",
        "to": "outCostEur"
      }
    },
    "connectors": {
      "exchangeRate": {
        "connector": "exchangeRate",
        "variable": "varCostCzk",
        "args": {
          "apiKey": "INSERT YOUR API KEY HERE"
        },
        "output": {
          "variables": [
            "varCostEur"
          ]
        }
      }
    }
  }
}
```

> You can find more information about creation of *manifest.json* files for Anemone Apps in our [How to define Anemone App Logic in manifest.json](https://github.com/ceskasporitelna/anemone/blob/master/documentation/HowToMakeAnemoneApp.md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) tutorial.

#### Tentacle User Interface and Logic (arduino .ino sketch) 

The last component of Anemone App is the one which will run on a Tentacle.

This component is in fact an normal **arduino .ino sketch** file which runs on the *Arduino YÚN* which is "the brain" of a Tentacle.

In order to make the development of Anemone sketches easier, we have prepared the [anemone arduino library](https://github.com/ceskasporitelna/anemone/tree/master/toolkit/anemone-arduino-library) and default [Tentacle user interface components and screens](https://github.com/ceskasporitelna/anemone/blob/master/documentation/HowToMakeAnemoneApp.md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).

> You can find more information about creation of *arduino sketch* files for Anemone Apps in our [How to create Anemone App Sketch in Arduino IDE](https://github.com/ceskasporitelna/anemone/blob/master/documentation/HowToMakeAnemoneApp.md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) tutorial.

## How to create new Anemone App

In order to create an **Anemone App** you need to do the following:

1. Define Anemone App Logic in *manifest.json*
2. Define Anemone App User Interface in *interface.json*
3. Create Anemone App Sketch in Arduino IDE
4. Register Anemone App in the Anemone Cloud Administration
5. Test the app on your Tentacle
6. Submit the app for Review in the Anemone Cloud Administration
7. If you want to release your Anemone App as **Open Source** *(which is a great way how to help others)*, push your app source files as a pull request to the [Anemone Apps Repository](https://github.com/ceskasporitelna/anemone/tree/master/apps), we will review it an accept.

Now lets take a closer look on the individual steps.

### How to define Anemone App Logic in *manifest.json*

> You can use **Connectors** as a part of your *Anemone App Logic*. You can find all available connectors in our [list of Anemone Connectors](https://github.com/ceskasporitelna/anemone/tree/master/connectors). Do you miss a connector for your favorite Web API? [Create it](https://github.com/ceskasporitelna/anemone/blob/master/documentation/HowToMakeAnemoneConnector.md).

### How to define Anemone App User Interface in *interface.json*

### How to create Anemone App Sketch in Arduino IDE

#### Tentacle user interface components and screens

Below you can find some examples and conventions of Anemone Apps **Tentacle screens design**.

> When designing screens for the Tentacle part *(= sketch)* of your Anemone App **be simple**. You need to be aware the fact that Arduino YÚN has terrible refresh rate of its TFT Display, especially in case of drawing images from SD card.
> 
> In general there are two ways how you can handle Anemone App visuals on a Tentacle.
> 
> 1. You can use .bmp image files stored on SD card. But drawing big bitmaps on the TFT will take some time to the Arduino. **The drawing of a image is visible!** And since you need images on SD card, you will basically sacrifice the OTA update feature. You users will sudenly need to copy some image to the SD card of their Tentacle before they will be able to use your app.
> 2. Which brings us to the second approach how you can handle the issue. You can limit yourself just to basic graphics *(ideally just consisting from bunch of colored rectangles)* and draw these directly in code of your sketches.
> 
> **We strongly recommend you to use the option 2.** That is what we have done in the [Juicy Day example Anemone App](https://github.com/ceskasporitelna/anemone/tree/master/apps/juicy-day). And as you can see, it looks nice.

##### Anemone Tentacle Screens

The following screens will be accesible by your Anemone App by using the [Anemone Arduino Library](https://github.com/ceskasporitelna/anemone/tree/master/toolkit/anemone-arduino-library).

*Ready for App*

Anemone Tentacle UI - Ready for app installation 

This screen indicates that Tentacle is **ready to load some Anemone App by OTA update** in the next *Cloud Synchronization* cycle (which happens every 1 minute).

--

*Generating Guest Code*

Anemone Tentacle UI - Generating guest code 

This screen is shown when user presses the **Cloud Button** and Tentacle *is generating a guest code*. 

> This screen will be automatically replaced by the next one when the guest code *is generated* and sent to the *Anemone Cloud*. The guest code generation *can be cancelled* by pressing the **Back Button** in the top of the Tentacle.

--

*Share Mode*

Anemone Tentacle UI - Share mode 

This screen is shown when user presses the **Cloud Button** and Tentacle *successfully generated a guest code*. When this screen is shown, the Tentacle is in the **Share Mode**.

While Tentacle is the **Share Mode**, every user *who is not owner or guest to this Tentacle already* can enter the guest code shown to his Anemone Mobile Client and became a guest to this Tentacle.

> The share mode is valid only for the first user.

The Share Mode can be cancelled by pressing the by pressing the **Back Button** in the top of the Tentacle.

> This screen will be automatically replaced by the next one when the guest code *will expire*. That will happen when the on-screen timer will reach zero.

--

*Guest Code Expired*

Anemone Tentacle UI - Guest code expired 

This screen is shown when Share Mode is cancelled or when the generated Guest Code expires.

> This screen will be automatically replaced by a Dashboard of the installed Anemone App in few seconds.

--

##### Your Anemone App Screens

The following screens are examples how screens *in your Anemone App* can look like.

*Dashboard*

Anemone Tentacle UI - Juicy Day Currency Converter 

Dashboard of your application can look like this *(but it does not have to)*. 

The Dashboard screen on the image above was taken from the [Juicy Day example Anemone App](https://github.com/ceskasporitelna/anemone/tree/master/apps/juicy-day).

> You can notice thow the top *solid black header* improves user the orientation on the screen and gives *a clean difference* between the input and output data areas in this case.

--

*Cloud Synchronization*

Anemone Tentacle UI - Cloud Synchronization in progress 

When the Tentacle will be performing the **Cloud Synchronization** *(cheking if it should perform the OTA update and syncing values of all variables)* it will **be unresponsive for few moments** *(because the microcontroller it contains does not support any sophisticated form of multi-tasking)*. The Tentacle will inform the user about this state by showing two blue and yellow lines in the top and bottom of the screen. When the **Cloud Synchronization** will complete, the lines will dissapear.

> The screen on the image above was taken from the [Juicy Day example Anemone App](https://github.com/ceskasporitelna/anemone/tree/master/apps/juicy-day).

--

*Menu*

Anemone Tentacle UI - Menu

Every Anemone App can *(and should)* have **a menu**. Menu can contain two or more *menu items*. Every *menu item* should have a *name* and *icon* for the selected and for the deselected state.

The menu is shown when the *Menu Knob* on the right side of Tentacle **is pressed**. Menu items can be selected by **rotating** the **Menu Knob** up or down. By presing the *Menu Knob* the selected menu item **is invoked**. Menu screen can be **dismissed** by pressing the *Back Button* on the top of the Tentacle.

> The screen on the image above was taken from the [Juicy Day example Anemone App](https://github.com/ceskasporitelna/anemone/tree/master/apps/juicy-day).

### How to register Anemone App in the *Anemone Cloud Administration*

> When uploading `.hex` file of your Anemone App sketch, **please always upload the version WITHOUT the bootloader!** Tentacle will append the bootloader automatically while performing the OTA update.
> 
> Uploading a `.hex` file with bootloader **will not work**. You will be able to *upload it to Anemone Cloud*, but the subsequent OTA update of the Tentacle **will fail**.

### How to test the app on your Tentacle

We strongly recommend you to test your Anemone App sketch on the Tentacle directly **by uploading it by serial connection** from the *Arduino IDE*.

When something will be bad and you will **have a bug in your sketch**, the Tentacle **might not be able to perform the OTA** any longer.

In that case uploading a fixed sketch by serial interface in *a classic Arduino way* usually helps.

When your sketch will work as you wanted on your Tentacle, then it is time to upload its `.hex` file to the Anemone Cloud and try to perform a *OTA update* to it.

### How to Submit the app for Review in the Anemone Cloud Administration

When your Anemone App is tested and ready, you can **submit it for review**.

You can do this by logging into your *Anemone Cloud Administration*, and pressing the "**Submit for Review**" link next to your Anemone App.

*[#anemoneCloud](https://twitter.com/hashtag/anemoneCloud)*

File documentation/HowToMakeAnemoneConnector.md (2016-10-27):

# How to make Anemone Connector

Anemone Connector is a Ruby class which interconnect the [Anemone Platform](http://www.anemone.cloud) with other web services and REST APIs.

In this tutorial we will explain how Anemone Connectors work and how you can make your own.

> We maintain a [list of all available Anemone Connectors](https://github.com/ceskasporitelna/anemone/tree/master/connectors), feel free to take a look around and get some inspiration.

## How Anemone Connector works?

Anemone Connector is nothing else than a plain old ruby object (or class respectively).

It must be inside the `Connectors` namespace and it must inherit from the `Connectors::Base` class:

```ruby
module Connectors
  class MyCoolConnector < Base
    # ...
  end
end
```

It must define two public methods: `setup` and `call`.

```ruby
module Connectors
  class MyCoolConnector < Base
    class << self
      def setup
        # here you can perform setup of your connector if needed
      end

      # Takes 2 arguments: +input_variable_value+, and +API_KEY+
      def call(*args)
        self.setup # call() has to call setup()
        
        # ...
      end
    end
  end
end
```

The `call` method of your connector is called every time when the connector is invoked from an Anemone App.

> Connectors are invoked every time when their input variable does change its value.

*TODO: arguments of `call` method*

Lets now further explore how the code inside the `call` method should look like:

```ruby
def call(*args)
  self.setup # call() has to call setup()
  	
  # process arguments
  input = args.fetch(0) 	# value of input variable is at args[0]
  api_key = args[1] 		# API_KEY is at args[1]
  	
  # load output variables (they are passed as args[2])
  variables = args.fetch(2).fetch('variables').reduce(Hash.new) { 
    |hsh, var| hsh[var] = nil; hsh 
  }
  
  # perform connector computation ... which updates variables
  
  variables # return the updated variables
end
```

Example of a connector `MyCoolConnector` with an input variable `varInput` and two output variables `varFoo` and `varBar` which will load new values of the two variables from the api endpoint `https://some-api.com/resource` from the respective JSON properties `"foo"` and `"bar"` might look like this: 

```ruby
# Takes 2 arguments: +input_variable_value+, and +API_KEY+, the last argument is hash of output variables
def call(*args)
  self.setup # call() has to call setup()
  	
  # process arguments
  input = args.fetch(0, 0) 	# value of input variable is at args[0]
  api_key = args[1] 		# API_KEY is at args[1]
  	
  # load output variables (they are passed as args[2])
  variables = args.fetch(2).fetch('variables').reduce(Hash.new) { 
    |hsh, var| hsh[var] = nil; hsh 
  }
  
  # perform connector HTTP request
  response = HTTParty.get(
    'https://some-api.com/resource',
    headers: { 'API-KEY' => api_key }
  )
  
  # do not change variables if result was not HTTP 200 OK
  return variables if response.code != 200
  
  # parse response
  response = JSON.parse(response.body)
  
  # update variables with new values
  variables.each_key do |var|
    variables[var] = response['foo'] if var.match(/.*Foo/)
    variables[var] = response['bar'] if var.match(/.*Bar/)
  end
  
  variables # return the updated variables
end
```

The whole source code of this connector should look like this:

```ruby
require 'httparty'

module Connectors
  class MyCoolConnector < Base
    class << self
      def setup
        # here you can perform setup of your connector if needed
      end

      # Takes 2 arguments: +input_variable_value+, and +API_KEY+
      def call(*args)
        self.setup # call() has to call setup()
  	
        # process arguments
        input = args.fetch(0, 0) 	# value of input variable is at args[0]
        api_key = args[1] 		    # API_KEY is at args[1]
  	
        # load output variables (they are passed as args[2])
        variables = args.fetch(2).fetch('variables').reduce(Hash.new) { 
          |hsh, var| hsh[var] = nil; hsh 
        }
  
        # perform connector HTTP request
        response = HTTParty.get(
          'https://some-api.com/resource',
          headers: { 'API-KEY' => api_key }
        )
  
        # do not change variables if result was not HTTP 200 OK
        return variables if response.code != 200
  
        # parse response
        response = JSON.parse(response.body)
  
        # update variables with new values
        variables.each_key do |var|
          variables[var] = response['foo'] if var.match(/.*Foo/)
          variables[var] = response['bar'] if var.match(/.*Bar/)
        end
  
        variables # return the updated variables
      end
    end
  end
end
```

Such connector should have a following in it's documentation README file:

--

### Summary

| Name | Web Service | Input | Output |
|:---- |:---:|:---:|:---:|
| myCoolConnector | [SomeAPI](https://some-api.com/resource/) | input: *string* | foo: *string*, bar: *string* |

### Authentication

[SomeAPI](https://some-api.com/resource/) API key is required for authentication.

### Usage

```json
"connectors": {
  "myCoolConnector": {
    "connector": "myCoolConnector",
    "variable": "varInput",
    "args": {
      "apiKey": "INSERT YOUR API KEY HERE"
    },
    "output": {
      "variables": [
        "varFoo",
        "varBar"
      ]
    }
  }
}
```
--

We can recommend using the Ruby [httparty gem](https://github.com/jnunemaker/httparty) for HTTP REST API calls. **It is awesome**.

> When you HTTParty, you must party hard! *-- httparty post install message*

### Real world example

We will conclude this tutorial by showing a real world example of simple *Anemone Cloud Connector* **exchangeRate**. Your find more information about this connector in the [list of all available Anemone Connectors](https://github.com/ceskasporitelna/anemone/tree/master/connectors).

```ruby
require 'httparty'

module Connectors
  class ExchangeRate < Base
    class << self
      def setup
        # noop
      end

      # Takes 2 arguments: +czk_cost+, and +API_KEY+
      def call(*args)
        self.setup
        
        # process arguments
        czk = args.fetch(0, 0)
        web_api_key = args[1]
        
        # load output variables
        variables = args.fetch(2).fetch('variables').reduce(Hash.new) { |hsh, var| hsh[var] = nil; hsh }
        
        # perform connector HTTP request
        response = HTTParty.get('https://api.csas.cz/sandbox/webapi/api/v1/exchangerates',
                                headers: { 'WEB-API-key' => web_api_key }
        )
        
        # do not change variables if result was not HTTP 200 OK
        return variables if response.code != 200
        
        # parse response
        response = JSON.parse(response.body)
        eur = response.find { |currency| currency['shortName'] == 'EUR' }
        usd = response.find { |currency| currency['shortName'] == 'USD' }
        
        # update variables with new values
        variables.each_key do |var|
          variables[var] = czk/eur['valMid'] if var.match(/.*Eur/)
          variables[var] = czk/usd['valMid'] if var.match(/.*Usd/)
        end
        
        variables # return the updated variables
      end
    end
  end
end
```

## How to create Anemone Connector?

In order to create your own Anemone Connector, you just need to implement the Ruby class based on the rules and conventions described above and submit it as a pull request to this repository.

We will review it and deploy to the Anemone Cloud *(or reject ;))*.

> Currently there is no automated way of adding *Anemone Connectors* to the *Anemone Cloud*.

*[#anemoneCloud](https://twitter.com/hashtag/anemoneCloud)*

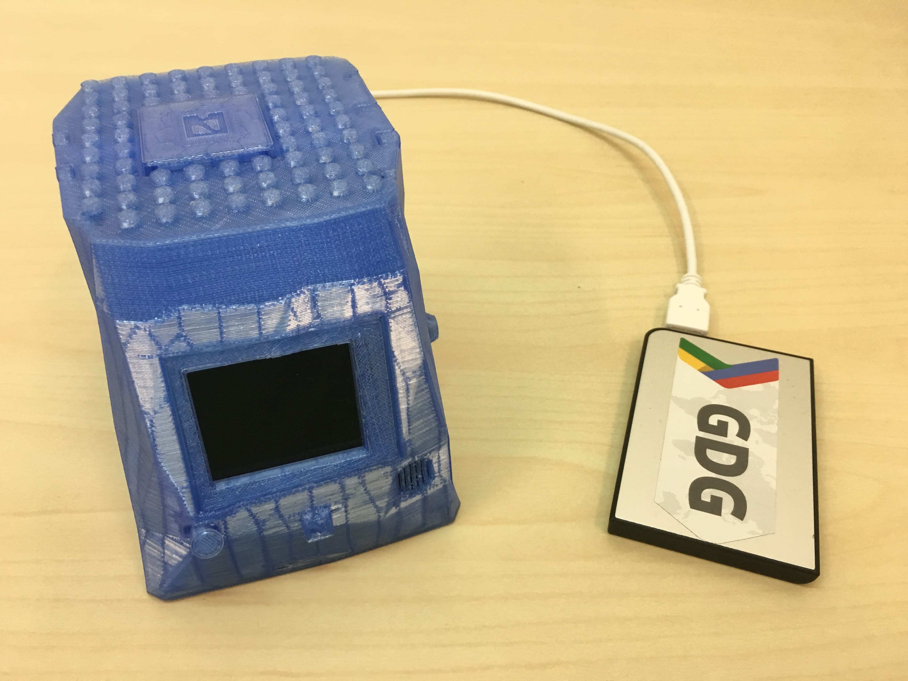
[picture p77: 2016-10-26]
documentation/images/assembled_tentacle/6_assembled_tentacle_power.jpg

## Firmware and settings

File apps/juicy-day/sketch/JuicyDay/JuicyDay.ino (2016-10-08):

/*
  Juicy Day Anemone App v1

  This sketch is example Anemone application created by the Anemone Team

  In order to run it you need to have Anemone Arduino library
  (which is distributed in Anemone.h file)

  Made with love in Prague by Juicymo s.r.o. at 2016

  @see http://www.anemone.cloud
  @see https://github.com/ceskasporitelna/anemone/tree/master/apps/juicy-day
*/

#include "Anemone.h"

// Program Constants
#define UI_LOOP_INTERVAL 5
#define TIME_UPDATE 60000

#define MENU_LABEL_APP "Convert"
#define MENU_LABEL_BEEP "Beeping"
#define MENU_LABEL_BLINK "Blinking"

// =========================================
// Variables

// Tentacle Variables
char * varCzk = "n/a";
char * varUsd = "n/a";
char * varEur = "n/a";

// Tentacle Scripts Output Parsing Variables
char * strings[3];

// Multitasking Variables
unsigned long timeUiLoop;
unsigned long timeUpdate;

// =========================================
// Interface
void setupBuzzer();
void setupScreen();
void setupMenu();
void setupHooks();
void setupMultitasking();

void loopUi();
void loopLogic();

void handleMenuConvert();
void handleMenuBeep();
void handleMenuBlink();

void parseString(char *);

void buzzerOn();
void buzzerOff();
void ledOn();
void ledOff();

void drawAppIconSelected();
void drawAppIcon();
void drawBlinkIconSelected();
void drawBlinkIcon();
void drawBeepIconSelected();
void drawBeepIcon();
void drawDashboard();
void drawMenuIcons();

// =========================================
// Implementation
void setup() {
  anemoneSetup();

  setupBuzzer();
  setupScreen();
  setupMenu();
  setupHooks();
  setupMultitasking();
}

void loop() {
  if ((millis() - timeUiLoop) > UI_LOOP_INTERVAL) {
    loopUi();
  }

  if ((millis() -  timeUpdate) > TIME_UPDATE) {
    loopLogic();
  }

  delay(10);
}

// Functions - Setup
void setupBuzzer() {
  buzzerOff();
}

void setupScreen() {
  anemoneTentacleDisplay.begin();
}

void setupMenu() {
  anemoneSetMenuIcons(&drawMenuIcons);
  
  anemoneUiAddMenuItem(MENU_LABEL_APP, ANEMONE_MENU_DASHBOARD, &handleMenuConvert);
  anemoneUiAddMenuItem(MENU_LABEL_BEEP, ANEMONE_MENU_BEEP, &handleMenuBeep);
  anemoneUiAddMenuItem(MENU_LABEL_BLINK, ANEMONE_MENU_BLINK, &handleMenuBlink);

  anemoneMenuHandles[ANEMONE_MENU_DASHBOARD]();
}

void setupHooks() {
  anemoneUiRegisterHook(ANEMONE_UI_HOOK_BUTTON_SHARE, &handleButtonShare);
  anemoneUiRegisterHook(ANEMONE_UI_HOOK_BUTTON_BACK, &handleBackButton);
  anemoneUiRegisterHook(ANEMONE_UI_HOOK_ENCODER_ROTARY, &handleEncoderRotate);
  anemoneUiRegisterHook(ANEMONE_UI_HOOK_BUTTON_ENCODER, &handleEncoderButton);
}

void setupMultitasking() {
  timeUpdate = millis();
  timeUiLoop = millis();
}

// Functions - Loop
void loopUi() {
  anemoneUiLoop();
  timeUiLoop = millis();
}

void loopLogic() {
  anemoneTentacleDisplay.stroke(39, 181, 242);
  anemoneTentacleDisplay.fill(39, 181, 242);
  anemoneTentacleDisplay.rect(0, 0, 40, 7);
  anemoneTentacleDisplay.rect(70, 0, 20, 7);
  anemoneTentacleDisplay.rect(120, 0, 40, 7);
  anemoneTentacleDisplay.rect(0, 121, 40, 7);
  anemoneTentacleDisplay.rect(70, 121, 20, 7);
  anemoneTentacleDisplay.rect(120, 121, 40, 7);

  anemoneTentacleDisplay.stroke(255, 230, 77);
  anemoneTentacleDisplay.fill(255, 230, 77);
  anemoneTentacleDisplay.rect(40, 0, 30, 7);
  anemoneTentacleDisplay.rect(90, 0, 30, 7);
  anemoneTentacleDisplay.rect(90, 121, 30, 7);
  anemoneTentacleDisplay.rect(40, 121, 30, 7);

  parseString(anemoneUiCheckUpdate());

  timeUpdate = millis();

  switch (anemoneActiveScreen) {
    case 0:
      anemoneTentacleDisplay.stroke(0, 0, 0);
      anemoneTentacleDisplay.fill(0, 0, 0);
      anemoneTentacleDisplay.rect(0, 0, 200, 7);

      anemoneTentacleDisplay.stroke(255, 255, 255);
      anemoneTentacleDisplay.fill(255, 255, 255);
      anemoneTentacleDisplay.rect(0, 121, 200, 7);
      break;

    case 1:
      anemoneTentacleDisplay.stroke(39, 181, 242);
      anemoneTentacleDisplay.fill(39, 181, 242);
      anemoneTentacleDisplay.rect(0, 0, 200, 7);

      anemoneTentacleDisplay.stroke(39, 181, 242);
      anemoneTentacleDisplay.fill(39, 181, 242);
      anemoneTentacleDisplay.rect(0, 121, 200, 7);
      break;

    case 2:
      anemoneUiShowMenu();
      anemoneSetMarked(anemoneSelectedMenuItem);
      break;

    case 3:
      anemoneTentacleDisplay.stroke(255, 255, 255);
      anemoneTentacleDisplay.fill(255, 255, 255);
      anemoneTentacleDisplay.rect(0, 0, 200, 7);

      anemoneTentacleDisplay.stroke(255, 255, 255);
      anemoneTentacleDisplay.fill(255, 255, 255);
      anemoneTentacleDisplay.rect(0, 121, 200, 7);
      break;
  }
}

// Functions - Hooks
void handleMenuConvert() {
  anemoneActiveScreen = 0;
  anemoneSelectedMenuItem = 0;

  drawDashboard();
}

void handleMenuBlink() {
  drawBlinkIconSelected();

  anemoneActiveScreen = 3;
  ledFading();
}

void handleMenuBeep() {
  anemoneActiveScreen = 3;

  drawBeepIconSelected();
  buzzerOn();
}

// Functions - Actuators
void buzzerOn() {
  digitalWrite(5, LOW);
}

void buzzerOff() {
  digitalWrite(ANEMONE_PIN_BUZZER, HIGH);
}

void ledOn() {
  analogWrite(ANEMONE_PIN_LED, 255);
}

void ledOff() {
  digitalWrite(ANEMONE_PIN_LED, 0);
}

void ledFading() {
  while (digitalRead(ANEMONE_PIN_BUTTON_BACK) == LOW) {
    for (int i = 0; i < 2; i++) {
      for (int fadeValue = 0 ; fadeValue <= 255; fadeValue += 5) {
        if (digitalRead(ANEMONE_PIN_BUTTON_BACK) == HIGH) {
          ledOff();
          return;
        }
        analogWrite(ANEMONE_PIN_LED, fadeValue);
        delay(30);
      }

      for (int fadeValue = 255 ; fadeValue >= 0; fadeValue -= 5) {
        if (digitalRead(ANEMONE_PIN_BUTTON_BACK) == HIGH) {
          ledOff();
          return;
        }
        analogWrite(ANEMONE_PIN_LED, fadeValue);
        delay(30);
      }
    }
  }
}

// Functions - Draw Graphics
void drawMenuIcons() {
  anemoneTentacleDisplay.background(255, 255, 255);
  anemoneTentacleDisplay.stroke(0 , 0, 0);

  // Draw dashboard icon
  anemoneTentacleDisplay.fill(255, 255, 255);
  anemoneTentacleDisplay.stroke(0, 0, 0);
  anemoneTentacleDisplay.rect(10, 7, 20, 20);
  anemoneTentacleDisplay.rect(22, 7, 5, 10);
  anemoneTentacleDisplay.fill(0, 0, 0);
  anemoneTentacleDisplay.rect(13, 17, 5, 10);

  // Draw beeping icon
  anemoneTentacleDisplay.fill(255, 255, 255);
  anemoneTentacleDisplay.stroke(0, 0, 0);
  anemoneTentacleDisplay.rect(10, 48, 20, 20);
  anemoneTentacleDisplay.fill(0, 0, 0);
  anemoneTentacleDisplay.stroke(255, 255, 255);
  anemoneTentacleDisplay.rect(20, 58, 8, 8);
  anemoneTentacleDisplay.rect(12, 58, 6, 6);
  anemoneTentacleDisplay.rect(20, 50, 6, 6);

  // Draw blinking icon
  anemoneTentacleDisplay.fill(255, 255, 255);
  anemoneTentacleDisplay.stroke(0, 0, 0);
  anemoneTentacleDisplay.rect(10, 91, 20, 20);
  anemoneTentacleDisplay.rect(19, 100, 6, 6);
  anemoneTentacleDisplay.fill(0, 0, 0);
  anemoneTentacleDisplay.rect(17, 98, 6, 6);
}

void drawBlinkIconSelected() {
  anemoneTentacleDisplay.fill(39, 181, 242);
  anemoneTentacleDisplay.stroke(0, 0, 0);
  anemoneTentacleDisplay.rect(10, 91, 20, 20);
  anemoneTentacleDisplay.rect(19, 100, 6, 6);
  anemoneTentacleDisplay.fill(0, 0, 0);
  anemoneTentacleDisplay.rect(17, 98, 6, 6);
}

void drawBeepIconSelected() {
  anemoneTentacleDisplay.fill(39, 181, 242);
  anemoneTentacleDisplay.stroke(0, 0, 0);
  anemoneTentacleDisplay.rect(10, 48, 20, 20);
  anemoneTentacleDisplay.fill(0, 0, 0);
  anemoneTentacleDisplay.stroke(39, 181, 242);
  anemoneTentacleDisplay.rect(20, 58, 8, 8);
  anemoneTentacleDisplay.rect(12, 58, 6, 6);
  anemoneTentacleDisplay.rect(20, 50, 6, 6);
}

void drawDashboard() {
  anemoneTentacleDisplay.background(255, 255, 255);
  anemoneTentacleDisplay.stroke(0, 0, 0);
  anemoneTentacleDisplay.fill(0, 0, 0);
  anemoneTentacleDisplay.rect(0, 0, anemoneTentacleDisplay.width(), anemoneTentacleDisplay.height() / 3);
  anemoneTentacleDisplay.setTextSize(2);

  anemoneTentacleDisplay.text("USD: ",  10, 55);
  anemoneTentacleDisplay.text("EUR: ",  10, 100);

  anemoneTentacleDisplay.stroke(255, 255, 255);
  anemoneTentacleDisplay.text("CZK", 20 , 10);
  anemoneTentacleDisplay.text(varCzk,  65, 10);

  anemoneTentacleDisplay.stroke(39, 181, 242);
  anemoneTentacleDisplay.text(varUsd,  60, 55);

  anemoneTentacleDisplay.stroke(255, 255, 255);
  anemoneTentacleDisplay.fill(255, 255, 255);
  anemoneTentacleDisplay.rect(130, 50, 30, 25);

  anemoneTentacleDisplay.stroke(247, 67, 67);
  anemoneTentacleDisplay.text(varEur,  60, 100);

  anemoneTentacleDisplay.stroke(255, 255, 255);
  anemoneTentacleDisplay.fill(255, 255, 255);
  anemoneTentacleDisplay.rect(130, 95, 30, 25);

  anemoneTentacleDisplay.rect(130, 50, 30, 25);
}

// Functions - Parsing
void parseString(char * tmp) {
  int i;
  int counter = 0;

  if (tmp != NULL || strcmp(tmp, "")) {
    strings[counter] = strtok(tmp, "\n");
    counter++;

    while ( counter < 3  ) {
      strings[counter] = strtok(NULL, "\n");
      counter++;
    }

    for (i = 0; i < 3; i++) {
      char * tmp2 = strtok(strings[i], "=");
      if (strcmp(tmp2, "varCostCzk") == 0) {
        varCzk = strtok(NULL, "\n");
        anemoneTentacleDisplay.stroke(0, 0, 0);
        anemoneTentacleDisplay.fill(0, 0, 0);
        anemoneTentacleDisplay.rect(65, 10, 80, 20);
        anemoneTentacleDisplay.stroke(255, 255, 255);
        anemoneTentacleDisplay.text(varCzk, 65, 10);
      } else if (strcmp(tmp2, "varCostEur") == 0) {
        varEur = strtok(NULL, "\n");

        anemoneTentacleDisplay.stroke(255, 255, 255);
        anemoneTentacleDisplay.fill(255, 255, 255);

        anemoneTentacleDisplay.rect(60, 100, 80, 20);
        anemoneTentacleDisplay.stroke(247, 67, 67);
        anemoneTentacleDisplay.text(varEur, 60, 100);

        anemoneTentacleDisplay.stroke(255, 255, 255);
        anemoneTentacleDisplay.rect(130, 95, 30, 25);
      } else if (strcmp(tmp2, "varCostUsd") == 0) {
        varUsd = strtok(NULL, "\n");

        anemoneTentacleDisplay.stroke(255, 255, 255);
        anemoneTentacleDisplay.fill(255, 255, 255);

        anemoneTentacleDisplay.rect(60, 55, 80, 20);
        anemoneTentacleDisplay.stroke(39, 181, 242);
        anemoneTentacleDisplay.text(varUsd, 60, 55);

        anemoneTentacleDisplay.stroke(255, 255, 255);
        anemoneTentacleDisplay.rect(130, 50, 30, 25);
      }
    }
  }
}

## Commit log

2016-09-20 How to print Anemone Tentacle Case README
2016-10-05 Improve title of connectors README
2016-10-08 Finish texts for parts list and printing manual
2016-10-08 Extract 3D print tentacle manual to separate page
2016-10-08 Add wiring images
2016-10-08 Add minimal tentacle sheme and wiring images
2016-10-08 Typo in case README
2016-10-09 Fix wire order
2016-10-09 Add connectors docs
2016-10-09 Add how to make Anemone connector tutorial
2016-10-10 Add downloadable part lists
    [anemone-tentacle-parts.csv, minimal-tentacle-parts.csv]
2016-10-17 Add assembled Tentacle image
2016-10-17 Rename assembled tentacle insides image
2016-10-17 Add Tentacle I2C RJ11 image
2016-10-17 Add more print instructions
2016-10-17 Add wired and shaded renders
2016-10-17 Add wired and shaded images reference
2016-10-17 Add 3d print tools picture
2016-10-17 Add printed images
2016-10-19 Apply EXIF JPEG orientation to pixels in printed images
2016-10-19 Add references to print group 1 photos
2016-10-19 Add reference to walls printed images
2016-10-19 Add print group 3 images references
2016-10-19 Fix print group 3 image references links
2016-10-20 Add the assembly instructions and images
2016-10-20 Add .stl model files
    [1_bottom_and_insides.stl, 2_walls.stl, 3_top_and_display_covers.stl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]
2016-10-20 Add basic Fritzing project files
    [Anemone Prototype Shield Alone.fzz, Anemone Prototype Shield with ICSP.fzz, Anemone Prototype Shield.fzz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]
2016-10-20 Add Tentacle build tutorial Fritzing project files
    [Anemone Tentacle Build 1 Tentacle Shield.fzz, Anemone Tentacle Build 10 LCD.fzz, Anemone Tentacle Build 11 Done.fzz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]
2016-10-26 Add assembled Tentacle images
2016-10-26 Add assembled tentacle alpha images
2016-10-26 Add printed images reference
2016-10-26 Add assembly images reference
2016-10-26 Add printed tentacle image to how to print guide
2016-10-27 Add printed Tentacle images reference
2016-10-27 Improve background of wired images
